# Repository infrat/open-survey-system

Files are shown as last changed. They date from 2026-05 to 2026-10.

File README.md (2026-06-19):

oss

# Open Survey System (OSS)

**Open, affordable GNSS RTK platform** that enables centimeter‑level positioning (~10 mm XY / ~50 mm Z) using commodity, readily available modules. OSS aims to democratize survey‑grade measurements by publishing open hardware, firmware, and reference configurations.

> **Status:** early draft - architecture overview only. Detailed BOMs, Gerbers, STLs, and configuration guides will be added later.

---

## 1) System Overview

OSS consists of two building blocks:

1. **RTK Rover** - a portable GNSS receiver that works with common mobile apps (e.g., SW Maps, Locus GIS, QField, SurPad, LandStar etc.). The rover receives RTK corrections via NTRIP over the Internet **or** from a local Wi‑Fi NTRIP caster.
2. **Extension Kit (LoRa)** - a radio bridge that carries RTK corrections over longer distances using LoRa (433 MHz), (eg. when local access to RTK corrections over LTE is not available):
   - **LTE/LoRa Gateway** - fetches RTK corrections from an online NTRIP service (e.g., a national CORS) or from a local RTK base, then transmits them via LoRa.
   - **LoRa/Wi‑Fi Gateway** - receives LoRa packets with RTCM and exposes a local NTRIP caster over a Wi‑Fi Access Point.
   - **Local RTK Base Station** _(optional)_ - provides local corrections based on its precisely known position (surveyed once or derived from long averaging).

---

## 2) High‑Level Architectures (Topologies)

### A) Internet‑only (no radio) - rover is used in an area with internet access to RTK corrections (eg. by LTE)

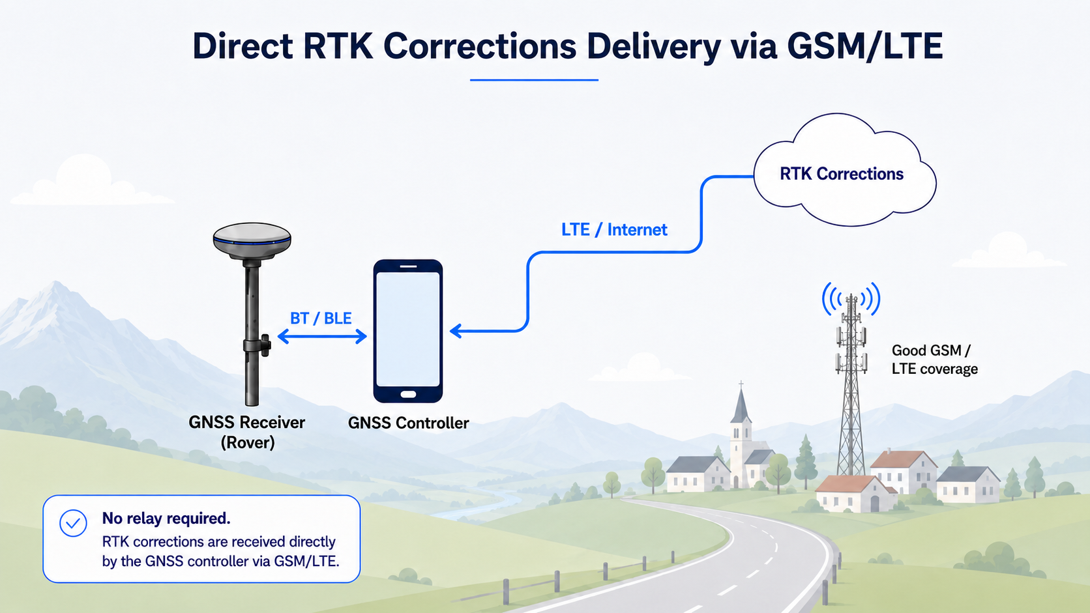
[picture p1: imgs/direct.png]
rover-only


### B) Radio‑relayed corrections (LoRa 433 MHz) - radio relay deployed in an area without internet access to RTK corrections network; corrections are calculated locally

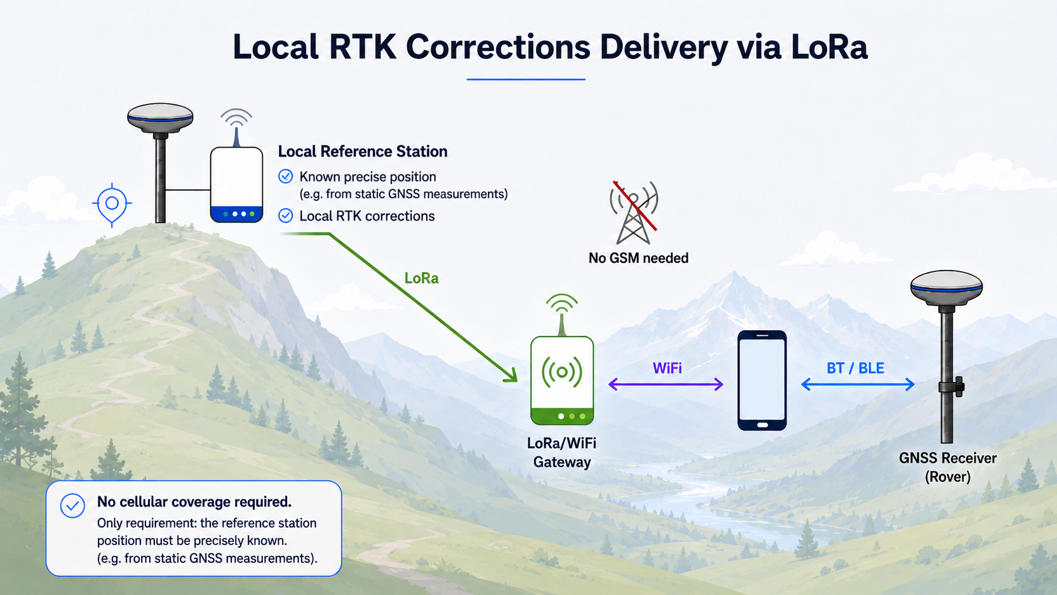
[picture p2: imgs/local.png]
rover-lora-base


### C) Hybrid (online source → local radio) - radio relay deployed in an area with internet access to RTK corrections network (over LTE/Starlink, etc.)

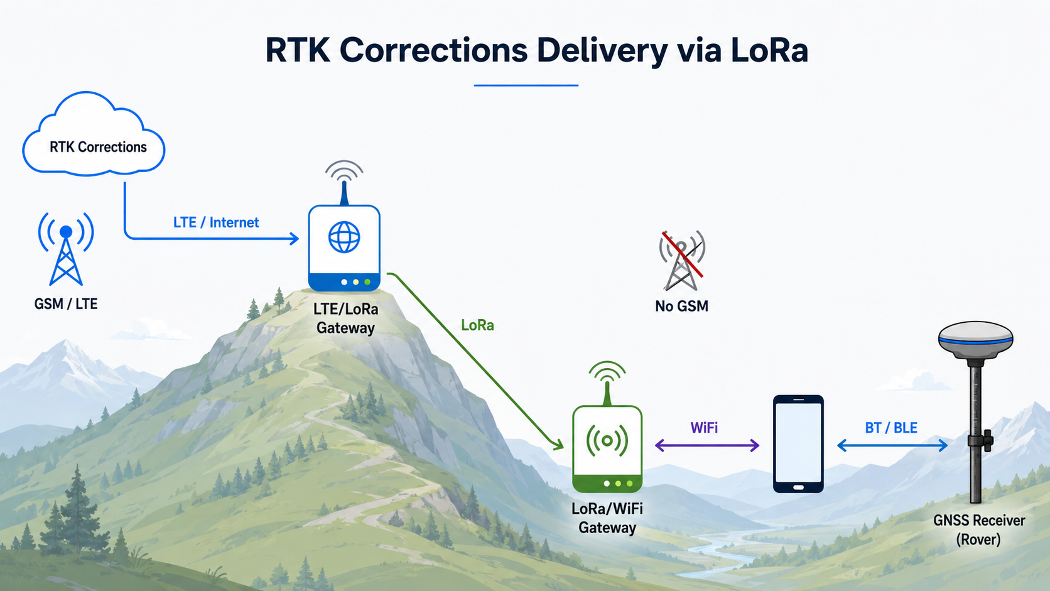
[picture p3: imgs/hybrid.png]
rover-lora


---

## 3) Component Roles

### RTK Rover

A compact, dual‑frequency GNSS RTK receiver that pairs with a mobile app. The app supplies RTK corrections (via Internet or a local NTRIP caster), while the rover provides position output to the app. Connectivity is kept simple (Bluetooth to the phone); no onboard Wi‑Fi or general‑purpose MCU is planned in the rover.

#### Enclosure

| | |
| --- | --- |
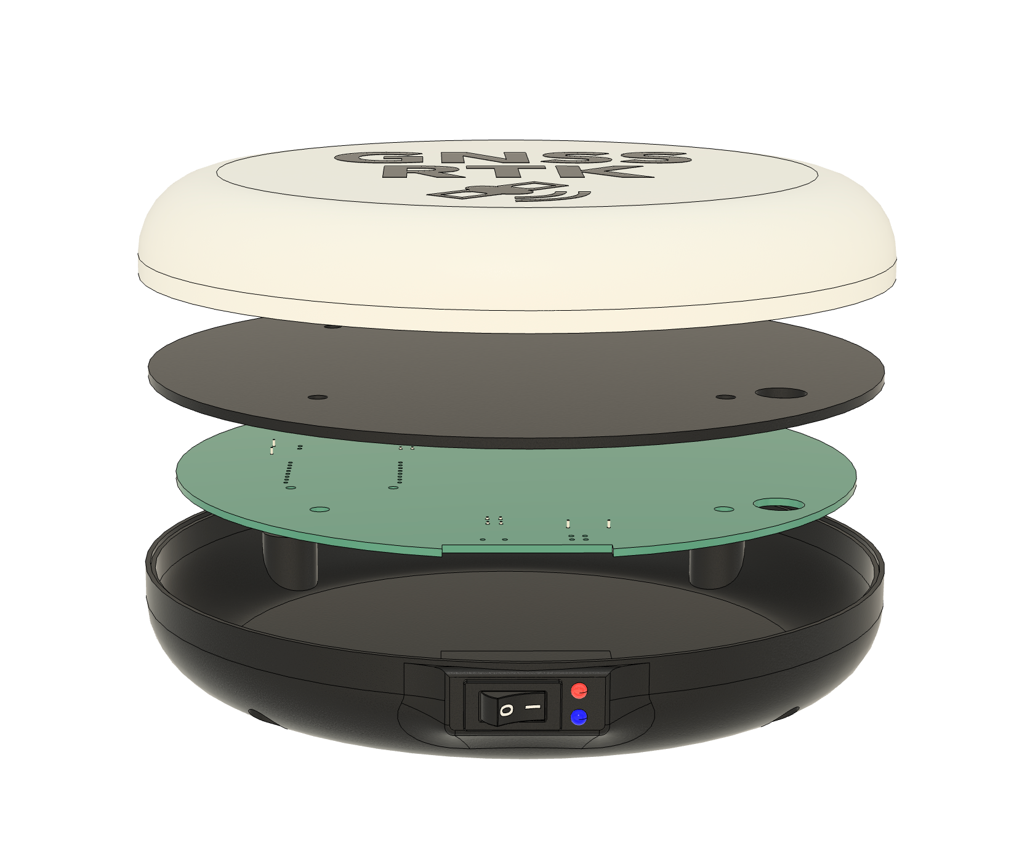
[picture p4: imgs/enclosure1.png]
enclosure1
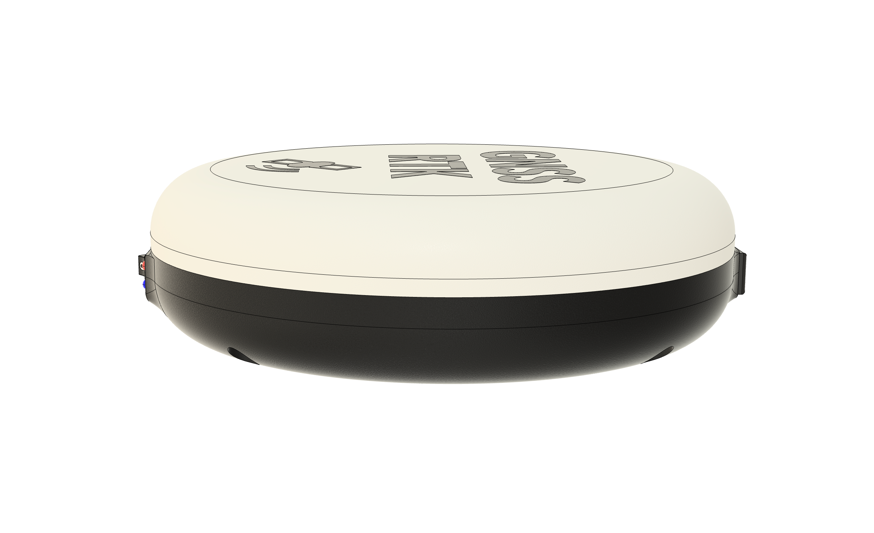
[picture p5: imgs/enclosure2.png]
enclosure2
|  |  |
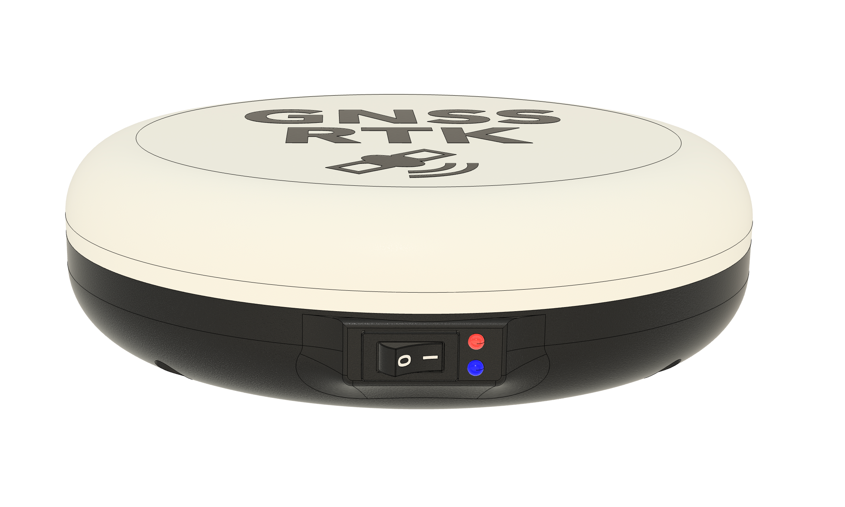
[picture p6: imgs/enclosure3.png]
enclosure3
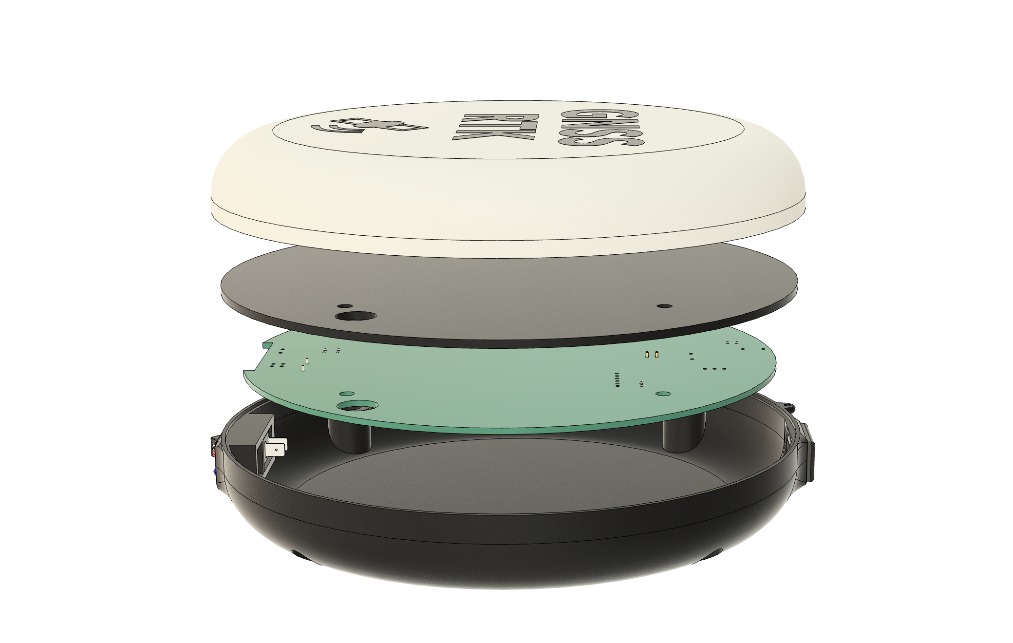
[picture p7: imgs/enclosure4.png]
enclosure4
|  |  |

#### Inside

| | |
| --- | --- |
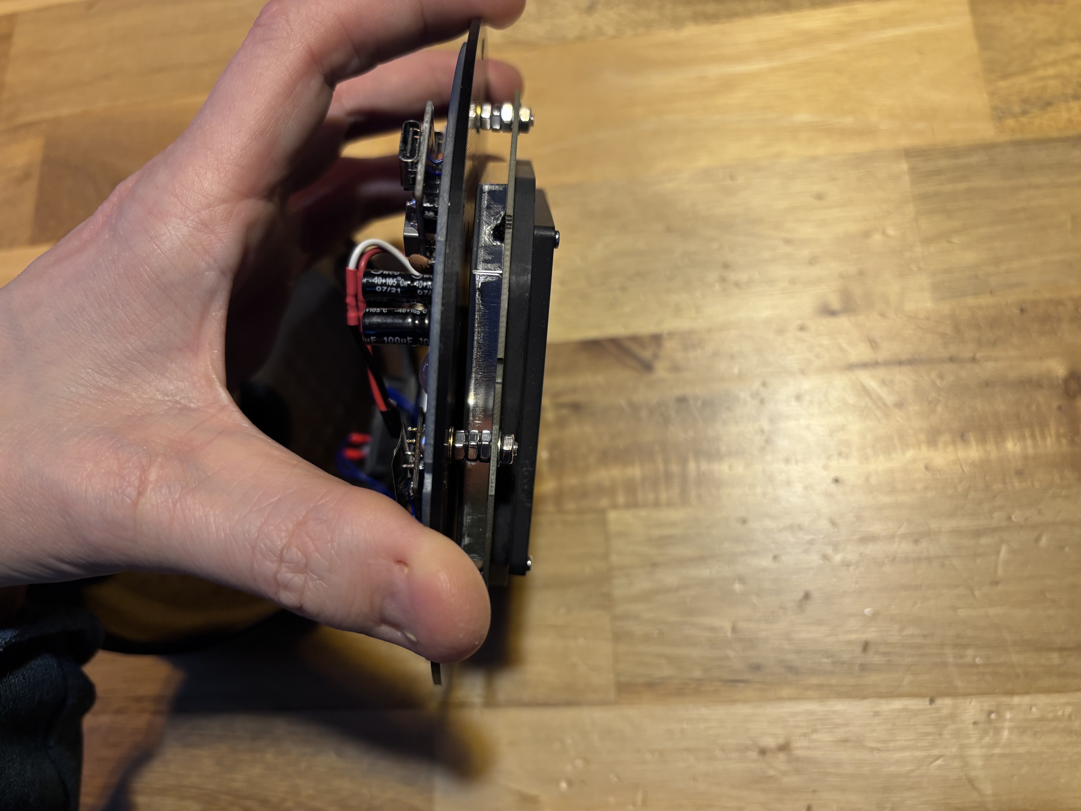
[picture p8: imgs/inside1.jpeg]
inside1
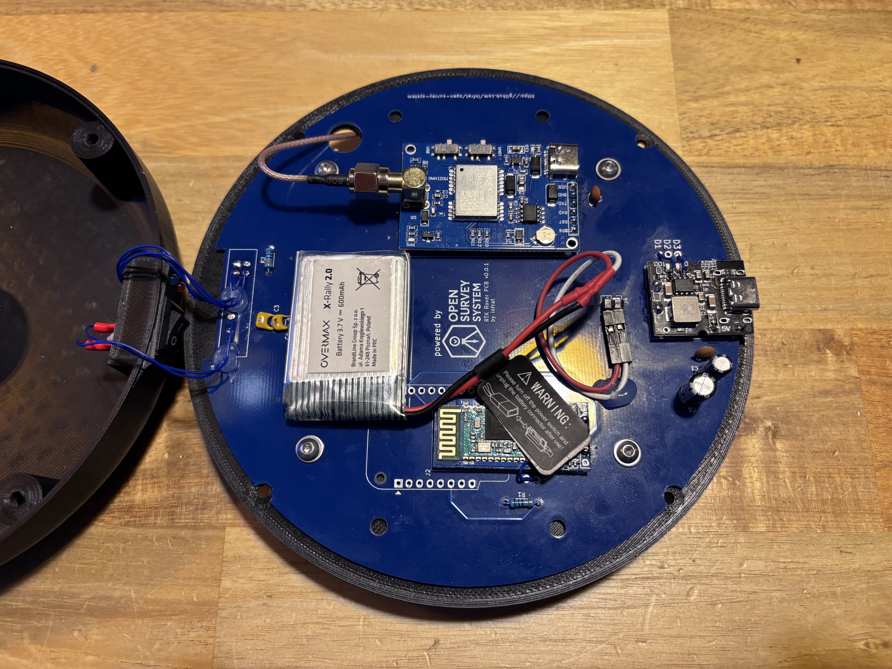
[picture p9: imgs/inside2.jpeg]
inside2
|  |  |

#### Outside

| | |
| --- | --- |
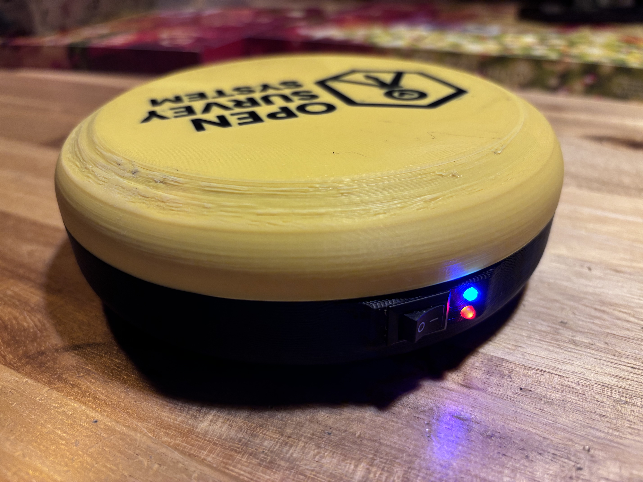
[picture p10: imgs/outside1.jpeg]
outside1
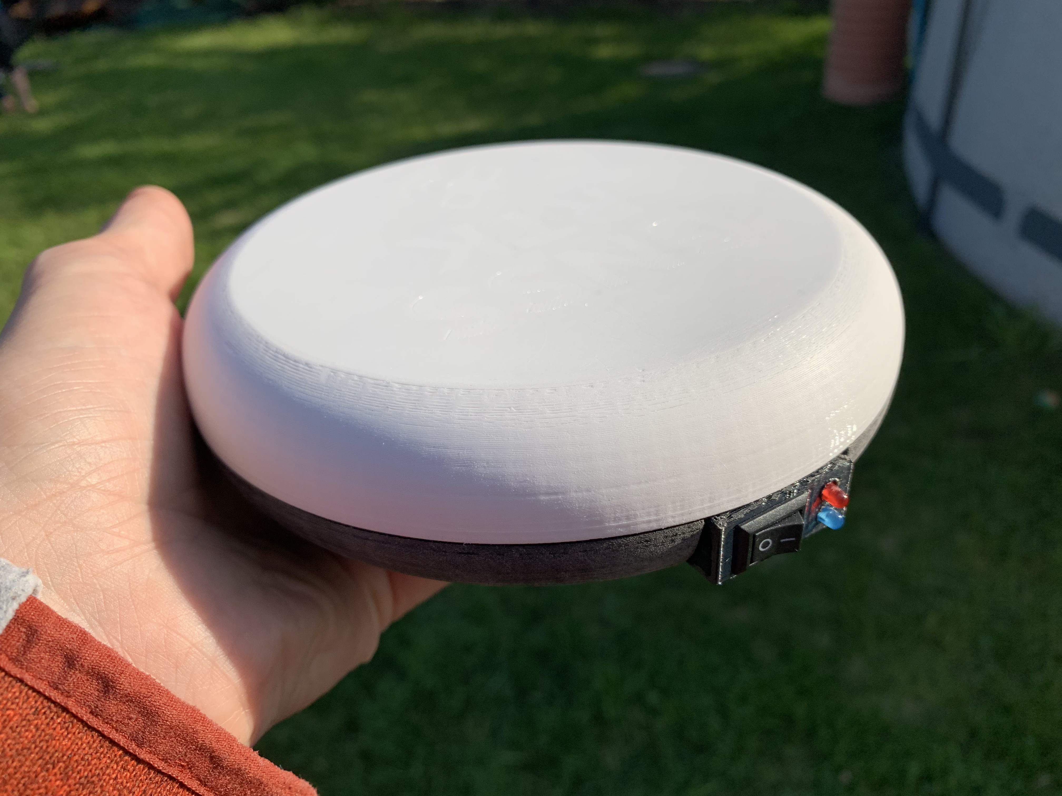
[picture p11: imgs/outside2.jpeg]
outside2
|  |  |

### LTE/LoRa Gateway (optional)

- Acts as an **NTRIP client** toward an online caster (e.g., CORS) **or** a local base station.
- **Encapsulates RTCM** and transmits over **LoRa 433 MHz (P2P)** to the LoRa/Wi‑Fi Gateway.

#### Photo

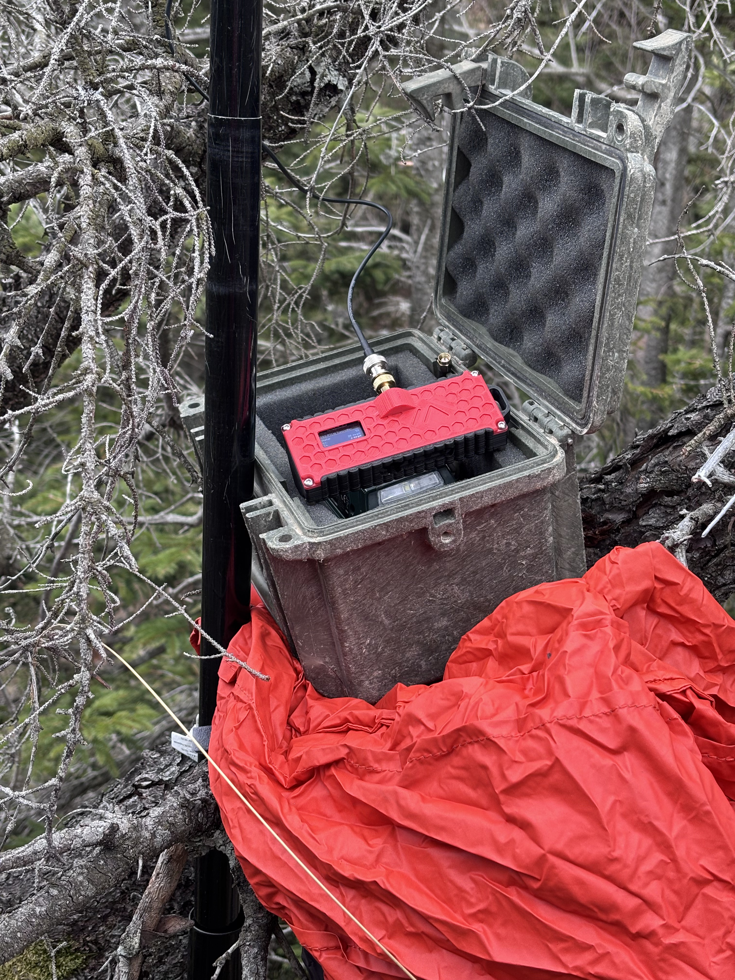
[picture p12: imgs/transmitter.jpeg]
transmitter


### LoRa/Wi‑Fi Gateway (optional)

- Receives **LoRa** packets and **reassembles RTCM** stream.
- Hosts a **local NTRIP caster** behind a Wi‑Fi **Access Point** for the rover/mobile app.

#### Photo

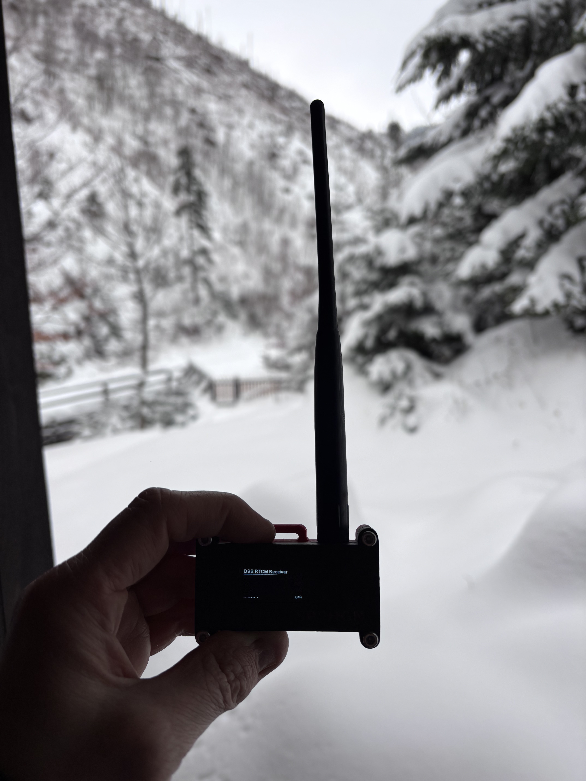
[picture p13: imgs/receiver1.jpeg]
receiver1


### Local RTK Base Station (optional)

- Provides **local RTCM** corrections from a fixed, accurately known position.
- Integrates with the LTE/LoRa Gateway to feed the radio uplink.

---

## 4) Data & Interfaces

- **Corrections:** RTCM 3.x over NTRIP (TCP/HTTP Basic).
- **Rover ↔ Phone link:** **Bluetooth SPP** (UART over BT using BT module, or BLE using ESP32).
- **Position output:** NMEA from rover to mobile apps.
- **Radio link:** LoRa 433 MHz, P2P mode (not LoRaWAN), optimized for low‑latency streaming.
- **Transport paths:**
  - Internet path: Mobile App (NTRIP client) → Online NTRIP Service → RTCM → **Bluetooth SPP** → Rover.
  - Radio path: Base or Online Service → LTE/LoRa Gateway → LoRa → LoRa/Wi‑Fi Gateway (NTRIP caster) → Mobile App → **Bluetooth SPP** → Rover.

---

## 5) Design Principles

- **Open & affordable:** publish hardware files (Gerbers), mechanical models (STL/STEP), firmware and configs.
- **Modular:** rover can operate standalone (Internet) or with the radio Extension Kit.
  > Extension Kit could be potentially used as a correction source to rovers from other manufacturers!
- **Interoperable:** works with mainstream mobile GIS apps.
- **Region‑aware:** radio operation must comply with local regulations (e.g., 433/869 MHz in EU).

---

## 6) Documentation

Component firmware and the shared, over-the-air specs are documented under `firmware/`:

### Shared specs (transmitter ↔ receiver)

The LoRa link is a contract between the two gateways, so its specs live in one canonical place — `firmware/shared/docs/` — and both firmwares must stay byte-compatible with them:

- [LoRa protocol](firmware/shared/docs/lora-protocol.md) - over-the-air packet format, fragmentation, radio parameters
- [Maintenance frame](firmware/shared/docs/maintenance-frame.md) - telemetry/maintenance and remote-command frames

### Transmitter (LTE/LoRa Gateway)

- [README](firmware/transmitter/README.md) - overview, hardware, quick start
- [Web UI config structure](firmware/transmitter/docs/config-structure.md) - configuration model and REST API
- [AGENTS.md](firmware/transmitter/AGENTS.md) - coding standards and workflow

### Receiver (LoRa/Wi‑Fi Gateway)

- [Architecture](firmware/receiver/docs/architecture.md) - task/core structure
- [Configuration](firmware/receiver/docs/configuration.md) - pins, timing, constants
- [NTRIP server](firmware/receiver/docs/ntrip-server.md) - local caster protocol flow
- [AGENTS.md](firmware/receiver/AGENTS.md) - coding standards and workflow

### Rover

- [README](firmware/rover/README.md) - overview and configuration

---

## 7) License

- Hardware: CERN OHL‑S v2 _(TBD)_
- Firmware/Software: Apache‑2.0 or MIT _(TBD)_
- Docs: CC‑BY‑4.0 _(TBD)_

---

### Notes

- Names and modules are placeholders for open, commonly available components.
- Rover = **GNSS RTK module + classic Bluetooth SPP module over UART**. Mobile app bridges NTRIP↔RTCM.
- This README intentionally omits implementation details; it is a high‑level map for the project structure and data flows.

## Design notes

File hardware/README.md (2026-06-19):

# OSS Hardware

Bill of Materials (BOM) and fabrication files for each building block of the
Open Survey System (OSS).

| Component | Role | BOM |
| --- | --- | --- |
| [Rover](rover/) | Portable GNSS RTK receiver (GNSS + BLE/SPP bridge) | [rover/BOM.md](rover/BOM.md) |
| [Transmitter](transmitter/) | LTE/LoRa Gateway — NTRIP client → LoRa 433 MHz uplink  | [transmitter/BOM.md](transmitter/BOM.md) |
| [Receiver](receiver/) | LoRa/Wi‑Fi Gateway — LoRa 433 MHz → local NTRIP caster | [receiver/BOM.md](receiver/BOM.md) |

## Notes on the BOMs

- **Rover** is a custom PCB. Its BOM is derived directly from the KiCad
  schematic in [`rover/kicad/rover.kicad_sch`](rover/kicad/rover.kicad_sch) and
  is the authoritative parts list. A machine-readable copy lives in
  [`rover/bom.csv`](rover/bom.csv).
- **Transmitter** and **Receiver** are built around commodity ESP32 + SX1276
  LoRa development boards (no custom PCB yet), so their BOMs list ready-made
  modules and the few external parts that complete the build.
- Prices are rough indications (USD) for low-volume hobby quantities and will
  vary by region and supplier. Treat them as planning estimates, not quotes.
- Region-aware radio note: 433 MHz operation must comply with local
  regulations (e.g. 433/869 MHz in the EU). Pick antennas/power accordingly.

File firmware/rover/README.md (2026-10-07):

# Open Survey System (OSS) - RTK Rover Firmware

**ESP32 Firmware for GNSS RTK Rover**

This is the main ESP32 firmware for the **Open Survey System (OSS)** - an open-source GNSS RTK rover designed for professional surveying and mapping applications. The firmware bridges the GNSS RTK receiver's UART to iOS/Android devices over **BLE** (Nordic UART Service, default), **Bluetooth Classic SPP** (Android only) or a raw **WiFi TCP** socket. The link and the WiFi settings are chosen in a built-in **web UI** - see [Setup and Web UI](#setup-and-web-ui).

## Project Overview

The **Open Survey System RTK Rover** consists of three main components:

1. **GNSS RTK Receiver**: Quectel LC29H DA (dual-antenna, multi-band RTK)
2. **ESP32 MCU**: Main controller running this firmware (Wemos D1 Mini32)
3. **Power Management Module**: Battery management and power distribution

This firmware handles:

- ✅ Real-time NMEA/RTCM data streaming via BLE Nordic UART Service (NUS), Bluetooth Classic SPP or WiFi TCP
- ✅ Bidirectional communication (corrections from mobile → GNSS)
- ✅ Web UI for choosing the link and configuring WiFi (AP / Station / AP + Station)
- ✅ Over-The-Air (OTA) updates of firmware and web UI via WiFi
- ✅ Status LED indication

## Setup and Web UI

### How the rover starts

WiFi and Bluetooth share a single radio and most of the ESP32's memory, so the rover never runs them together:

1. **Power-on → setup window.** Only WiFi is up, with the web UI, OTA and Telnet. The LED gives a short flash once per second.
2. **Nobody opens the web UI within the window (30 s by default)** → WiFi switches off and the Bluetooth link starts. No restart needed.
3. **Someone is using the web UI** → the rover stays in setup mode. Close the page or press **Start Bluetooth now** to finish.

Only real use keeps WiFi on: an open and recently used web UI page, an OTA transfer or a Telnet session. A phone that merely joins the rover's WiFi does not. To get WiFi back, restart the rover.

With the **WiFi (TCP)** link there is no Bluetooth: WiFi stays on and the data link is available right after boot.

### Reaching the web UI

- On your network: `http://ossrtk.local` (or the rover's IP address)
- On the rover's own access point `OSSRTK-XXXX`: `http://192.168.4.1`

The UI has three tabs:

| Tab | What it does |
| --- | --- |
| **Status** | Active link, client connection, WiFi addresses, time left in the setup window, firmware, heap |
| **Connection** | Choose Bluetooth LE, Bluetooth SPP or WiFi (TCP) and the TCP port |
| **WiFi** | Access point / Station / AP + Station, network scan, credentials, setup window length |

**Save & Restart** stores the settings in flash (NVS) and reboots the rover.

### Screenshots

The web UI is a single responsive page, designed for a phone screen.

**Status** - during the setup window (Bluetooth waits until the page is closed or **Start Bluetooth now** is pressed) and once a client has connected:

| | |
| --- | --- |
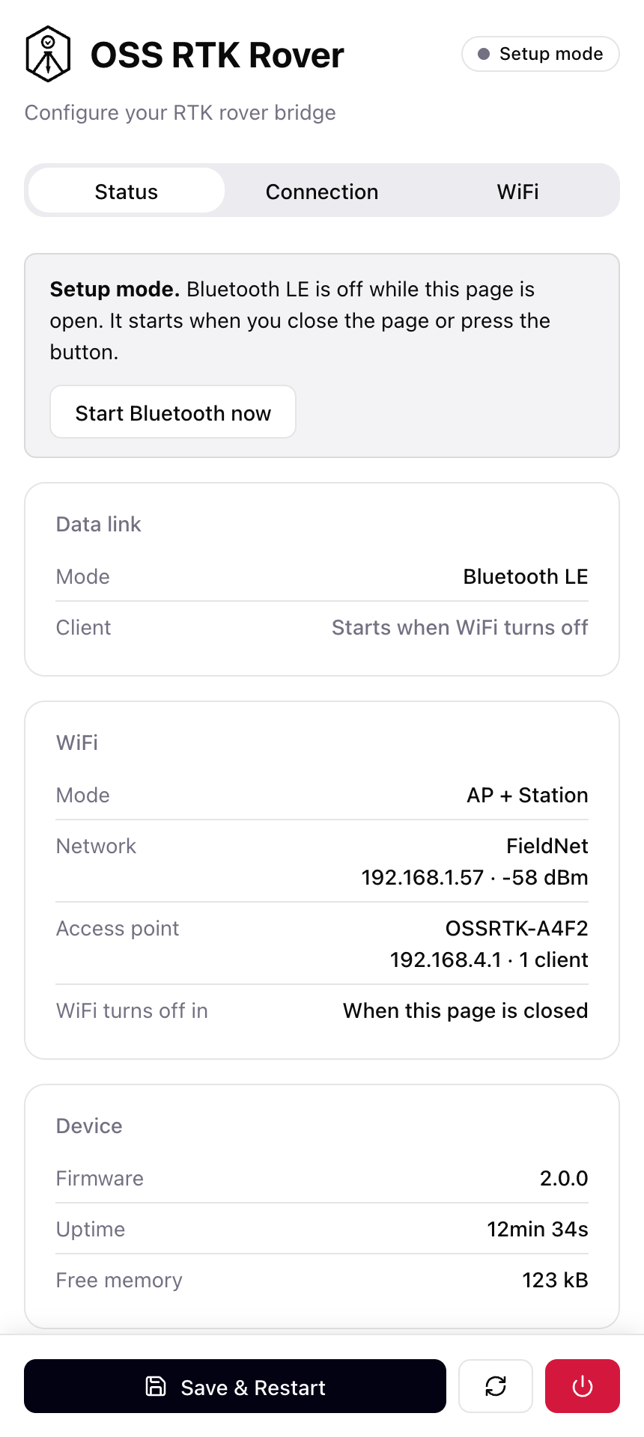
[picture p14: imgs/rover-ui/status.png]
Status - setup mode
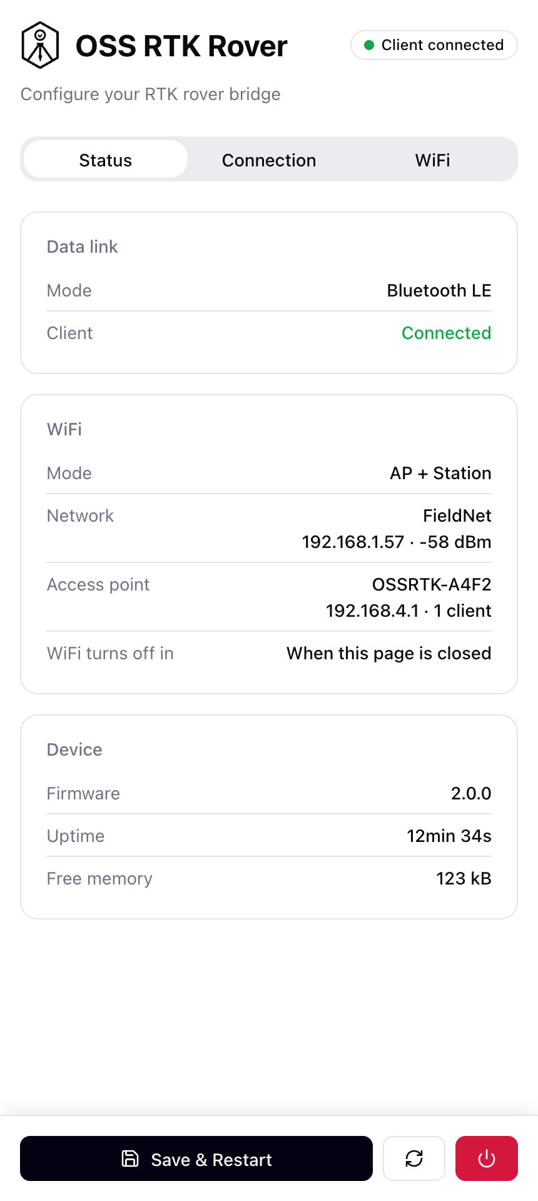
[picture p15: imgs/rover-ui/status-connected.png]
Status - client connected
|  |  |

**Connection** - choose the client link; the TCP port and the addresses to point your app at appear for the WiFi (TCP) link:

| | |
| --- | --- |
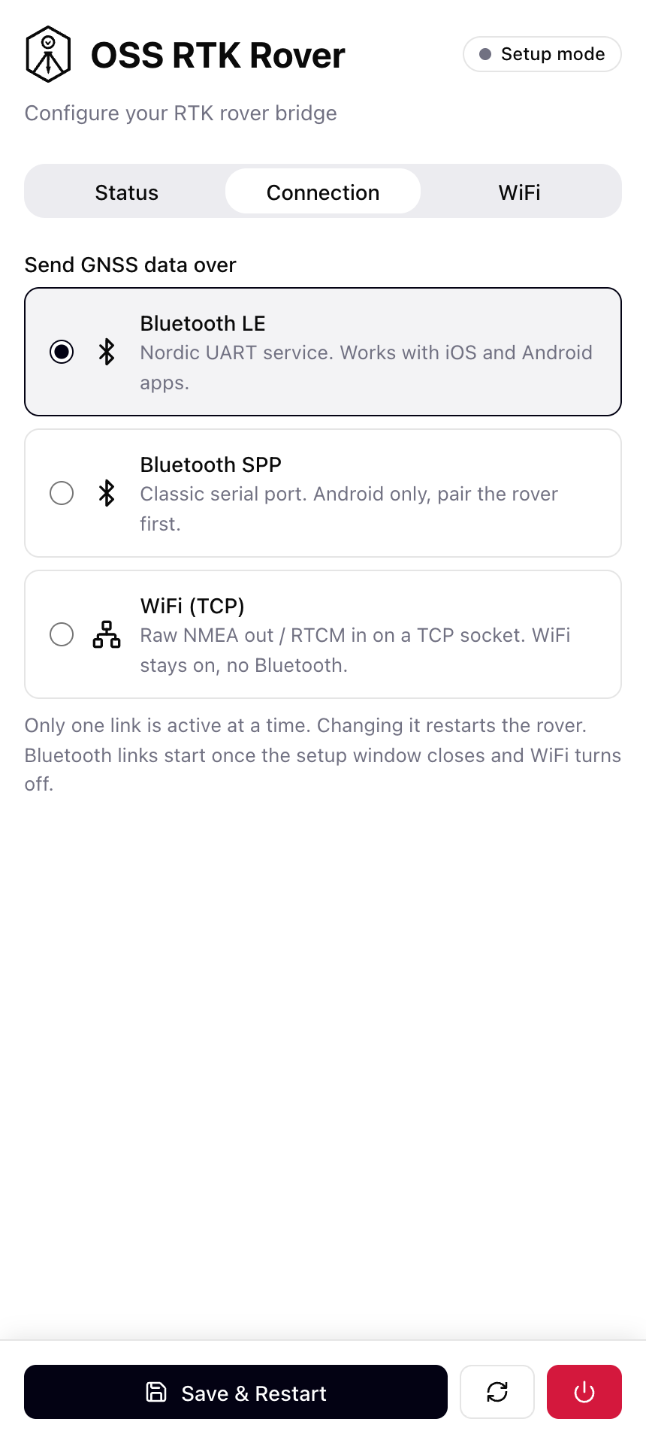
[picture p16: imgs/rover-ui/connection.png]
Connection - Bluetooth LE
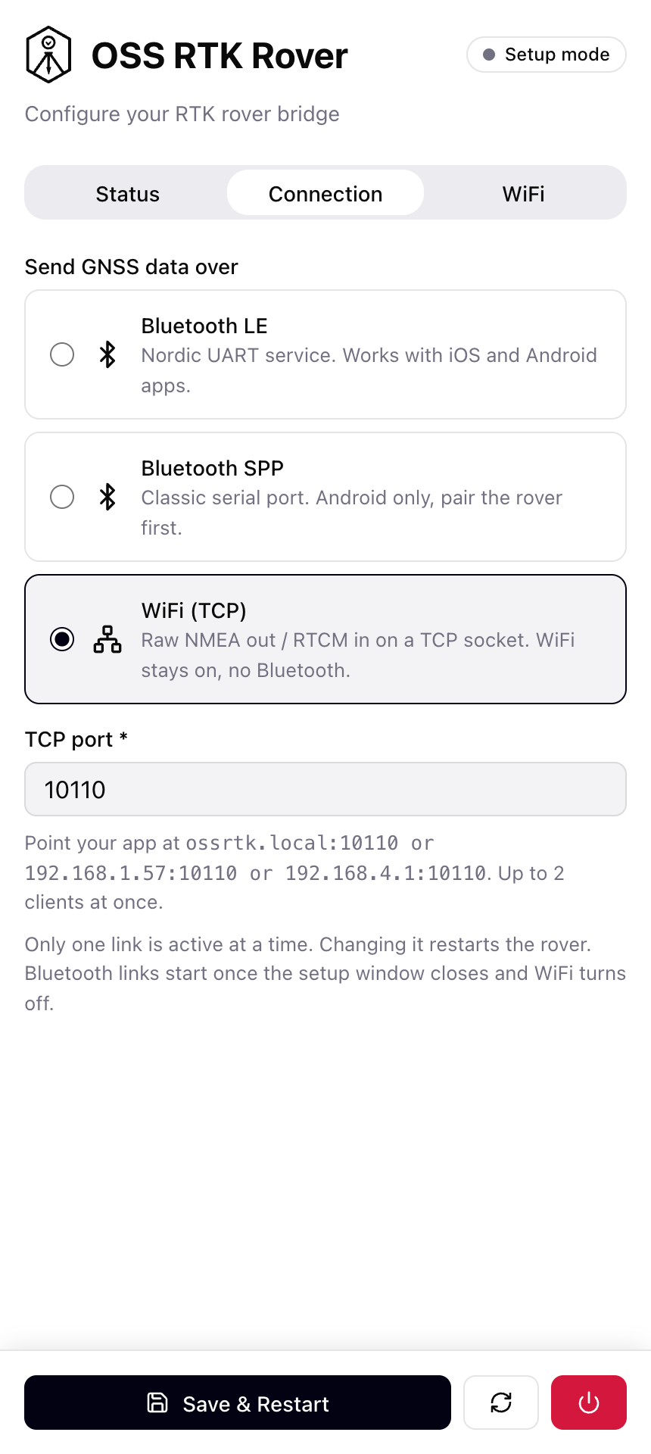
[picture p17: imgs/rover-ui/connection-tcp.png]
Connection - WiFi TCP
|  |  |

**WiFi** - mode, network credentials, the rover's own access point and the setup window length; the scan button lists nearby networks:

| | |
| --- | --- |
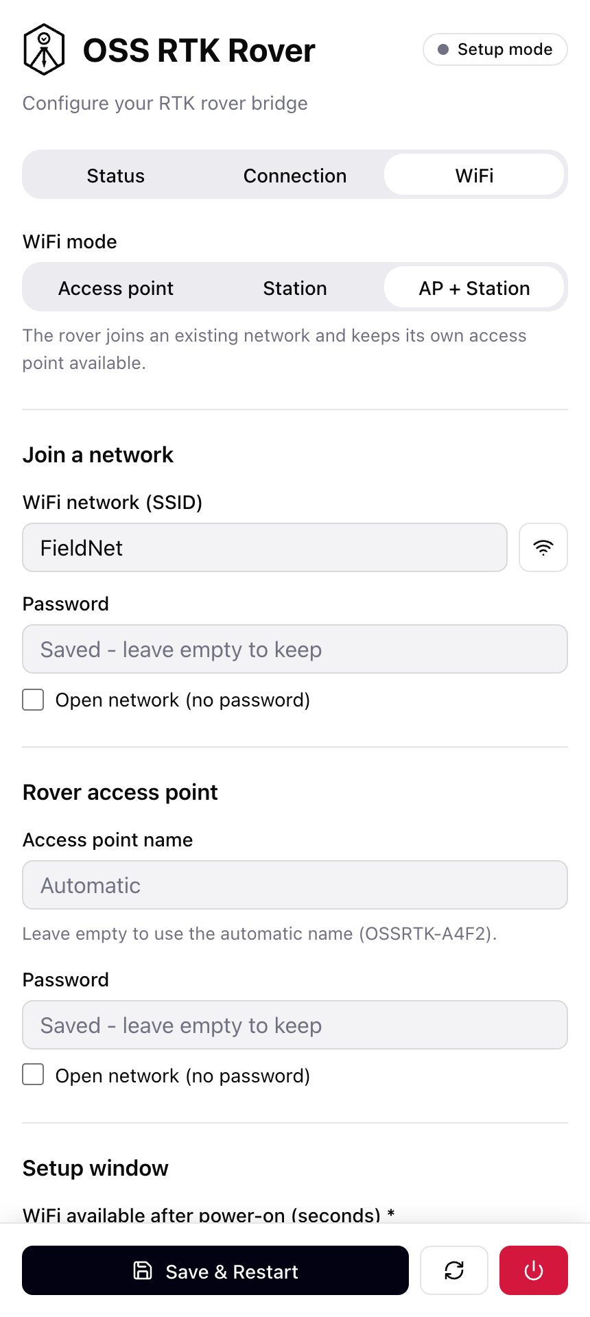
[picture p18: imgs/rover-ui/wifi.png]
WiFi settings
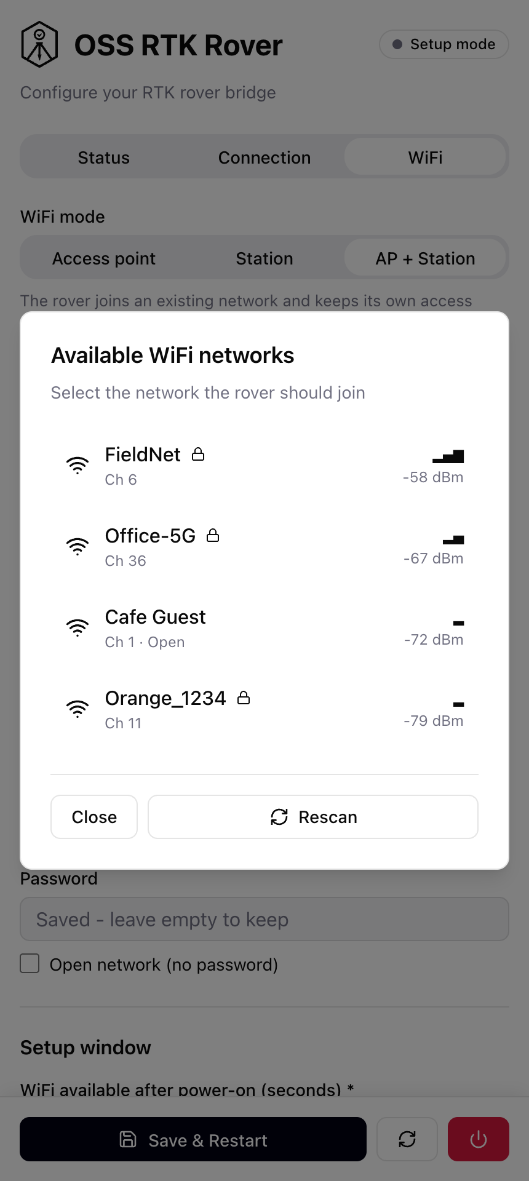
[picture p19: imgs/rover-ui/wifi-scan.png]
WiFi network scan
|  |  |

### Client links

| Link | iOS | Android | Notes |
| --- | --- | --- | --- |
| Bluetooth LE (default) | ✅  | ✅ | Nordic UART Service, 185B MTU |
| Bluetooth SPP | ❌  | ✅ | Plain serial stream, pair with `OSSRTK` first |
| WiFi (TCP) | ✅  | ✅ | `ossrtk.local:10110` by default, up to 2 clients, WiFi stays on |

**⚠️ iOS cannot use SPP.** Bluetooth Classic SPP is not available to third-party iOS apps without MFi certification.

### WiFi modes

| Mode | Behavior |
| --- | --- |
| Access point | The rover creates its own network `OSSRTK-XXXX` (open unless you set a password) |
| Station | The rover joins your network |
| AP + Station (default) | Both at once |

If the rover cannot join the configured network within 10 seconds, it falls back to its own access point so the web UI stays reachable.

**⚠️ The web UI has no login and the default access point is open.** Set an access point password before using the rover around other people.

Adding a new link means implementing `ITransport` (see `src/transport.h`) and adding a branch to `src/transport_factory.cpp`.

## Hardware Components

## UART Pinout (ESP32 ↔ LC29H DA)

```
LC29H DA (GNSS)     ESP32 (Wemos D1 Mini32)
---------------     -----------------------
VCC_IN (3.3-5V) --> 3.3V (via power module)
GND             --> GND
UART1_TX        --> GPIO25 (RX - GNSS data to ESP32)
UART1_RX        <-- GPIO27 (TX - corrections to GNSS)
```

**UART Configuration:**

- Baud Rate: 115200
- Data: 8N1 (8 bits, no parity, 1 stop bit)
- Flow Control: None

## Power Saving

### WiFi setup window

- WiFi is only on during the setup window after power-on (30 s by default, 15-600 s in the web UI), then it is switched off
- With the WiFi (TCP) link WiFi stays on permanently and the rover draws correspondingly more

### Bluetooth low power mode

- TX Power: **-9dBm** (`BLE_TX_POWER` / `SPP_TX_POWER`)
- Range: ~10-15m (sufficient for rover-to-mobile)
- Bluetooth Classic (SPP) draws noticeably more than BLE

Current draw has not been re-measured for this firmware revision.

## Mobile App Compatibility

### Recommended iOS Apps (Bluetooth LE or WiFi TCP link)

1. **Lefebure NTRIP Client** - Professional RTK/NTRIP app
2. **SW Maps** - Survey and mapping with NTRIP support
3. **nRF Toolbox** (Nordic) - Testing NUS connection

### Android Apps (any link)

1. **Lefebure NTRIP Client**
2. **Mobile Topographer**
3. **Serial Bluetooth Terminal** - works with the SPP link (pair first) and with the BLE link in BLE mode

## Building and Uploading

Run the commands from the repository root. `oss-rover-usb` flashes over serial, `oss-rover` over WiFi - both build the same image.

### First Upload (via USB)

```bash
# Firmware
pio run -e oss-rover-usb -t upload

# Web UI files (LittleFS)
pio run -e oss-rover-usb -t uploadfs

# Monitor serial output
pio device monitor
```

A USB flash is also needed when upgrading from a firmware older than 2.0.0, because the partition table changed.

### OTA Updates (via WiFi)

```bash
pio run -e oss-rover -t upload      # firmware -> ossrtk.local
pio run -e oss-rover -t uploadfs    # web UI
# OTA password: admin (configurable in config.h)
```

**Important**: OTA only works during the setup window after power-on.

1. Restart the rover
2. Open `http://ossrtk.local` - an open web UI page keeps WiFi on
3. Run the upload
4. Close the page or press **Start Bluetooth now** when done

## Configuration

Day-to-day settings (client link, TCP port, WiFi mode and credentials, setup window length) are changed in the **web UI** and stored in flash. `include/config.h` holds the compile-time parameters and the factory defaults:

### UART Settings (GNSS)

```cpp
#define GPS_RX_PIN 25           // GNSS TX → ESP32 RX
#define GPS_TX_PIN 27           // ESP32 TX → GNSS RX
#define GPS_BAUD_RATE 115200    // LC29H DA baud rate
#define UART_BUF_SIZE 1024      // UART buffer (1KB)
```

### WiFi/OTA Settings (factory defaults)

```cpp
#define DEFAULT_TRANSPORT_MODE 0       // 0 = BLE, 1 = Bluetooth SPP, 2 = WiFi TCP
#define DEFAULT_WIFI_MODE 2            // 0 = AP, 1 = STA, 2 = AP+STA
#define DEFAULT_SETUP_WINDOW_SEC 30    // WiFi-only setup window after boot
#define WIFI_SSID "YourNetwork"        // default network to join
#define WIFI_PASSWORD "YourPassword"
#define OTA_HOSTNAME "ossrtk"          // ossrtk.local
#define OTA_PASSWORD "admin"
#define TCP_PORT_DEFAULT 10110         // NMEA-0183 over TCP
```

### Power Saving

```cpp
#define BLE_TX_POWER ESP_PWR_LVL_N9    // -9dBm (low power, BLE)
#define SPP_TX_POWER ESP_PWR_LVL_N9    // -9dBm (low power, SPP)
```

### Bluetooth Settings

```cpp
#define BT_DEVICE_NAME "OSSRTK"        // BLE scanner name / BT pairing name

// BLE link only:
#define BLE_MTU_SIZE 185               // iOS max MTU
#define BLE_CHUNK_SIZE 180             // Chunk size for large packets
```

### Status LED

```cpp
#define LINK_STATUS_LED_PIN 23         // GPIO23 (active HIGH)
#define LINK_LED_BLINK_MS 250          // Blink period when disconnected
```

## Nordic UART Service (NUS) UUIDs

The firmware implements the standard Nordic UART Service for maximum compatibility:

```
Service UUID:  6E400001-B5A3-F393-E0A9-E50E24DCCA9E
RX Char UUID:  6E400002-B5A3-F393-E0A9-E50E24DCCA9E  (Mobile → ESP32 → GNSS)
TX Char UUID:  6E400003-B5A3-F393-E0A9-E50E24DCCA9E  (GNSS → ESP32 → Mobile)
```

## Debugging and Monitoring

### Serial Monitor (USB - 115200 baud)

```
========================================
OSS RTK Rover 2.0.0
GPS (NMEA) ↔ UART bridge
========================================

[Setup] Transport: BLE, WiFi mode: sta, setup window: 30 s
[WiFi] Connecting to "YourNetwork"...
[WiFi] Setup window: off after 30 s without web UI / OTA / Telnet use
[Web] UI on port 80
[UART] Initialized GPS UART
[UART] RX: GPIO25, TX: GPIO27, Baud: 115200
[Setup] Setup window open: WiFi only, BLE starts when it closes
[OTA] Ready for firmware updates
[Telnet] Server started on port 23
...
[WiFi] Setup window closed - switching WiFi off
[Setup] Initializing BLE...
[BLE] Nordic UART Service started
[BLE] Device name: OSSRTK
Waiting for GPS data and client connection...
```

The same log is available over Telnet (`telnet ossrtk.local`) during the setup window.

**Data Flow:**

- **TX (ESP32 → Mobile)**: NMEA sentences, RTCM corrections status
- **RX (Mobile → ESP32)**: RTCM corrections from NTRIP caster

### Status LED Patterns

| Pattern | Status |
| --- | --- |
| **Short flash every 1s**  | Setup window: WiFi only, link not started yet |
| **Blinking (250ms)** | Waiting for a mobile connection |
| **Solid ON** | Mobile device connected |
| **Fast blinking (100ms)** | Error - UART init failed |
| **Fast blinking (200ms)** | Error - transport (BLE/SPP) init failed |

## Troubleshooting

### No GNSS Data Received

**Check UART connection:**

```
LC29H DA TX (pin 5) → ESP32 GPIO25 (RX)
LC29H DA RX (pin 4) → ESP32 GPIO27 (TX)
```

**Verify in Serial Monitor:**

- Look for `[UART] Initialized GPS UART`
- Should see `[Bridge] UART → BLE: XX bytes` (or SPP/TCP) when GNSS is outputting data, once the link has started

**LC29H DA Configuration:**

- Default baud: 115200 (some modules ship at 9600 - check datasheet)
- Output rate: 1Hz or higher
- NMEA messages: GGA, RMC, GSA, GSV (minimum)

### Mobile App Can't Connect

**Wait for the setup window to end.** For the first 30 seconds after power-on (or as long as the web UI is open) only WiFi is running and the rover is not visible over Bluetooth. The LED switches from a short flash every second to an even blink when the link is up.

**Verify the link is running:**

- Bluetooth LE: serial log shows `[BLE] Nordic UART Service started`
- Bluetooth SPP: serial log shows `[SPP] Serial Port Profile server started`
- Device name: `OSSRTK`

**On mobile device (Bluetooth LE):**

1. Enable Bluetooth
2. Scan for `OSSRTK`
3. Connect (should see `[BLE] Device connected!` in logs)
4. LED should become solid ON

**On mobile device (Bluetooth SPP, Android):**

1. Pair with `OSSRTK` in the Android Bluetooth settings first
2. Open the serial port from the app (should see `[SPP] Client connected!` in logs)
3. LED should become solid ON

If an iPhone cannot see or connect to the rover, check which link is selected in the web UI - SPP is invisible to iOS apps.

**Use BLE Scanner app** to verify device is advertising with correct UUIDs

### No RTK Fix / Low Accuracy

**This is NOT a firmware issue** - check GNSS configuration:

- GNSS has clear sky view (no multipath/obstructions)
- RTCM corrections are being received (check mobile app)
- Corrections match GNSS constellation (GPS/GLO/GAL/BDS)
- Base station <40km away for RTK
- Wait 30-120s for RTK convergence

### Web UI Not Reachable

- WiFi is only on during the setup window. Restart the rover and open the page within 30 seconds.
- If the rover cannot join your network, it opens its own access point `OSSRTK-XXXX` after about 10 seconds; connect to it and open `http://192.168.4.1`.
- If the page shows "Web UI files not found", upload the filesystem: `pio run -e oss-rover-usb -t uploadfs`.

### OTA Update Failed

- Start the upload inside the setup window; the easiest way is to keep the web UI open while uploading.
- Check `ossrtk.local` is reachable: `ping ossrtk.local`
- Check the firewall isn't blocking mDNS/port 3232
- Use the IP address instead: `upload_port = 192.168.1.100`

## Example NMEA/RTCM Data

### NMEA Output (LC29H DA → Mobile)

```
$GNGGA,083559.00,5015.12345,N,01945.67890,E,4,24,0.6,123.4,M,45.2,M,1.2,0138*6F
$GNRMC,083559.00,A,5015.12345,N,01945.67890,E,0.012,,101224,,,D*7A
$GNGSA,A,3,01,03,06,09,14,17,19,22,,,,,1.2,0.6,1.0*3C
```

### RTCM Corrections (Mobile → LC29H DA)

```
Binary RTCM3 messages (e.g., 1005, 1077, 1087, 1097, 1127)
Sent from NTRIP caster via mobile app through BLE
```

## Project Structure

```
firmware/rover/
├── include/
│   └── config.h                 # Compile-time parameters and factory defaults
├── data/                        # Web UI (index.html, style.css, app.js) -> LittleFS
├── partitions.csv               # 2 x 1.81MB OTA slots + 256KB LittleFS
├── src/
│   ├── main.cpp                 # Setup + loop, setup window -> link hand-over
│   ├── settings.cpp/h           # Runtime settings, stored in NVS
│   ├── wifi_manager.cpp/h       # AP / STA / AP+STA, setup window
│   ├── web_server.cpp/h         # Web UI + REST API
│   ├── ota_service.cpp/h        # ArduinoOTA + mDNS
│   ├── telnet_service.cpp/h     # Remote log console
│   ├── logger.cpp/h             # Serial + Telnet logging
│   ├── system_control.cpp/h     # Deferred restart
│   ├── bridge.cpp/h             # GNSS UART <-> link, status LED
│   ├── uart_handler.cpp/h       # UART communication with LC29H DA
│   ├── transport.h              # ITransport interface
│   ├── transport_factory.cpp/h  # Creates the link selected in settings
│   ├── ble_uart_service.cpp/h   # BLE NUS (Bluedroid)
│   ├── spp_serial_service.cpp/h # Bluetooth Classic SPP (Bluedroid)
│   └── tcp_transport.cpp/h      # Raw TCP server
├── platformio.ini               # Standalone PlatformIO configuration
└── README.md                    # This file
```

## Dependencies

- **Platform**: Espressif32 (PlatformIO)
- **Framework**: Arduino
- **Libraries**:
  - `ESPAsyncWebServer` 3.7.10 + `AsyncTCP` 3.4.10 (ESP32Async) - web UI and REST API
  - `ArduinoJson` 6.21.6
  - Framework-bundled: BLE, BluetoothSerial (both Bluedroid), WiFi, LittleFS, Preferences, ESPmDNS, ArduinoOTA

## Technical Specifications

| Parameter | Value |
| --- | --- |
| **UART Speed** | 115200 baud |
| **Client link** | BLE NUS (default), BT Classic SPP or WiFi TCP |
| **BLE Range** | ~10-15m (-9dBm TX power) |
| **BLE MTU** | 185 bytes (iOS max) |
| **Data Chunk Size** | 180 bytes (BLE packet); SPP/TCP unchunked |
| **WiFi** | Setup window after boot (default 30 s) |
| **Flash Usage** | ~1.76MB of a 1.81MB app slot (4MB flash) |
| **Free heap** | ~125KB in the setup window |

## Contributing

This is part of the **Open Survey System** project. Contributions welcome!

- Report issues on GitHub
- Submit pull requests for improvements
- Share your rover builds and field tests

## License

MIT License - Free for personal and commercial use

## Acknowledgments

- **Nordic Semiconductor** - Nordic UART Service specification
- **Espressif Systems** - ESP32 platform
- **Quectel** - LC29H DA GNSS module documentation
- **Open Survey System Community** - Testing and feedback

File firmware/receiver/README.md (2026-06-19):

# OSS RTCM Receiver

ESP32 + SX1276 LoRa → NTRIP gateway that turns long-range RTCM corrections into a local caster for GNSS rovers.





OSS RTCM Receiver

## Overview

Open Source Surveying Receiver is an ESP32 firmware that acts as the field-side counterpart of the [OSS Transmitter](../transmitter/README.md). It receives RTCM3 corrections over a 433.7 MHz LoRa link, reassembles fragmented messages, validates them, and re-serves them to nearby GNSS rovers through a local NTRIP caster over its own WiFi access point — no internet connection required in the field.

### Key Features

- **LoRa Receiver** - 433.7 MHz reception with fragment reassembly
- **RTCM Parser** - RTCM3 frame parsing with CRC-24Q validation
- **NTRIP Caster** - Local TCP caster serving the `LORA` mount point
- **WiFi Access Point** - Self-hosted hotspot for rovers (no internet needed)
- **OLED Display** - Real-time RX statistics and client count
- **Buzzer Feedback** - Audible pulse on every valid RTCM frame
- **Dual-Core Design** - Time-critical radio isolated from network/UI work

## Use Cases

- **RTK Surveying** - Deliver base corrections to rovers where cellular/internet is unavailable
- **Precision Agriculture** - Local correction relay for autonomous machinery

## Hardware

### Required

- **TTGO LoRa32 V2.1** (ESP32 + SX1276 + SSD1306 OLED)
- **433/444 MHz LoRa Antenna** (recommended: dipole/yagi for range)
- **Power Supply** - USB-C or 18650 Li-Ion (3.7V)

### SX1276 Pinout (TTGO LoRa32 V2.1)

```
NSS   → GPIO 18
MOSI  → GPIO 27
MISO  → GPIO 19
SCK   → GPIO 5
RST   → GPIO 14
DIO0  → GPIO 26
```

### OLED Display

- **Type**: SSD1306 128x64
- **I2C**: GPIO 21 (SDA), GPIO 22 (SCL), GPIO 16 (RST)

### Buzzer

- **Pin**: GPIO 4 (non-blocking pulse on valid RTCM frame)

## Quick Start

### 1. Environment Setup

```bash
# Install PlatformIO
pip install platformio

# Clone repository
git clone <repo-url>
cd gnss-rtk-toolset/firmware/receiver
```

### 2. Basic Configuration

All compile-time settings live in [include/config.h](include/config.h). The defaults work out of the box for a paired transmitter:

```cpp
// WiFi Access Point
#define WIFI_SSID "OSS-LoRa-RX"
#define WIFI_PASSWORD "lora123456"   // change before any real deployment

// NTRIP Caster
#define NTRIP_PORT 2101
#define NTRIP_MOUNT_POINT "LORA"
#define NTRIP_MAX_CLIENTS 4

// LoRa Radio (must match the transmitter)
#define LORA_FREQUENCY 433700000
#define LORA_SPREADING_FACTOR 7
#define LORA_BANDWIDTH 500E3
#define LORA_TX_POWER 20
```

> ⚠️ The LoRa radio parameters must be identical to the transmitter or the link fails silently.

### 3. Build and Upload

```bash
# Build firmware
pio run -e ttgo-lora32-v21

# Upload to device
pio run -e ttgo-lora32-v21 -t upload

# Monitor serial output
pio device monitor --baud 115200
```

### 4. Connect a Rover

1. On the rover/phone, join the WiFi network `OSS-LoRa-RX` (password `lora123456`).
2. Point an NTRIP client at the caster:
   - **Host**: `192.168.4.1`
   - **Port**: `2101`
   - **Mount point**: `LORA`
   - **Auth**: none
3. The rover starts receiving RTCM and converges to an RTK fix.

## LoRa Protocol

The receiver stays byte-compatible with the transmitter's packet format.

### Packet Structure (Protocol v2)

```
┌────────────┬────────────┬───────────────┬──────────────┬─────────────┬──────────────────┐
│ Frame Type │ Message ID │ Total Packets │ Packet Index │ Data Length │      Data        │
│  (1 byte)  │  (1 byte)  │   (1 byte)    │   (1 byte)   │  (1 byte)   │  (0-245 bytes)   │
└────────────┴────────────┴───────────────┴──────────────┴─────────────┴──────────────────┘
```

| Frame Type | Value  | Direction | Purpose |
| --- | --- | --- | --- |
| `FRAME_RTCM` | `0x01` | TX → air | RTCM correction data |
| `FRAME_MAINTENANCE` | `0x02` | TX → air | Telemetry broadcast  |
| `FRAME_COMMAND` | `0x03` | RX → transmitter | Control command |
| `FRAME_ACK` | `0x04` | optional | Acknowledgement |

### Reception Parameters

- **Frequency**: 433.7 MHz (`433700000`)
- **Spreading Factor**: 7
- **Bandwidth**: 500 kHz
- **Coding Rate**: 4/5
- **Sync Word**: 0x12
- **Header size**: 5 bytes
- **Max data per packet**: 245 bytes
- **Reassembly buffer**: 16 KB

Incomplete multi-packet messages are dropped after `PACKET_TIMEOUT` (5 s). See [docs/lora-protocol.md](docs/lora-protocol.md) and the shared spec in [../shared/docs/lora-protocol.md](../shared/docs/lora-protocol.md) for the full specification.

## System Architecture

### Dual-Core Design

The firmware runs two FreeRTOS tasks pinned to separate cores so radio reception is never starved by network or UI work.

```
Core 1 (loraTask, prio 2)            Core 0 (networkTask, prio 1)
─────────────────────────            ────────────────────────────
checkForPackets()  (SPI)             xQueueReceive(rtcmQueue)
onReceive() → reassembly             broadcastRTCMData() → clients
processRTCMData()                    handleNTRIPClients()
parseNextRTCMMessage()               handleWiFiClients()
buzzerUpdate() (GPIO)                updateDisplay() (I2C/OLED)
          │                                     ▲
          └──────────► rtcmQueue ───────────────┘
                       (FreeRTOS Q)
```

- **Core 1 — LoRa Reception (priority 2)**: radio SPI I/O, packet reassembly, RTCM parsing/CRC, buzzer.
- **Core 0 — Network & UI (priority 1)**: NTRIP broadcast, client management, OLED refresh.

### Data Flow

```
LoRa Radio (SX1276) → checkForPackets() → onReceive()
  → packet reassembly (activeMessages map)
  → processRTCMData() → RTCM circular buffer
  → parseNextRTCMMessage() (preamble + CRC-24Q)
  → rtcmQueue  [INTER-CORE BOUNDARY]
  → broadcastRTCMData() → NTRIP clients (TCP) → GNSS rovers
```

### Inter-Core Synchronization

| Mechanism | Type | Purpose |
| --- | --- | --- |
| `rtcmQueue`  | FreeRTOS xQueue  | Passes complete RTCM frames from Core 1 → Core 0 |
| `statsMux` | portMUX spinlock | Protects LoRa statistics read by display on Core 0 |
| `debugMutex` | FreeRTOS mutex | Serializes Serial output from both cores |

### Main Components

| Module | File | Responsibility |
| --- | --- | --- |
| **Main** | [src/main.cpp](src/main.cpp) | FreeRTOS task creation, boot sequence |
| **LoRa Radio** | [src/lora_radio.cpp](src/lora_radio.cpp) | SPI radio, packet reassembly, parsing pipeline |
| **RTCM Parser**  | [src/rtcm_parser.cpp](src/rtcm_parser.cpp) | Circular buffer, RTCM3 parsing, CRC-24Q |
| **NTRIP Server** | [src/ntrip_server.cpp](src/ntrip_server.cpp) | TCP caster, client management, broadcast |
| **WiFi Manager** | [src/wifi_manager.cpp](src/wifi_manager.cpp) | Access Point setup, client tracking |
| **Display** | [src/display.cpp](src/display.cpp) | SSD1306 OLED driver, statistics rendering |
| **Buzzer** | [src/buzzer.cpp](src/buzzer.cpp) | Non-blocking GPIO pulse on valid RTCM frame |
| **Debug** | [src/debug.cpp](src/debug.cpp) | Thread-safe Serial logging macros |
| **Config** | [include/config.h](include/config.h) | All compile-time constants |

### Timing

- **Display Update**: 500 ms
- **Packet Timeout**: 5000 ms (drop incomplete multi-packet messages)

## NTRIP Server

- Caster listens on TCP port `2101`, mount point `LORA`, max 4 clients.
- `GET / HTTP/1.1` → source table, then close.
- `GET /LORA HTTP/1.1` → `ICY 200 OK` + binary RTCM stream (connection stays open).
- No free client slot → `503 Service Unavailable` → close.

See [docs/ntrip-server.md](docs/ntrip-server.md) for the full protocol flow and rover configuration.

## Debugging

### Serial Output

Serial baud is `115200`. Both cores log through thread-safe macros that take `debugMutex`:

```cpp
DEBUG_PRINTLN(F(">>> LoRa init..."));      // status
DEBUG_PRINTLN(F("[NTRIP] client added"));  // module-tagged event
DEBUG_PRINTLN(F("[ERROR] CRC failed"));    // error
```

Set `ENABLE_UART_LOGGING false` in [include/config.h](include/config.h) to silence all output.

### Common Issues

| Problem | Solution |
| --- | --- |
| **No LoRa frames received** | Check antenna and verify radio params match the transmitter exactly  |
| **Frames received, CRC fails** | Spreading factor / bandwidth / sync word mismatch with transmitter |
| **Rover can't connect WiFi** | Confirm SSID `OSS-LoRa-RX` and password in `config.h` |
| **NTRIP client gets 503** | All 4 client slots in use — disconnect an idle client |
| **No RTK fix on rover** | Out of base range, obstructed sky view, or wait 30-120 s to converge |
| **Watchdog resets** | A task blocked too long — keep the LoRa core lean, yield in loops |

## Contributing

Open source project - contributions welcome!

1. Fork the repository
2. Create a branch (`git checkout -b feature/amazing-feature`)
3. Commit changes (`git commit -m 'Add amazing feature'`)
4. Push to branch (`git push origin feature/amazing-feature`)
5. Open a Pull Request

**Important**: Read [AGENTS.md](AGENTS.md) before starting work - it contains coding standards and the dual-core workflow for this project.

## Technical Documentation

### Shared specs (transmitter ↔ receiver)

These live in `firmware/shared/docs/` because both firmwares must stay byte-compatible with them:

- [lora-protocol.md](../shared/docs/lora-protocol.md) - LoRa over-the-air packet protocol
- [maintenance-frame.md](../shared/docs/maintenance-frame.md) - Maintenance/telemetry and command frame protocol

### Receiver-specific

- [docs/architecture.md](docs/architecture.md) - Dual-core task/core structure
- [docs/configuration.md](docs/configuration.md) - Pins, timing, and tunable constants
- [docs/lora-protocol.md](docs/lora-protocol.md) - Receiver view of the radio link
- [docs/ntrip-server.md](docs/ntrip-server.md) - NTRIP caster behavior and rover setup
- [AGENTS.md](AGENTS.md) - Project standards and workflow for AI agents

## License

MIT License - free to use in private and commercial projects.

## Acknowledgments

- **ThingPulse** - ESP8266/ESP32 OLED driver
- **Sandeep Mistry** - Arduino LoRa library

## Contact

Bug reports: [GitHub Issues](https://github.com/yourusername/gnss-rtk-toolset/issues)

---

**Project Status**: Active Development

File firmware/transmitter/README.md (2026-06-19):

# OSS RTCM Transmitter

ESP32 + SX1276 RTK gateway connecting NTRIP clients to LoRa transmitters for RTCM corrections.





OSS RTCM Transmitter

## Overview

Open Source Surveying Transmitter is an ESP32 firmware that transforms the device into a professional RTK gateway. The system receives GNSS corrections from NTRIP servers over WiFi and retransmits them over long distances via LoRa, enabling precise RTK positioning for rovers without internet access.

### Key Features

- **NTRIP Client** - Fetches RTCM3 corrections from NTRIP casters
- **LoRa Transmitter** - 433 MHz transmission with fragmentation protocol
- **RTCM Parser** - CRC validation and message type filtering
- **Web Interface** - Browser-based configuration (AP mode)
- **OLED Display** - Real-time status and statistics
- **ConfigManager** - Persistent configuration in LittleFS
- **Range Optimization** - Frame skipping for bandwidth savings
- **State Machine** - Synchronized TX/SILENCE cycles

## Use Cases

- **RTK Surveying** - Base station for multi-point surveys when internet is unavailable in the field
- **Precision Agriculture** - RTK guidance for autonomous machinery

## Hardware

### Required

- **TTGO T-Beam V1.1 or LoRa32 or similar** (ESP32 + SX1276 + OLED)
- **433 MHz LoRa Antenna** (recommended: dipole/yagi for range)
- **Power Supply** - USB-C or 18650 Li-Ion (3.7V)

### SX1276 Pinout (T-Beam predefined)

```
NSS   → GPIO 18
MOSI  → GPIO 27
MISO  → GPIO 19
SCK   → GPIO 5
RST   → GPIO 23
DIO0  → GPIO 26
```

### OLED Display

- **Type**: SSD1306 128x64
- **I2C**: GPIO 21 (SDA), GPIO 22 (SCL)

## Quick Start

### 1. Environment Setup

```bash
# Install PlatformIO
pip install platformio

# Clone repository
git clone <repo-url>
cd oss-transmitter
```

### 2. Basic Configuration

All configuration is now managed via the web interface or by editing the configuration file stored in LittleFS.

On first boot, the device creates a WiFi access point:

- SSID: `OSS-LoRa-TX-XXXXXX` (where XXXXXX is chip ID)
- Password: (no password)

Connect to this AP and configure:

- WiFi credentials
- NTRIP server settings
- LoRa parameters
- GGA position (for VRS)

Alternatively, edit [include/config.h](include/config.h) for default values:

```cpp
// NTRIP Caster
#define NTRIP_HOST "91.198.76.2"
#define NTRIP_PORT 2101
#define NTRIP_MOUNTPOINT "RTN4G_VRS_RTCM32"

// GGA Position (for VRS)
#define GGA_LATITUDE 50.2346     // Your latitude
#define GGA_LONGITUDE 19.2084    // Your longitude
#define GGA_ALTITUDE 266.0       // Altitude MSL

// LoRa Radio
#define LORA_FREQUENCY 433E6
#define LORA_SPREADING_FACTOR 7
#define LORA_TX_POWER 20
```

### 3. Build and Upload

```bash
# Build firmware
platformio run --environment ttgo-t-beam

# Upload to device
platformio run --target upload --environment ttgo-t-beam

# Monitor serial output
platformio device monitor --baud 115200
```

## LoRa Protocol

### Packet Structure

```
┌────────────┬───────────────┬──────────────┬─────────────┬──────────────────┐
│ Message ID │ Total Packets │ Packet Index │ Data Length │      Data        │
│  (1 byte)  │   (1 byte)    │   (1 byte)   │  (1 byte)   │  (0-246 bytes)   │
└────────────┴───────────────┴──────────────┴─────────────┴──────────────────┘
```

### Transmission Parameters

- **Frequency**: 433 MHz (configurable)
- **Spreading Factor**: 7 (speed/range compromise)
- **Bandwidth**: 125 kHz
- **Coding Rate**: 4/5
- **TX Power**: 20 dBm (max for SX1276)
- **Sync Word**: 0x12
- **CRC**: Hardware CRC enabled

### Fragmentation

Large RTCM messages are automatically fragmented:

- Max packet size: **250 bytes**
- Header size: **4 bytes**
- Max data per packet: **246 bytes**
- Max message size: **~62.7 KB** (255 × 246)

**Example**: RTCM message 1077 (500 bytes) → 3 LoRa packets

See [lora-protocol.md](../shared/docs/lora-protocol.md) for the complete (shared) specification.

## System Architecture

### State Machine

```
[INIT] → [WAITING_FOR_FIRST_RTCM] → [TRANSMISSION] ⇄ [GATHERING]
                                              ↓
                                         [ERROR]
```

1. **STATE_INIT** - Initialize WiFi, NTRIP, LoRa
2. **STATE_WAITING_FOR_FIRST_RTCM** - Wait for first data
3. **STATE_TRANSMISSION** (3.5s) - Transmit all buffered RTCM
4. **STATE_GATHERING** (0.25s) - Radio silence, buffer new RTCM
5. **STATE_ERROR** - Handle connection errors

### Main Components

| Module | File | Responsibility |
| --- | --- | --- |
| **ConfigManager** | [config_manager.cpp](src/config_manager.cpp) | LittleFS storage, web API |
| **WiFiManager** | [wifi_manager.cpp](src/wifi_manager.cpp) | WiFi client + AP mode |
| **NTRIPClient** | [ntrip_client.cpp](src/ntrip_client.cpp) | TCP client, GGA transmission |
| **RTCMParser** | [rtcm_parser.cpp](src/rtcm_parser.cpp) | RTCM3 parsing, CRC validation |
| **RTCMBuffer** | [rtcm_buffer.h](include/rtcm_buffer.h) | Type-based buffering and grouping |
| **LoRaTransmitter** | [lora_transmitter.cpp](src/lora_transmitter.cpp) | Fragmentation and transmission |
| **DisplayManager**  | [display_manager.cpp](src/display_manager.cpp) | OLED status screen |
| **WebInterface** | [web_interface_manager.cpp](src/web_interface_manager.cpp) | AsyncWebServer + REST API |

### Timing

- **TX Burst**: 3500 ms (transmit all collected RTCM)
- **Silence Period**: 250 ms (buffer only, no TX)
- **GGA Interval**: 2000 ms (VRS position update)
- **Display Update**: 500 ms
- **Serial Stats**: 5000 ms

## RTCM Message Types

### Default Transmitted Types

```cpp
// GPS RTK Observables
1001, 1002, 1003, 1004

// GPS/GLONASS Ephemeris
1019, 1020

// GPS SSR Corrections
1057, 1058, 1059, 1060, 1061, 1062

// GLONASS RTK
1009, 1010, 1011, 1012

// MSM (Multiple Signal Messages)
1074, 1075, 1076, 1077  // GPS L1/L2
1084, 1085, 1086, 1087  // GLONASS
1094, 1095, 1096, 1097  // Galileo

// Reference Station Info
1005, 1006, 1007, 1008, 1033
```

### Why Filtering?

Due to the limited bandwidth of the LoRa radio link, RTCM messages coming from the NTRIP server must be filtered. The current configuration supports the minimum set of messages necessary to achieve a stable RTK fix, balancing data completeness with transmission constraints.

Filtering is configurable via **Web Interface** → **RTCM Filtering**.

## Debugging

### Enable DEBUG Mode

In [include/config.h](include/config.h):

```cpp
#define DEBUG                    // General debug output
#define DEBUG_LORA_PACKETS true  // Detailed packet logs
#define DEBUG_LORA_VERBOSE true  // Ultra-verbose logging
```

### Common Issues

| Problem | Solution |
| --- | --- |
| **WiFi won't connect** | Check credentials in web interface, increase timeout to 60s  |
| **NTRIP error 401** | Wrong credentials, verify username/password in web interface |
| **No RTCM data** | Wrong GGA position (out of VRS range) or mountpoint |
| **LoRa not transmitting** | Check antenna, SWR, power settings |
| **Restart every minute**  | Watchdog - possible deadlock in NTRIP client |

## Contributing

Open source project - contributions welcome!

1. Fork the repository
2. Create a branch (`git checkout -b feature/amazing-feature`)
3. Commit changes (`git commit -m 'Add amazing feature'`)
4. Push to branch (`git push origin feature/amazing-feature`)
5. Open a Pull Request

**Important**: Read [AGENTS.md](AGENTS.md) before starting work - it contains coding standards and workflow for this project.

## Technical Documentation

### Shared specs (transmitter ↔ receiver)

These live in `firmware/shared/docs/` because both firmwares must stay byte-compatible with them:

- [lora-protocol.md](../shared/docs/lora-protocol.md) - LoRa over-the-air packet protocol
- [maintenance-frame.md](../shared/docs/maintenance-frame.md) - Maintenance/telemetry and command frame protocol

### Transmitter-specific

- [docs/config-structure.md](docs/config-structure.md) - Web UI configuration structure and REST API contract
- [AGENTS.md](AGENTS.md) - Project standards and workflow for AI agents

## License

MIT License - free to use in private and commercial projects.

## Acknowledgments

- **ThingPulse** - ESP8266/ESP32 OLED driver
- **Sandeep Mistry** - Arduino LoRa library
- **me-no-dev** - ESPAsyncWebServer
- **bblanchon** - ArduinoJson

## Contact

Bug reports: [GitHub Issues](https://github.com/yourusername/oss-transmitter/issues)

---

**Project Status**: Active Development

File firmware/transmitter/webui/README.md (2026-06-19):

# OSS RTCM Transmitter - Configuration UI

Mobile-first Progressive Web App for configuring Open Survey System RTCM LoRa GNSS transmitters.

OSS RTCM Transmitter

## Features

- 📱 **Mobile-optimized** - Designed for phones and tablets
- 🔌 **Offline-ready** - Works without internet connectivity
- 📡 **WiFi Scanner** - Scan and select available networks
- 🗺️ **NTRIP Integration** - Fetch mountpoints from caster
- 📍 **GPS Location** - Auto-fill coordinates using device GPS
- ⚙️ **LoRa Configuration** - Full SX1276 parameter control
- 🎯 **RTCM Filtering** - Advanced message type picker with descriptions
- ❓ **Built-in Help** - Context-sensitive help for each configuration section
- 🎨 **PWA Support** - Install as app on home screen

## Quick Start

### Development

```bash
# Install dependencies
pnpm install

# Start dev server (PWA features won't work in dev mode)
pnpm dev
```

### Build for ESP32

```bash
# Build optimized bundle for ESP32
pnpm run build:esp32

# Output: dist-esp32/
# Upload entire directory to ESP32 SPIFFS/LittleFS
```

### Regenerate PWA Icons

```bash
# After updating public/oss-logo.svg
pnpm run generate:icons
```

## Configuration Sections

1. **WiFi** - Network credentials, connection timeout, network scanner
2. **NTRIP** - Caster connection, mountpoint selection
3. **GGA Position** - Base station coordinates with GPS auto-fill
4. **LoRa Radio** - Frequency, spreading factor, bandwidth, coding rate, TX power
5. **RTCM Filtering** - Message type selection with priorities

## Tech Stack

- React 18 + TypeScript
- Tailwind CSS v4 (mobile-first)
- Radix UI / shadcn/ui components
- Vite 6 build tool
- vite-plugin-pwa for Progressive Web App support

## Project Structure

```
src/
├── app/
│   ├── App.tsx              # Main app with tabs
│   ├── components/
│   │   ├── config/          # Config forms for each tab
│   │   ├── modals/          # WiFi scan, mountpoints, help
│   │   └── ui/              # Reusable UI components
│   ├── hooks/
│   │   └── useConfig.ts     # API communication
│   ├── types/
│   │   └── config.ts        # TypeScript interfaces
│   └── data/
│       ├── rtcm-messages.ts # RTCM message definitions
│       └── help-content.ts  # Help text content
public/
├── oss-logo.svg             # OSS logo (vector)
├── icon-192.png             # PWA icon 192x192
├── icon-512.png             # PWA icon 512x512
└── manifest.json            # PWA manifest
```

## API Endpoints

The UI expects these endpoints on the ESP32:

- `GET /api/config` - Get current configuration
- `POST /api/config` - Save configuration (triggers restart)
- `POST /api/restart` - Restart device
- `POST /api/wifi/scan` - Scan WiFi networks
- `POST /api/ntrip/mountpoints` - Fetch NTRIP mountpoints

See `src/imports/config-structure.md` for full API specification.

## Development

For detailed development guide, see:

- **[docs/development.md](docs/development.md)** - Architecture, patterns, how to add features
- **[contributing.md](contributing.md)** - Contributing guidelines, PR process
- **[.github/copilot-instructions.md](.github/copilot-instructions.md)** - GitHub Copilot context

## Building & Deploying

### Production Build

```bash
pnpm run build:esp32
```

This creates a `dist-esp32/` directory with:

- `index.html` - Main HTML file
- `assets/` - Bundled JS/CSS (no external dependencies)
- PWA manifest and service worker
- Icon files

### ESP32 Deployment

1. Build the project
2. Upload contents of `dist-esp32/` to ESP32 filesystem (SPIFFS/LittleFS)
3. Serve `index.html` from root path `/`
4. Ensure API endpoints available at `/api/*`

### Local Testing

```bash
# Build
pnpm run build:esp32

# Serve locally
cd dist-esp32
python3 -m http.server 8080

# Open http://localhost:8080 in browser
# PWA features will work on localhost
```

## PWA Installation

### On Mobile (iOS/Android)

1. Open the config UI in Safari (iOS) or Chrome (Android)
2. Tap Share → "Add to Home Screen"
3. Icon with OSS logo will appear on home screen
4. Opens in standalone mode (no browser UI)

**Note**: PWA features (service worker, geolocation) work best when installed as home screen app.

### Geolocation

The app can auto-fill GGA coordinates using device GPS:

- Works in installed PWA mode
- Requires location permission
- Gracefully degrades to manual input if unavailable
- GPS works offline (no internet needed for satellites)

## Browser Support

- Chrome/Edge 90+ (recommended)
- Safari 15+ (iOS)
- Firefox 88+

PWA features require HTTPS or localhost (ESP32 AP is HTTP-only, but works when installed).

## License

Open source - see LICENSE file for details.

## Related Projects

- ESP32 Firmware: [Link to firmware repo]
- Hardware Design: [Link to hardware repo]
- Documentation: [Link to docs]

## Contributing

See [contributing.md](contributing.md) for development setup and guidelines.

## Support

For issues, questions, or feature requests:

- GitHub Issues: [Link to issues]
- Documentation: See `docs/development.md` and `src/imports/config-structure.md`

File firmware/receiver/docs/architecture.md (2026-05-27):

# System Architecture

## Overview

OSS Receiver is an ESP32-based LoRa-to-NTRIP gateway. It receives RTCM correction data via LoRa radio, reassembles fragmented messages, and serves them to GNSS receivers via a local NTRIP caster over WiFi.

**Hardware**: TTGO LoRa32 V2.1 (ESP32 + SX1276 + SSD1306 OLED)

## Dual-Core Architecture

The firmware runs two FreeRTOS tasks pinned to separate ESP32 cores:

```
┌─────────────────────────────────────────────────────────────────────┐
│                         ESP32 Dual-Core                             │
│                                                                     │
│  Core 1 (loraTask, prio 2)          Core 0 (networkTask, prio 1)   │
│  ─────────────────────────          ────────────────────────────    │
│  LoRa SPI (checkForPackets)         xQueueReceive(rtcmQueue)       │
│  onReceive() → reassembly           broadcastRTCMData() → clients  │
│  processRTCMData()                  handleNTRIPClients()            │
│  parseNextRTCMMessage()             handleWiFiClients()             │
│  buzzerUpdate() (GPIO)              updateDisplay() (I2C/OLED)     │
│  checkMessageTimeout()              removeDisconnectedClients()     │
│           │                                    ▲                    │
│           │        ┌──────────────┐            │                    │
│           └───────►│  rtcmQueue   │────────────┘                    │
│                    │ (FreeRTOS Q) │                                  │
│                    └──────────────┘                                  │
└─────────────────────────────────────────────────────────────────────┘
```

### Core 1 — LoRa Reception (Time-Critical)

Higher priority (2). Handles all radio I/O via SPI:

1. Polls LoRa radio for incoming packets
2. Reassembles multi-packet messages (matching by Message ID)
3. Feeds reassembled data into the RTCM circular buffer
4. Parses complete RTCM frames (preamble, length, CRC validation)
5. Enqueues valid RTCM frames into `rtcmQueue`
6. Drives the buzzer GPIO on each valid frame

### Core 0 — Network & UI

Lower priority (1). Shares core with ESP32 WiFi stack (which also runs on Core 0):

1. Dequeues RTCM frames from `rtcmQueue`
2. Broadcasts them to all authenticated NTRIP clients
3. Accepts new NTRIP client connections
4. Handles NTRIP protocol (GET requests, source table, mount points)
5. Updates OLED display with statistics every 500ms

## Inter-Core Synchronization

| Mechanism | Type | Purpose |
| --- | --- | --- |
| `rtcmQueue`  | FreeRTOS xQueue  | Passes complete RTCM frames from Core 1 → Core 0 |
| `statsMux` | portMUX spinlock | Protects LoRa statistics read by display on Core 0 |
| `debugMutex` | FreeRTOS mutex | Serializes Serial output from both cores |

## Data Flow

```
LoRa Radio (SX1276)
    │ SPI
    ▼
checkForPackets() ──► onReceive()
                         │
                         ▼
                  Packet Reassembly
                  (activeMessages map)
                         │
                         ▼
                  processRTCMData()
                         │
                         ▼
                  RTCM Circular Buffer
                  (addToRTCMBuffer)
                         │
                         ▼
                  parseNextRTCMMessage()
                  (preamble + CRC check)
                         │
                         ▼
                  ┌──────────────┐
                  │  rtcmQueue   │  ◄── Inter-core boundary
                  └──────┬───────┘
                         │
                         ▼
                  broadcastRTCMData()
                         │
                         ▼
                  NTRIP Clients (TCP)
                         │
                         ▼
                  GNSS Rover Receivers
```

## Module Overview

| Module | File(s) | Responsibility |
| --- | --- | --- |
| Main | `main.cpp` | FreeRTOS task creation, setup sequence |
| LoRa Radio | `lora_radio.cpp/h` | SPI radio, packet reassembly, RTCM parsing pipeline |
| RTCM Parser  | `rtcm_parser.cpp/h`  | Circular buffer, RTCM3 frame parsing, CRC-24Q validation |
| NTRIP Server | `ntrip_server.cpp/h` | TCP server, NTRIP protocol, client management, data broadcast |
| WiFi Manager | `wifi_manager.cpp/h` | Access Point setup, client tracking |
| Display | `display.cpp/h` | SSD1306 OLED driver, statistics rendering |
| Buzzer | `buzzer.cpp/h` | Non-blocking GPIO pulse on valid RTCM frame |
| Debug | `debug.cpp/h` | Thread-safe Serial logging macros |
| Config | `config.h` | All compile-time constants (pins, radio, network, timing) |

## Boot Sequence

```
setup()
  ├── initDebug()           — Serial + debug mutex
  ├── setupOLED()           — I2C display init
  ├── showSplashScreen()    — 3s splash
  ├── setupWiFiHotspot()    — AP mode
  ├── setupNTRIPServer()    — TCP listener on port 2101
  ├── initRTCMBuffer()      — Circular buffer reset
  ├── setupBuzzer()         — GPIO init
  ├── setupLoRa()           — SPI + radio config
  ├── xQueueCreate()        — Inter-core queue
  ├── xTaskCreatePinnedToCore(loraTask, Core 1)
  └── xTaskCreatePinnedToCore(networkTask, Core 0)

loop() → vTaskDelete(NULL)  — Arduino loop unused
```

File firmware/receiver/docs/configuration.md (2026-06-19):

# Configuration Reference

All compile-time configuration is defined in `include/config.h`.

## Hardware Pins (TTGO LoRa32 V2.1)

### LoRa SPI (SX1276)

| Define | GPIO | Function |
| --- | ---- | --- |
| `LORA_SCK` | 5 | SPI Clock |
| `LORA_MISO`  | 19 | SPI MISO |
| `LORA_MOSI`  | 27 | SPI MOSI |
| `LORA_SS` | 18 | SPI Chip Select  |
| `LORA_RESET` | 14 | Radio Reset |
| `LORA_DIO0`  | 26 | Radio IRQ (DIO0) |

### OLED Display (SSD1306, I2C)

| Define | GPIO | Function |
| --- | ---- | --- |
| `OLED_SDA` | 21 | I2C Data |
| `OLED_SCL` | 22 | I2C Clock |
| `OLED_RST` | 16 | Display Reset |

### Other

| Define | GPIO | Function |
| --- | ---- | --- |
| `BUZZER_PIN` | 4 | Buzzer output (active high) |

## LoRa Radio Parameters

| Define | Value | Description |
| --- | --- | --- |
| `LORA_FREQUENCY` | 433700000 (433.7 MHz) | Carrier frequency |
| `LORA_SPREADING_FACTOR` | 7 | SF7 — fastest data rate |
| `LORA_BANDWIDTH` | 500E3 (500 kHz) | Signal bandwidth |
| `LORA_CODING_RATE` | 5 | 4/5 coding rate |
| `LORA_TX_POWER` | 20 | Transmit power in dBm |
| `LORA_SYNC_WORD` | 0x12 | Network sync word |

Preamble length is set to 12 symbols. Hardware CRC is enabled.

## Protocol Constants

| Define | Value | Description |
| --- | ----- | --- |
| `MAX_PACKET_SIZE` | 512 | Maximum raw packet buffer |
| `HEADER_SIZE` | 4 | LoRa packet header size (bytes) |
| `MAX_DATA_SIZE` | 508 | Max payload per packet |
| `MAX_MESSAGE_BUFFER` | 16384 | 16 KB reassembly buffer |

## Timing

| Define | Value | Description |
| --- | --- | --- |
| `DISPLAY_UPDATE_INTERVAL` | 500 ms  | OLED refresh rate |
| `PACKET_TIMEOUT` | 5000 ms | Timeout for incomplete multi-packet messages |
| `BUZZER_PULSE_US` | 1000 µs | Buzzer pulse duration per beep |

## WiFi Access Point

| Define | Value | Description |
| --- | --- | --- |
| `WIFI_SSID` | `OSS-LoRa-RX` | AP network name |
| `WIFI_PASSWORD` | `lora123456`  | AP password (WPA2) |
| `WIFI_CHANNEL` | 1 | WiFi channel |
| `WIFI_MAX_CONNECTIONS` | 4 | Max simultaneous WiFi clients |

## NTRIP Server

| Define | Value  | Description |
| --- | --- | --- |
| `NTRIP_PORT` | 2101 | TCP listen port |
| `NTRIP_MOUNT_POINT` | `LORA` | NTRIP mount point name |
| `NTRIP_MAX_CLIENTS` | 4 | Max concurrent NTRIP streams |
| `RTCM_BUFFER_SIZE`  | 8192 | Circular buffer for RTCM parsing (bytes) |

## Dual-Core (FreeRTOS)

| Define | Value | Description |
| --- | ----- | --- |
| `LORA_CORE` | 1 | CPU core for LoRa reception |
| `NETWORK_CORE` | 0 | CPU core for WiFi/NTRIP/display |
| `LORA_TASK_STACK` | 8192  | Stack size for LoRa task (bytes) |
| `NETWORK_TASK_STACK` | 8192  | Stack size for network task (bytes) |
| `LORA_TASK_PRIORITY` | 2 | FreeRTOS priority (higher = more urgent) |
| `NETWORK_TASK_PRIORITY` | 1 | FreeRTOS priority |
| `RTCM_QUEUE_SIZE` | 16 | Max RTCM messages queued between cores |

## Debug

| Define | Value | Description |
| --- | ----- | --- |
| `ENABLE_UART_LOGGING` | true  | Set to `false` to disable all Serial output |

Serial baud rate: 115200 (configured in `debug.cpp`).

## PlatformIO Build

Target environment: `ttgo-lora32-v21`

Dependencies (from `platformio.ini`):

- `thingpulse/ESP8266 and ESP32 OLED driver for SSD1306 displays@^4.4.0`
- `sandeepmistry/LoRa@^0.8.0`

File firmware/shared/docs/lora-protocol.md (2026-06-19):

# LoRa RTCM Transmission Protocol (Protocol v2)

> **Canonical, shared specification.** This document is the single source of truth for the
> LoRa link between the **OSS Transmitter** and the **OSS Receiver**. Both firmwares must
> stay byte-compatible with it. Device-specific files
> (`transmitter/lora-protocol.md`, `receiver/docs/lora-protocol.md`) redirect here.

## Overview

RTCM3 correction data is transmitted over LoRa using a simple fragmentation protocol. Large
RTCM messages are split into multiple LoRa packets and reassembled at the receiver.

## Protocol Version

This document describes **Protocol v2**. The header was extended by one byte (`frameType`)
compared to the original 4-byte v1 header.

| `frameType` | Symbol | Description |
| --- | --- | --- |
| `0x01` | `FRAME_RTCM` | RTCM correction data |
| `0x02` | `FRAME_MAINTENANCE` | Telemetry broadcast (TX → air) |
| `0x03` | `FRAME_COMMAND` | Control command (RX → transmitter) |
| `0x04` | `FRAME_ACK` | Optional acknowledgement |

## Packet Structure

```
+────────────+──────────────+─────────────────+────────────────+─────────────+──────────────────+
│ Frame Type │  Message ID  │  Total Packets  │  Packet Number │ Data Length │       Data       │
│  (1 byte)  │   (1 byte)   │    (1 byte)     │    (1 byte)    │  (1 byte)   │  (0-245 bytes)   │
+────────────+──────────────+─────────────────+────────────────+─────────────+──────────────────+
```

### Header Fields (5 bytes)

| Field | Size | Range | Description |
| --- | --- | --- | --- |
| Frame Type | 1 byte | 0x01–0x04 | Type of frame (see table above) |
| Message ID | 1 byte | 0–255 | Unique ID per message, wraps around |
| Total Packets | 1 byte | 1–255 | How many packets comprise this message |
| Packet Number | 1 byte | 0 to Total-1 | Sequential index of this packet |
| Data Length | 1 byte | 0–245 | Payload bytes in this packet |

### Payload

Up to 245 bytes of raw RTCM data per packet (250 byte max LoRa frame − 5 byte header).

## Radio Parameters

> **⚠️ TX and RX `config.h` must use identical radio parameters or the link silently fails.**
> The values below are the canonical v2 set. See "Implementation status" at the end of this
> document for the current per-device config and any outstanding mismatch.

| Parameter | Value |
| --- | --- |
| Frequency | 433.7 MHz |
| Spreading Factor | SF7 |
| Bandwidth | 500 kHz |
| Coding Rate | 4/5 |
| TX Power | 20 dBm |
| Sync Word | 0x12 |
| Preamble | 12 symbols |
| CRC | Enabled (hardware) |

## Fragmentation Example

A 500-byte RTCM message with Message ID 42:

```
Packet 0: [0x01] [42] [03] [00] [245] [245 bytes of RTCM data]
Packet 1: [0x01] [42] [03] [01] [245] [245 bytes of RTCM data]
Packet 2: [0x01] [42] [03] [02] [010] [ 10 bytes of RTCM data]
```

Maximum theoretical message size: 255 × 245 = 62,475 bytes.

## Frame Skipping (Radio Link Budget Optimization)

To reduce LoRa airtime, the **transmitter** can drop a configurable fraction of RTCM frames
before transmission:

- **Configuration**: `loraTransmissionRatio` (managed via `ConfigManager` / web interface)
- **Default**: `1` (transmit all frames)
- **Options**:
  - `1` = transmit all RTCM frames (100%)
  - `2` = transmit every 2nd frame (50% reduction)
  - `3` = transmit every 3rd frame (66% reduction)
  - `N` = transmit every Nth frame

### Benefits

- Reduces LoRa airtime usage
- Extends battery life
- Allows more devices to share the same frequency
- Maintains acceptable correction accuracy for most applications

### Statistics

The transmitter tracks: total RTCM frames received from NTRIP, total frames transmitted via
LoRa, the current transmission ratio, and total bytes transmitted.

## Reassembly at Receiver

```
Incoming LoRa Packet
        │
        ▼
  Parse header (frameType, msgId, total, pktNum, len)
        │
        ▼
  frameType == FRAME_RTCM? If not, drain and discard
        │
        ▼
  Validate: pktNum < total, total > 0, len ≤ 245
        │
        ▼
  Lookup/create MessageReassembly[msgId]
        │
        ▼
  Store packet data at pktNum slot
        │
        ▼
  receivedPackets == totalPackets?
       ╱              ╲
    Yes                No
     │                  │
     ▼                  ▼
  Reassemble in       Wait for more
  packet order        (timeout: 5s)
     │
     ▼
  Feed to RTCM parser
```

### Timeout Handling

- Incomplete messages are cleaned up after `PACKET_TIMEOUT` (5 seconds)
- Timeout counter is incremented for statistics
- Duplicate packets are silently discarded

### Validation

The receiver checks:

1. Packet size ≥ 5 bytes (header) and ≤ 250 bytes
2. `frameType == FRAME_RTCM` (`0x01`) — other types are drained and discarded
3. `packetNumber < totalPackets`
4. `totalPackets > 0`
5. `dataLength ≤ 245`
6. Consistent `totalPackets` across all packets of the same message

## RTCM3 Frame Parsing

After reassembly, the raw byte stream is fed into a circular buffer and parsed for RTCM3 frames:

```
┌──────────┬───────────────┬─────────────────┬───────────┐
│ Preamble │ Reserved + Len│    Payload      │  CRC-24Q  │
│  0xD3    │   2 bytes     │  0-1023 bytes   │  3 bytes  │
│ (1 byte) │ (10+10 bits)  │                 │           │
└──────────┴───────────────┴─────────────────┴───────────┘
```

- **Preamble**: Always `0xD3`
- **Length**: 10-bit value in bits 14–23 of the header (max 1023)
- **Message Type**: First 12 bits of payload
- **Station ID**: Next 12 bits of payload
- **CRC-24Q**: Qualcomm CRC over header + payload

### Supported RTCM Message Types

| Type | Description |
| --- | --- |
| 1001–1004 | GPS L1/L2 observations |
| 1005–1006 | Station coordinates |
| 1007–1008 | Antenna description |
| 1009–1012 | GLONASS L1/L2 observations |
| 1019 | GPS ephemeris |
| 1020 | GLONASS ephemeris |
| 1033 | Receiver information |
| 1074–1077 | GPS MSM4/5/7 |
| 1084–1087 | GLONASS MSM4/5/7 |
| 1094–1097 | Galileo MSM4/5/7 |
| 1124–1127 | BeiDou MSM4/5/7 |
| 1230 | GLONASS code-phase bias |

## Error Statistics

The receiver tracks:

| Counter | Description |
| --- | --- |
| `completeMessagesReceived` | Successfully reassembled messages |
| `timeoutMessages` | Messages that timed out (missing packets) |
| `crcErrorMessages` | RTCM frames with invalid CRC-24Q |
| `lastRssi` | RSSI of last received LoRa packet (dBm) |
| Message rate | Complete messages per second (10s window) |

## Design Decisions

- **Fire-and-forget**: No ACK/retransmission — LoRa link budget and hardware CRC provide
  sufficient reliability
- **Compact header**: 5-byte overhead (v2) enables near-maximum payload per packet while
  carrying a frame type for telemetry/command multiplexing
- **Wrapping Message ID**: 8-bit ID limits to 256 concurrent in-flight messages (sufficient
  for RTCM rates)

## Implementation Status

Both firmwares implement the v2 5-byte header (`frameType` + `messageId` + `totalPackets` +
`packetNumber` + `dataLength`).

> **Known mismatch (action needed):** the radio parameters in `config.h` currently differ
> between the two devices and must be reconciled to interoperate:
>
> | Define           | Transmitter (`config.h`) | Receiver (`config.h`) |
> | ---------------- | ------------------------ | --------------------- |
> | `LORA_FREQUENCY` | `433E6`                  | `433700000`           |
> | `LORA_BANDWIDTH` | `125E3`                  | `500E3`               |
>
> Pick one canonical set (this doc assumes 433.7 MHz / 500 kHz) and update both `config.h`
> files to match.

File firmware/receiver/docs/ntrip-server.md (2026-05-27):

# NTRIP Server

## Overview

The device runs a lightweight NTRIP caster accessible over the WiFi Access Point. GNSS rover receivers connect to it to receive real-time RTCM corrections relayed from the LoRa link.

## Network Setup

```
LoRa Transmitter                  OSS Receiver (this device)              GNSS Rover
    ╶╶╶╶╶╶╶╶╶╶╶╶╶╶╶╶╶╶╶╶╶╶╶╶╶╶╶╶╶╶╶╶╶╶╶╶╶╶╶╶╶╶╶╶╶╶╶╶╶╶╶╶╶╶╶╶╶╶╶╶╶╶╶╶╶╶╶╶╶╶╶╶╶╶╶╶
                                  ┌──────────────────┐
    RTCM via LoRa ──────────────► │  WiFi AP         │ ◄─── Rover connects
                                  │  192.168.4.1     │      to WiFi
                                  │                  │
                                  │  NTRIP Caster    │
                                  │  Port 2101       │ ◄─── GET /LORA HTTP/1.1
                                  │  Mount: /LORA    │ ───► ICY 200 OK
                                  │                  │ ───► RTCM binary stream
                                  └──────────────────┘
```

## Connection Details

| Parameter | Value |
| --- | --- |
| WiFi SSID | `OSS-LoRa-RX`  |
| WiFi Password | `lora123456` |
| Server IP | `192.168.4.1`  |
| NTRIP Port | `2101` |
| Mount Point | `LORA` |
| Max Clients | 4 simultaneous |

## NTRIP Protocol Flow

### 1. Source Table Request

Client sends:

```
GET / HTTP/1.1
```

Server responds:

```
SOURCETABLE 200 OK
Content-Type: gnss/sourcetable

STR;LORA;LORA;RTCM 3.x;1005,1077,1087,1097,1127,1230;2;GPS+GLO+GAL+BDS;SNIP;ESP32;N;N;560;none
ENDSOURCETABLE
```

Connection is closed after sending the source table.

### 2. Mount Point Stream Request

Client sends:

```
GET /LORA HTTP/1.1
```

Server responds:

```
ICY 200 OK
Content-Type: gnss/data

<binary RTCM data stream>
```

The connection stays open. Complete RTCM frames are pushed to the client as they arrive from the LoRa link.

## Client Lifecycle

```
New TCP connection on port 2101
        │
        ▼
  Assign to free client slot (max 4)
        │
  No free slot? → 503 Service Unavailable → close
        │
        ▼
  Wait for GET request
        │
        ├── GET /LORA → ICY 200 OK → authenticated = true → stream RTCM
        │
        └── GET / HTTP → send source table → close
        │
        ▼
  Stream active (broadcastRTCMData pushes frames)
        │
        ▼
  Client disconnects → slot freed
```

## Rover Configuration

Configure your GNSS rover's NTRIP client with:

| Setting | Value |
| --- | --- |
| Host / IP | `192.168.4.1` |
| Port | `2101` |
| Mount Point | `LORA` |
| User / Password | _(not required)_ |

### Example: u-blox u-center

1. Connect rover to `OSS-LoRa-RX` WiFi
2. Receiver → NTRIP Client
3. Address: `192.168.4.1:2101`
4. Mount point: `LORA`

### Example: SW Maps (Android)

1. Connect phone to `OSS-LoRa-RX` WiFi
2. NTRIP Connection → Add
3. Host: `192.168.4.1`, Port: `2101`, Mount: `LORA`

## OLED Display

The display shows live statistics updated every 500ms:

```
┌────────────────────────────┐
│ OSS RTCM Receiver          │
│────────────────────────────│
│ RX:          2.3/s (1s)    │
│ Err:              0.5%     │
│ WiFi:             1/4      │
│ NTRIP:            1/4      │
└────────────────────────────┘
```

| Line  | Meaning |
| ----- | --- |
| RX | RTCM message rate (msg/s) and seconds since last message |
| Err | Error rate (timeouts + CRC failures as % of total) |
| WiFi  | Connected WiFi stations / max |
| NTRIP | Authenticated NTRIP clients / max |

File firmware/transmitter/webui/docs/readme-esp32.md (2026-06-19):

# OSS RTCM Transmitter - Web Configuration UI

Mobile-first Progressive Web App for configuring Open Survey System RTCM LoRa transmitters.

## Features

- 📱 **Mobile-optimized** - Designed for phones/tablets
- 🔌 **Offline-ready** - PWA with service worker caching
- 📡 **WiFi Scanner** - Scan and select available networks
- 🗺️ **NTRIP Integration** - Fetch mountpoints from caster
- ⚙️ **LoRa Configuration** - Full SX1276 parameter control
- 🎯 **RTCM Filtering** - Configure message types and priorities

## Build for ESP32

To build the static HTML/JS/CSS bundle for ESP32 filesystem:

```bash
pnpm install
pnpm run build:esp32
```

This creates a `dist-esp32/` directory with all static files ready to upload to ESP32.

### Build Output

The build produces:

- `index.html` - Main HTML file
- `assets/` - JS/CSS bundles (all dependencies inlined, no CDN)
- PWA manifest and service worker
- Icon files

### Uploading to ESP32

1. Build the project with `pnpm run build:esp32`
2. Upload all files from `dist-esp32/` to ESP32's SPIFFS/LittleFS
3. Serve `index.html` from ESP32 web server at `/`
4. Ensure API endpoints are available at `/api/*`

## PWA Icons

The project includes auto-generated icons with the OSS logo in `public/`:

- `icon-192.png` (192x192px)
- `icon-512.png` (512x512px)

These are generated from `scripts/generate-icons-sharp.mjs` using the OSS logo (`public/oss-logo.png`). To regenerate:

```bash
pnpm run generate:icons
```

To customize:

1. Replace `public/oss-logo.png` with your own logo
2. Run `pnpm run generate:icons`
3. Rebuild with `pnpm run build:esp32`

## API Endpoints

The UI expects these endpoints on the ESP32:

- `GET /api/config` - Get current configuration
- `POST /api/config` - Save configuration (triggers restart)
- `POST /api/restart` - Restart device
- `POST /api/wifi/scan` - Scan WiFi networks
- `POST /api/ntrip/mountpoints` - Fetch NTRIP mountpoints

See `src/imports/config-structure.md` for full API specification.

## Development

For local development (not for ESP32):

```bash
pnpm install
pnpm run dev
```

Note: You'll need to mock the API endpoints or proxy to a real device.

## Configuration Sections

1. **WiFi** - Network credentials and connection timeout
2. **NTRIP** - Caster host, port, mountpoint, authentication
3. **GGA Position** - Base station coordinates and send interval
4. **LoRa Radio** - Frequency, spreading factor, bandwidth, coding rate, TX power, sync word
5. **RTCM Filtering** - Allowed message types and priority types

## Technology Stack

- React 18
- TypeScript
- Tailwind CSS v4
- Radix UI (shadcn/ui components)
- Vite 6 (build tool)
- vite-plugin-pwa (PWA support)

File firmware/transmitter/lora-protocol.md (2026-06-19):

# LoRa RTCM Transmission Protocol

> 📦 **Moved.** The LoRa protocol is shared by the transmitter and the receiver, so the
> specification now lives in one canonical place:
>
> **→ [`../shared/docs/lora-protocol.md`](../shared/docs/lora-protocol.md)**
>
> Please update that file when changing the over-the-air format, and keep both firmwares
> byte-compatible with it.

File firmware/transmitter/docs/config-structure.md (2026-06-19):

# Configuration Structure — Web UI

This document describes the configuration structure of the RTCM LoRa Transmitter device as exposed through the Web UI.
It serves as input for the work on redesigning the interface in Figma.

---

## UI Navigation

The interface is divided into **5 tabs**:

| # | Tab ID  | Label | Description |
| --- | --- | --- | --- |
| 1 | `wifi`  | WiFi | WiFi connection configuration  |
| 2 | `ntrip` | NTRIP | NTRIP caster configuration |
| 3 | `gga` | GGA Position | Base station position (GGA) |
| 4 | `lora`  | LoRa Radio | LoRa radio parameters (SX1276) |
| 5 | `rtcm`  | RTCM Filtering | RTCM message type filtering |

### Global actions (outside the tabs)

| Action | Type | Behavior |
| --- | --- | --- |
| Save & Restart | Submit (primary) | Validation → confirm dialog → POST config → device restart |
| Reload Config  | Button (secondary) | Fetches the current configuration from the device |
| Restart Device | Button (danger) | Confirm dialog → device restart |

---

## Configuration sections — field details

### 1. WiFi

| Field | JSON Key | Type | Required | Validation | Default value | Notes |
| --- | --- | --- | --- | --- | --- | --- |
| WiFi Network (SSID) | `wifi.ssid` | `string` | ✅ | Non-empty | `""` | Has a "Scan" action — opens a modal with a list of available networks |
| Password | `wifi.password` | `string` (password) | ❌ | — | `""` | Empty = open network |
| Connection Timeout  | `wifi.timeout`  | `integer` (ms) | ✅ | min: 5000, max: 60000, step: 1000 | `30000` | |

**Additional functionality**: WiFi scan modal

- Displays a list of networks sorted by RSSI (signal strength)
- Each network shows: SSID, BSSID, channel, RSSI (dBm), encryption type (open/secured), signal strength icon
- Clicking a network inserts the SSID into the form field
- The Rescan button allows re-running the scan

### 2. NTRIP

| Field | JSON Key | Type | Required | Validation | Default value | Notes |
| --- | --- | --- | --- | --- | --- | --- |
| Host | `ntrip.host` | `string` | ✅ | Non-empty | `"91.198.76.2"` | |
| Port | `ntrip.port` | `integer` | ✅ | min: 1, max: 65535 | `2101` | |
| Username | `ntrip.user` | `string` | ❌ | — | `""` | |
| Password | `ntrip.password` | `string` (password) | ❌ | — | `""` | |
| Mountpoint | `ntrip.mountpoint` | `string` | ✅ | Non-empty | `"RTN4G_VRS_RTCM32"` | Has a "Fetch" action — opens a modal with a list of mountpoints |
| Connection Timeout | `ntrip.timeout` | `integer` (ms) | ✅ | min: 5000, max: 60000, step: 1000 | `10000` | |

**Additional functionality**: NTRIP mountpoint fetch modal

- Requires the Host and Port fields to be filled in first (validation before opening)
- Sends a request to the NTRIP caster with the provided credentials
- Displays a list of mountpoint names
- Clicking a mountpoint inserts its name into the form field
- The Refresh button allows re-running the fetch

### 3. GGA Position

| Field | JSON Key | Type | Required | Validation | Default value | Notes |
| --- | --- | --- | --- | --- | --- | --- |
| Latitude (°) | `gga.latitude` | `float` | ✅ | min: -90, max: 90, step: 0.0001 | `50.2346` | Decimal degrees, positive = North |
| Longitude (°) | `gga.longitude` | `float` | ✅ | min: -180, max: 180, step: 0.0001 | `19.2084` | Decimal degrees |
| Altitude (m) | `gga.altitude` | `float` | ✅ | step: 0.1 | `266.0` | Meters above sea level |
| Send Interval (ms) | `gga.sendInterval` | `integer` (ms) | ✅ | min: 1000, max: 60000, step: 1000 | `2000` | Interval for sending GGA to the NTRIP caster |

### 4. LoRa Radio

| Field | JSON Key | Type | Required | Validation | Default value | Notes |
| --- | --- | --- | --- | --- | --- | --- |
| Frequency (MHz)  | `lora.frequency` | `integer` (Hz in API) | ✅ | min: 137 MHz, max: 1020 MHz | `433000000` (433 MHz) | UI displays MHz, API stores Hz |
| Spreading Factor | `lora.spreadingFactor` | `integer` (enum) | ✅ | 6–12 | `7` | Select: SF6, SF7, SF8, SF9, SF10, SF11, SF12 |
| Bandwidth (Hz) | `lora.bandwidth` | `integer` (enum) | ✅ | Values from the list | `125000` | Select — see table below |
| Coding Rate | `lora.codingRate` | `integer` (enum) | ✅ | 5–8 | `5` | Select: 4/5, 4/6, 4/7, 4/8 |
| TX Power (dBm) | `lora.txPower` | `integer` | ✅ | min: 2, max: 20 | `20` | |
| Sync Word (hex)  | `lora.syncWord` | `integer` (hex) | ✅ | Format: `0x[0-9A-Fa-f]{2}`  | `0x12` | UI displays hex (e.g. `0x12`), API stores an integer |

**Allowed Bandwidth values**:

| Value (Hz) | UI Label  |
| --- | --- |
| 7800 | 7.8 kHz |
| 10400 | 10.4 kHz  |
| 15600 | 15.6 kHz  |
| 20800 | 20.8 kHz  |
| 31250 | 31.25 kHz |
| 41700 | 41.7 kHz  |
| 62500 | 62.5 kHz  |
| 125000 | 125 kHz |
| 250000 | 250 kHz |
| 500000 | 500 kHz |

### 5. RTCM Filtering

| Field | JSON Key | Type | Required | Validation | Default value | Notes |
| --- | --- | --- | --- | --- | --- | --- |
| Allowed Message Types | `rtcm.messageTypes` | `array<integer>` | ✅ | Min 1 element | `[1005, 1007, 1019, 1020, 1033, 1075, 1085, 1095, 1125, 1230]` | UI: textarea, comma-separated |
| High Priority Types | `rtcm.priorityMessageTypes` | `array<integer>` | ❌ | — | `[1005, 1075, 1085, 1095, 1125, 1230]` | UI: textarea, comma-separated; Types transmitted with higher priority |

---

## API Contract

All endpoints are available over HTTP on port 80 (Access Point).

### `GET /api/config` — Fetch configuration

**Response** `200 OK` — `application/json`

```json
{
  "wifi": {
    "ssid": "string",
    "password": "string",
    "timeout": 30000
  },
  "ntrip": {
    "host": "string",
    "port": 2101,
    "mountpoint": "string",
    "user": "string",
    "password": "string",
    "timeout": 10000
  },
  "gga": {
    "latitude": 50.2346,
    "longitude": 19.2084,
    "altitude": 266.0,
    "sendInterval": 2000
  },
  "lora": {
    "frequency": 433000000,
    "spreadingFactor": 7,
    "bandwidth": 125000,
    "codingRate": 5,
    "txPower": 20,
    "syncWord": 18
  },
  "rtcm": {
    "messageTypes": [
      1005, 1007, 1019, 1020, 1033, 1075, 1085, 1095, 1125, 1230
    ],
    "priorityMessageTypes": [1005, 1075, 1085, 1095, 1125, 1230]
  },
  "display": {
    "updateInterval": 500
  }
}
```

> **Note**: The `display` section is present in the API but is not exposed in the current UI.

### `POST /api/config` — Save configuration

**Request** — `Content-Type: application/json`

Body: the same structure as the response from `GET /api/config`. All sections are optional — the sections sent overwrite the existing configuration, while omitted sections remain unchanged.

**Response** `200 OK`:

```json
{ "success": true, "message": "Configuration saved. Device will restart." }
```

**Response** `400 Bad Request`:

```json
{ "success": false, "message": "Invalid JSON" }
```

```json
{ "success": false, "message": "No data received" }
```

**Response** `500 Internal Server Error`:

```json
{ "success": false, "message": "Failed to save configuration" }
```

> **Behavior**: After a successful save, the device automatically restarts after ~1s.

### `POST /api/restart` — Restart the device

**Request**: Empty body.

**Response** `200 OK`:

```json
{ "success": true, "message": "Device restarting..." }
```

### `POST /api/wifi/scan` — Scan WiFi networks

**Request**: Empty body.

**Response** `200 OK`:

```json
{
  "success": true,
  "networks": [
    {
      "ssid": "MyNetwork",
      "bssid": "AA:BB:CC:DD:EE:FF",
      "rssi": -45,
      "encryption": "secured",
      "channel": 6
    }
  ]
}
```

| Field | Type | Description |
| --- | --- | --- |
| `ssid` | `string`  | Network name |
| `bssid` | `string`  | Access point MAC address (format: `XX:XX:XX:XX:XX:XX`) |
| `rssi` | `integer` | Signal strength in dBm (higher = better) |
| `encryption` | `string`  | `"open"` or `"secured"` |
| `channel` | `integer` | WiFi channel |

**Response** `500`:

```json
{ "success": false, "message": "Scan failed" }
```

### `POST /api/ntrip/mountpoints` — Fetch NTRIP mountpoints

**Request** — `Content-Type: application/x-www-form-urlencoded`

| Parameter  | Required | Description |
| --- | --- | --- |
| `host` | ✅ | NTRIP caster host address |
| `port` | ✅ | Caster port |
| `user` | ❌ | Login (if required) |
| `password` | ❌ | Password (if required) |

**Response** `200 OK`:

```json
{
  "mountpoints": ["RTN4G_VRS_RTCM32", "NEAREST_RTN", "VRS_3_2"]
}
```

**Response** `200 OK` (error):

```json
{ "error": "Connection failed" }
```

**Response** `400 Bad Request`:

```json
{ "error": "Missing host or port parameter" }
```

---

## Validation (UI-side)

Validation happens before the form is submitted. List of rules:

| Rule | Error message |
| --- | --- |
| `wifi.ssid` is empty | "WiFi SSID is required" |
| `ntrip.host` is empty | "NTRIP host is required" |
| `ntrip.port` < 1 or > 65535 | "NTRIP port must be between 1 and 65535" |
| `gga.latitude` < -90 or > 90 | "Latitude must be between -90 and 90" |
| `gga.longitude` < -180 or > 180 | "Longitude must be between -180 and 180" |
| `lora.frequency` < 137 MHz or > 1020 MHz | "LoRa frequency out of valid range (137–1020 MHz)"  |
| `lora.spreadingFactor` < 6 or > 12 | "Spreading factor must be between 6 and 12" |
| `lora.txPower` < 2 or > 20 | "TX power must be between 2 and 20 dBm" |
| `rtcm.messageTypes` is empty | "At least one RTCM message type must be configured" |

> **Note**: Validation exists only on the UI side. The backend does not validate values — it accepts whatever it receives in valid JSON.

---

## Data conversions (UI ↔ API)

| Field | UI format | API format | Conversion |
| --- | --- | --- | --- |
| `lora.frequency` | MHz (e.g. `433.085`) | Hz (e.g. `433085000`) | UI→API: `× 1e6`, API→UI: `÷ 1e6` |
| `lora.syncWord` | Hex string (e.g. `0x12`) | Integer (e.g. `18`) | UI→API: `parseInt(val, 16)`, API→UI: `"0x" + val.toString(16)` |
| `rtcm.messageTypes` | Comma-separated string (e.g. `"1005, 1075"`) | Array of integers (e.g. `[1005, 1075]`) | UI→API: split + parseInt, API→UI: join |
| `rtcm.priorityMessageTypes` | Comma-separated string | Array of integers | same as above |

---

## Network and Access Point

- The device starts an Access Point named `OSS-LoRa-TX-XXXX` (where XXXX = the last 4 characters of the MAC)
- The AP has no password (open network)
- AP timeout: 3 minutes without a client → the AP shuts down
- After a client connects and then disconnects: 3 minutes → the AP shuts down
- The Web UI is available at `http://192.168.4.1/`

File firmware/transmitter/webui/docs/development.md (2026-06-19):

# OSS RTCM Transmitter - Development Guide

## Project Overview

Mobile-first Progressive Web App for configuring Open Survey System RTCM LoRa GNSS transmitters. Runs offline on ESP32 without internet connectivity.

## Tech Stack

- **React 18** - UI framework
- **TypeScript** - Type safety
- **Tailwind CSS v4** - Styling (mobile-first)
- **Radix UI** - Accessible component primitives (via shadcn/ui)
- **Vite 6** - Build tool
- **vite-plugin-pwa** - PWA support with service worker

## Project Structure

```
src/
├── app/
│   ├── App.tsx                 # Main application component with tabs
│   ├── components/
│   │   ├── config/             # Configuration form components (one per tab)
│   │   │   ├── WiFiConfig.tsx
│   │   │   ├── NTRIPConfig.tsx
│   │   │   ├── GGAConfig.tsx
│   │   │   ├── LoRaConfig.tsx
│   │   │   ├── RTCMConfig.tsx
│   │   │   └── RTCMMessagePicker.tsx  # Advanced RTCM message selector
│   │   ├── modals/             # Dialog/modal components
│   │   │   ├── WiFiScanModal.tsx
│   │   │   ├── MountpointsModal.tsx
│   │   │   └── HelpModal.tsx
│   │   ├── ui/                 # Reusable UI primitives (shadcn/ui)
│   │   │   ├── button.tsx
│   │   │   ├── input.tsx
│   │   │   ├── tabs.tsx
│   │   │   └── ...
│   │   └── OSSLogo.tsx         # Inline SVG logo component
│   ├── hooks/
│   │   └── useConfig.ts        # Main hook for API communication
│   ├── types/
│   │   └── config.ts           # TypeScript interfaces for config
│   └── data/
│       ├── rtcm-messages.ts    # RTCM message type definitions
│       └── help-content.ts     # Help text for each tab
├── assets/                     # Static assets imported by components
│   └── oss-logo.svg
└── styles/
    ├── theme.css               # Tailwind v4 theme tokens
    └── fonts.css               # Font imports
```

## Key Architectural Decisions

### 1. State Management

- **Single source of truth**: `useConfig` hook manages all configuration state
- **Local state only**: No global state management (Redux/Zustand) - not needed for this app
- **Optimistic updates**: UI updates immediately, API calls in background

### 2. API Communication

All API calls go through `src/app/hooks/useConfig.ts`:

- `GET /api/config` - Load configuration on mount
- `POST /api/config` - Save configuration (triggers device restart)
- `POST /api/restart` - Restart device without saving
- `POST /api/wifi/scan` - Scan WiFi networks
- `POST /api/ntrip/mountpoints` - Fetch NTRIP mountpoints

**Important**: ESP32 backend does NOT validate input - validation is UI-only.

### 3. Mobile-First Design

- All components use responsive breakpoints: `sm:`, `md:`, etc.
- Touch targets minimum 44px for buttons/checkboxes
- Compact spacing on mobile, more generous on desktop
- Fixed bottom bar for primary actions (Save, Reload, Help, Restart)

### 4. PWA Considerations

- **Offline-first**: All dependencies bundled, no CDN
- **Service worker**: Auto-generated by vite-plugin-pwa
- **Geolocation**: Works in PWA installed mode, gracefully degrades in browser
- **Manifest**: Configured in `vite.config.ts`

## Coding Conventions

### TypeScript

- All new files must be `.tsx` (React) or `.ts` (utilities)
- Use `interface` for public APIs, `type` for unions/intersections
- Prefer explicit return types for exported functions
- Use `Config['section']` for partial config types

### React Components

- Functional components only (no class components)
- Props interfaces named `ComponentNameProps`
- Export component as named export (not default) for consistency
- Use controlled components for all form inputs

### Styling

- **Tailwind only** - no inline styles, no CSS modules
- Use `cn()` utility from `src/app/components/ui/utils.ts` for conditional classes
- Prefer Tailwind utility classes over custom CSS
- Font sizes/weights come from `theme.css` - don't override with Tailwind classes

### Form Handling

- Controlled inputs with `value` and `onChange`
- Validation happens on submit (in `handleSave` in `App.tsx`)
- Show validation errors via `toast.error()` from `sonner`
- No form libraries (react-hook-form installed but not used currently)

### Data Transformations

Some fields require conversion between UI and API format:

- **LoRa Frequency**: UI in MHz, API in Hz (multiply by 1e6)
- **LoRa Sync Word**: UI as hex string `0x12`, API as integer `18`
- **RTCM Message Types**: UI as comma-separated, API as array of integers

See examples in `LoRaConfig.tsx` and `RTCMConfig.tsx`.

## Adding New Features

### Adding a New Configuration Tab

1. **Update TypeScript types** in `src/app/types/config.ts`:

```typescript
export interface Config {
  // ... existing fields
  newSection: {
    field1: string;
    field2: number;
  };
}
```

2. **Create form component** in `src/app/components/config/`:

```typescript
// NewSectionConfig.tsx
import { Input } from '../ui/input';
import { Label } from '../ui/label';
import type { Config } from '../../types/config';

interface NewSectionConfigProps {
  config: Config['newSection'];
  onChange: (newSection: Config['newSection']) => void;
}

export function NewSectionConfig({ config, onChange }: NewSectionConfigProps) {
  return (
    <div className="space-y-4">
      <div className="space-y-2">
        <Label htmlFor="field1">Field 1 *</Label>
        <Input
          id="field1"
          value={config.field1}
          onChange={(e) => onChange({ ...config, field1: e.target.value })}
          required
        />
      </div>
    </div>
  );
}
```

3. **Add tab to App.tsx**:

```typescript
// Add to TabsList
<TabsTrigger value="newsection">New Section</TabsTrigger>

// Add TabsContent
<TabsContent value="newsection">
  <NewSectionConfig
    config={config.newSection}
    onChange={(newSection) => setConfig({ ...config, newSection })}
  />
</TabsContent>
```

4. **Add help content** in `src/app/data/help-content.ts`:

```typescript
export const HELP_CONTENT: Record<string, HelpContent> = {
  // ... existing content
  newsection: {
    title: "New Section Configuration",
    content: `Help text here...`,
  },
};
```

5. **Update validation** in `handleSave()` in `App.tsx` if needed.

### Adding a New UI Component

Use shadcn/ui CLI or copy from existing components:

```bash
# If component exists in shadcn/ui registry
npx shadcn@latest add <component-name>

# Otherwise, create manually in src/app/components/ui/
```

### Adding API Integration

Add new methods to `useConfig` hook:

```typescript
export function useConfig() {
  // ... existing state

  const newApiCall = async (params: string): Promise<SomeType> => {
    setLoading(true);
    setError(null);
    try {
      const response = await fetch(`${API_BASE}/new-endpoint`, {
        method: "POST",
        headers: { "Content-Type": "application/json" },
        body: JSON.stringify({ params }),
      });
      const data = await response.json();
      if (!response.ok) throw new Error(data.message);
      return data.result;
    } catch (err) {
      setError(err instanceof Error ? err.message : "Unknown error");
      return defaultValue;
    } finally {
      setLoading(false);
    }
  };

  return {
    // ... existing exports
    newApiCall,
  };
}
```

## Build & Deployment

### Development

```bash
# Dev server (Figma Make or localhost)
vite dev
```

### Production Build for ESP32

```bash
# Build with relative paths for ESP32
pnpm run build:esp32

# Output: dist-esp32/
# Upload entire directory to ESP32 SPIFFS/LittleFS
```

### Regenerate PWA Icons

```bash
# After updating public/oss-logo.svg
pnpm run generate:icons
```

## Testing Notes

- **Geolocation**: Only works in HTTPS or localhost context
- **PWA**: Only works in production build, not dev server
- **API mocking**: No mock server - test against real ESP32 or stub responses in `useConfig.ts`
- **Responsiveness**: Test on iPhone SE (375px) and iPad (768px) viewports

## Common Issues

### Images/SVG not loading

- Use imports: `import logo from '../assets/logo.svg'`
- Or inline SVG components (like `OSSLogo.tsx`)
- Avoid direct `/public` paths - they don't work in build

### Tailwind classes not applying

- Check `theme.css` for token overrides
- Avoid text-_ and font-_ classes (defined in theme)
- Use `cn()` for conditional classes

### Form not submitting

- Check validation in `handleSave()`
- Ensure all required fields have values
- Check browser console for API errors

### PWA not installing

- Build with `pnpm run build:esp32`
- Serve over HTTPS or localhost
- Check manifest.json is accessible

## Dependencies Notes

- **Radix UI**: Don't upgrade without testing - breaking changes common
- **Tailwind v4**: Uses different syntax than v3 (CSS-first, not config file)
- **Vite PWA**: Check plugin docs before modifying workbox config
- **Sharp**: Used only for icon generation, not runtime dependency

## Resources

- ESP32 API docs: See `src/imports/config-structure.md`
- RTCM message types: https://www.use-snip.com/kb/knowledge-base/rtcm-3-message-list/
- Tailwind v4 docs: https://tailwindcss.com/docs
- Radix UI: https://www.radix-ui.com/primitives

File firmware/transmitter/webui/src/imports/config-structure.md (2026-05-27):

# Struktura konfiguracji — Web UI

Dokument opisuje strukturę konfiguracji urządzenia RTCM LoRa Transmitter eksponowaną przez Web UI.
Służy jako input do pracy nad redesignem interfejsu w Figmie.

---

## Nawigacja UI

Interfejs podzielony jest na **5 zakładek (tabów)**:

| # | Tab ID  | Etykieta | Opis |
| --- | --- | --- | --- |
| 1 | `wifi`  | WiFi | Konfiguracja połączenia WiFi |
| 2 | `ntrip` | NTRIP | Konfiguracja castera NTRIP |
| 3 | `gga` | GGA Position | Pozycja stacji bazowej (GGA) |
| 4 | `lora`  | LoRa Radio | Parametry radia LoRa (SX1276) |
| 5 | `rtcm`  | RTCM Filtering | Filtrowanie typów wiadomości RTCM |

### Globalne akcje (poza tabami)

| Akcja | Typ | Zachowanie |
| --- | --- | --- |
| Save & Restart | Submit (primary) | Walidacja → confirm dialog → POST config → restart urządzenia |
| Reload Config  | Button (secondary) | Pobiera aktualną konfigurację z urządzenia |
| Restart Device | Button (danger) | Confirm dialog → restart urządzenia |

---

## Sekcje konfiguracji — szczegóły pól

### 1. WiFi

| Pole | Klucz JSON | Typ | Wymagane | Walidacja | Wartość domyślna | Uwagi |
| --- | --- | --- | --- | --- | --- | --- |
| WiFi Network (SSID) | `wifi.ssid` | `string` | ✅ | Niepuste | `""` | Posiada akcję "Scan" — otwiera modal z listą dostępnych sieci |
| Password | `wifi.password` | `string` (password) | ❌ | — | `""` | Puste = sieć otwarta |
| Connection Timeout  | `wifi.timeout`  | `integer` (ms) | ✅ | min: 5000, max: 60000, step: 1000 | `30000` | |

**Dodatkowa funkcjonalność**: Modal skanowania WiFi

- Wyświetla listę sieci posortowaną po RSSI (siła sygnału)
- Każda sieć pokazuje: SSID, BSSID, kanał, RSSI (dBm), typ szyfrowania (open/secured), ikonę siły sygnału
- Kliknięcie na sieć wstawia SSID do pola formularza
- Przycisk Rescan pozwala ponowić skanowanie

### 2. NTRIP

| Pole | Klucz JSON | Typ | Wymagane | Walidacja | Wartość domyślna | Uwagi |
| --- | --- | --- | --- | --- | --- | --- |
| Host | `ntrip.host` | `string` | ✅ | Niepuste | `"91.198.76.2"` | |
| Port | `ntrip.port` | `integer` | ✅ | min: 1, max: 65535 | `2101` | |
| Username | `ntrip.user` | `string` | ❌ | — | `""` | |
| Password | `ntrip.password` | `string` (password) | ❌ | — | `""` | |
| Mountpoint | `ntrip.mountpoint` | `string` | ✅ | Niepuste | `"RTN4G_VRS_RTCM32"` | Posiada akcję "Fetch" — otwiera modal z listą mountpointów |
| Connection Timeout | `ntrip.timeout` | `integer` (ms) | ✅ | min: 5000, max: 60000, step: 1000 | `10000` | |

**Dodatkowa funkcjonalność**: Modal pobierania mountpointów

- Wymaga wcześniejszego wypełnienia pól Host i Port (walidacja przed otwarciem)
- Wysyła zapytanie do castera NTRIP z podanymi danymi uwierzytelniającymi
- Wyświetla listę nazw mountpointów
- Kliknięcie na mountpoint wstawia jego nazwę do pola formularza
- Przycisk Refresh pozwala ponowić pobieranie

### 3. GGA Position

| Pole | Klucz JSON | Typ | Wymagane | Walidacja | Wartość domyślna | Uwagi |
| --- | --- | --- | --- | --- | --- | --- |
| Latitude (°) | `gga.latitude` | `float` | ✅ | min: -90, max: 90, step: 0.0001 | `50.2346` | Stopnie dziesiętne, dodatnie = North |
| Longitude (°) | `gga.longitude` | `float` | ✅ | min: -180, max: 180, step: 0.0001 | `19.2084` | Stopnie dziesiętne |
| Altitude (m) | `gga.altitude` | `float` | ✅ | step: 0.1 | `266.0` | Metry n.p.m. |
| Send Interval (ms) | `gga.sendInterval` | `integer` (ms) | ✅ | min: 1000, max: 60000, step: 1000 | `2000` | Interwał wysyłania GGA do castera NTRIP |

### 4. LoRa Radio

| Pole | Klucz JSON | Typ | Wymagane | Walidacja | Wartość domyślna | Uwagi |
| --- | --- | --- | --- | --- | --- | --- |
| Frequency (MHz)  | `lora.frequency` | `integer` (Hz w API) | ✅ | min: 137 MHz, max: 1020 MHz | `433000000` (433 MHz) | UI wyświetla MHz, API przechowuje Hz |
| Spreading Factor | `lora.spreadingFactor` | `integer` (enum) | ✅ | 6–12 | `7` | Select: SF6, SF7, SF8, SF9, SF10, SF11, SF12 |
| Bandwidth (Hz) | `lora.bandwidth` | `integer` (enum) | ✅ | Wartości z listy | `125000` | Select — patrz tabela niżej |
| Coding Rate | `lora.codingRate` | `integer` (enum) | ✅ | 5–8 | `5` | Select: 4/5, 4/6, 4/7, 4/8 |
| TX Power (dBm) | `lora.txPower` | `integer` | ✅ | min: 2, max: 20 | `20` | |
| Sync Word (hex)  | `lora.syncWord` | `integer` (hex) | ✅ | Format: `0x[0-9A-Fa-f]{2}`  | `0x12` | UI wyświetla hex (np. `0x12`), API przechowuje integer |

**Dozwolone wartości Bandwidth**:

| Wartość (Hz) | Etykieta UI |
| --- | --- |
| 7800 | 7.8 kHz |
| 10400 | 10.4 kHz |
| 15600 | 15.6 kHz |
| 20800 | 20.8 kHz |
| 31250 | 31.25 kHz |
| 41700 | 41.7 kHz |
| 62500 | 62.5 kHz |
| 125000 | 125 kHz |
| 250000 | 250 kHz |
| 500000 | 500 kHz |

### 5. RTCM Filtering

| Pole | Klucz JSON | Typ | Wymagane | Walidacja | Wartość domyślna | Uwagi |
| --- | --- | --- | --- | --- | --- | --- |
| Allowed Message Types | `rtcm.messageTypes` | `array<integer>` | ✅ | Min 1 element | `[1005, 1007, 1019, 1020, 1033, 1075, 1085, 1095, 1125, 1230]` | UI: textarea, comma-separated |
| High Priority Types | `rtcm.priorityMessageTypes` | `array<integer>` | ❌ | — | `[1005, 1075, 1085, 1095, 1125, 1230]` | UI: textarea, comma-separated; Typy transmitowane z wyższym priorytetem |

---

## Kontrakt API

Wszystkie endpointy dostępne po HTTP na porcie 80 (Access Point).

### `GET /api/config` — Pobranie konfiguracji

**Response** `200 OK` — `application/json`

```json
{
  "wifi": {
    "ssid": "string",
    "password": "string",
    "timeout": 30000
  },
  "ntrip": {
    "host": "string",
    "port": 2101,
    "mountpoint": "string",
    "user": "string",
    "password": "string",
    "timeout": 10000
  },
  "gga": {
    "latitude": 50.2346,
    "longitude": 19.2084,
    "altitude": 266.0,
    "sendInterval": 2000
  },
  "lora": {
    "frequency": 433000000,
    "spreadingFactor": 7,
    "bandwidth": 125000,
    "codingRate": 5,
    "txPower": 20,
    "syncWord": 18
  },
  "rtcm": {
    "messageTypes": [
      1005, 1007, 1019, 1020, 1033, 1075, 1085, 1095, 1125, 1230
    ],
    "priorityMessageTypes": [1005, 1075, 1085, 1095, 1125, 1230]
  },
  "display": {
    "updateInterval": 500
  }
}
```

> **Uwaga**: Sekcja `display` jest obecna w API, ale nie jest eksponowana w obecnym UI.

### `POST /api/config` — Zapis konfiguracji

**Request** — `Content-Type: application/json`

Body: taka sama struktura jak response z `GET /api/config`. Wszystkie sekcje są opcjonalne — wysłane sekcje nadpisują istniejącą konfigurację, pominięte pozostają bez zmian.

**Response** `200 OK`:

```json
{ "success": true, "message": "Configuration saved. Device will restart." }
```

**Response** `400 Bad Request`:

```json
{ "success": false, "message": "Invalid JSON" }
```

```json
{ "success": false, "message": "No data received" }
```

**Response** `500 Internal Server Error`:

```json
{ "success": false, "message": "Failed to save configuration" }
```

> **Zachowanie**: Po udanym zapisie urządzenie automatycznie restartuje się po ~1s.

### `POST /api/restart` — Restart urządzenia

**Request**: Pusty body.

**Response** `200 OK`:

```json
{ "success": true, "message": "Device restarting..." }
```

### `POST /api/wifi/scan` — Skanowanie sieci WiFi

**Request**: Pusty body.

**Response** `200 OK`:

```json
{
  "success": true,
  "networks": [
    {
      "ssid": "MyNetwork",
      "bssid": "AA:BB:CC:DD:EE:FF",
      "rssi": -45,
      "encryption": "secured",
      "channel": 6
    }
  ]
}
```

| Pole | Typ | Opis |
| --- | --- | --- |
| `ssid` | `string`  | Nazwa sieci |
| `bssid` | `string`  | Adres MAC access pointa (format: `XX:XX:XX:XX:XX:XX`) |
| `rssi` | `integer` | Siła sygnału w dBm (wyższa = lepsza) |
| `encryption` | `string`  | `"open"` lub `"secured"` |
| `channel` | `integer` | Kanał WiFi |

**Response** `500`:

```json
{ "success": false, "message": "Scan failed" }
```

### `POST /api/ntrip/mountpoints` — Pobranie mountpointów NTRIP

**Request** — `Content-Type: application/x-www-form-urlencoded`

| Parametr | Wymagany | Opis |
| --- | --- | --- |
| `host` | ✅ | Adres hosta castera NTRIP |
| `port` | ✅ | Port castera |
| `user` | ❌ | Login (jeśli wymagany) |
| `password` | ❌ | Hasło (jeśli wymagane) |

**Response** `200 OK`:

```json
{
  "mountpoints": ["RTN4G_VRS_RTCM32", "NEAREST_RTN", "VRS_3_2"]
}
```

**Response** `200 OK` (błąd):

```json
{ "error": "Connection failed" }
```

**Response** `400 Bad Request`:

```json
{ "error": "Missing host or port parameter" }
```

---

## Walidacja (po stronie UI)

Walidacja odbywa się przed wysłaniem formularza. Lista reguł:

| Reguła | Komunikat błędu |
| --- | --- |
| `wifi.ssid` jest puste | "WiFi SSID is required" |
| `ntrip.host` jest puste | "NTRIP host is required" |
| `ntrip.port` < 1 lub > 65535 | "NTRIP port must be between 1 and 65535" |
| `gga.latitude` < -90 lub > 90 | "Latitude must be between -90 and 90" |
| `gga.longitude` < -180 lub > 180 | "Longitude must be between -180 and 180" |
| `lora.frequency` < 137 MHz lub > 1020 MHz | "LoRa frequency out of valid range (137–1020 MHz)"  |
| `lora.spreadingFactor` < 6 lub > 12 | "Spreading factor must be between 6 and 12" |
| `lora.txPower` < 2 lub > 20 | "TX power must be between 2 and 20 dBm" |
| `rtcm.messageTypes` jest puste | "At least one RTCM message type must be configured" |

> **Uwaga**: Walidacja istnieje tylko po stronie UI. Backend nie wykonuje walidacji wartości — przyjmuje to, co dostanie w poprawnym JSON-ie.

---

## Konwersje danych (UI ↔ API)

| Pole | Format UI | Format API | Konwersja |
| --- | --- | --- | --- |
| `lora.frequency` | MHz (np. `433.085`) | Hz (np. `433085000`) | UI→API: `× 1e6`, API→UI: `÷ 1e6` |
| `lora.syncWord` | Hex string (np. `0x12`) | Integer (np. `18`) | UI→API: `parseInt(val, 16)`, API→UI: `"0x" + val.toString(16)` |
| `rtcm.messageTypes` | Comma-separated string (np. `"1005, 1075"`) | Array of integers (np. `[1005, 1075]`) | UI→API: split + parseInt, API→UI: join |
| `rtcm.priorityMessageTypes` | Comma-separated string | Array of integers | j.w. |

---

## Sieć i Access Point

- Urządzenie startuje Access Point o nazwie `OSS-LoRa-TX-XXXX` (gdzie XXXX = ostatnie 4 znaki MAC)
- AP nie ma hasła (sieć otwarta)
- AP timeout: 3 minuty bez klienta → AP się wyłącza
- Po podłączeniu klienta i jego rozłączeniu: 3 minuty → AP się wyłącza
- Web UI dostępne pod `http://192.168.4.1/`

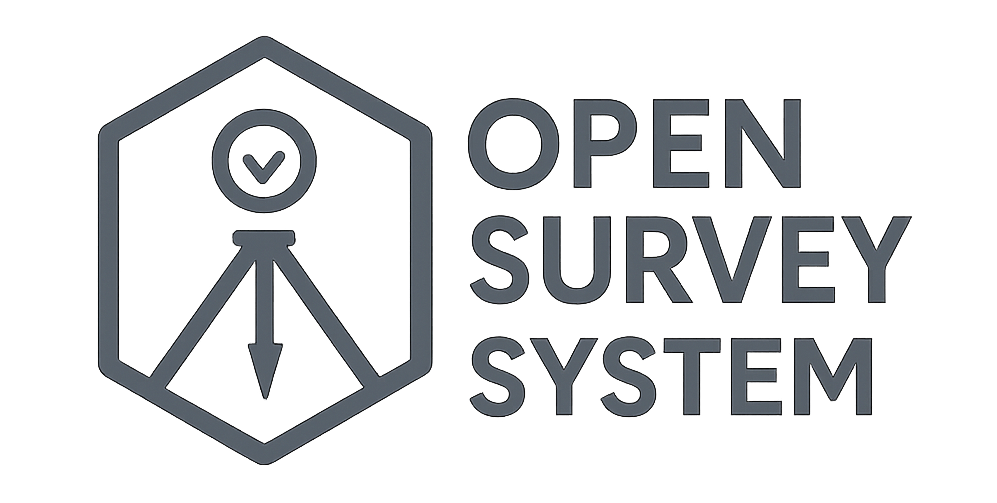
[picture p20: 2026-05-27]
hardware/rover/docs/oss.png

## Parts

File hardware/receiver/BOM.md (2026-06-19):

# Receiver (LoRa/Wi‑Fi Gateway) — Bill of Materials

ESP32 + SX1276 gateway that receives RTCM3 corrections over a **433 MHz LoRa**
link, reassembles them, and re-serves them to nearby GNSS rovers through a local
NTRIP caster on its own WiFi access point. Built around a commodity LoRa
development board (no custom PCB), so this BOM lists ready-made modules and the
few external parts that complete the build.

## Core

| Qty | Part | Description | Notes | Est. USD |
| --- | --- | --- | --- | --- |
| 1 | LoRa dev board: **TTGO LoRa32 V2.1** | ESP32 + SX1276 (433 MHz) + SSD1306 OLED | Firmware env `ttgo-lora32-v21`  | 18–28 |
| 1 | 433 MHz LoRa antenna | SMA dipole; yagi/directional for range  | Must be 433 MHz, not 868/915 | 3–10 |
| 1 | Passive buzzer | Audible pulse on every valid RTCM frame | Driven from **GPIO4** | <1 |
| 1 | 18650 Li-ion cell (3.7 V) or USB-C supply | Field power | LoRa32 V2.1 has an 18650 holder | 5–9 |
| 1 | USB-C cable | Programming / power | — | 2–4 |

## Optional / mechanical

| Qty | Part | Description | Est. USD |
| --- | --- | --- | --- |
| 1 | SSD1306 128x64 OLED | Only if board variant lacks the onboard display | 3–5 |
| 1 | Enclosure (weatherproof if outdoor) | Field deployment | 5–20 |
| 1 | SMA pigtail / extension | Mount antenna externally | 2–5 |

**Indicative total:** ~$30–50 (LoRa32 V2.1 + 433 MHz antenna + buzzer + battery).

## SX1276 pinout (TTGO LoRa32 V2.1)

```
NSS  → GPIO18    MOSI → GPIO27    MISO → GPIO19
SCK  → GPIO5     RST  → GPIO14    DIO0 → GPIO26
```

## OLED (SSD1306 128x64)

```
I2C: SDA → GPIO21, SCL → GPIO22, RST → GPIO16
```

## Buzzer

```
Signal → GPIO4 (non-blocking pulse on valid RTCM frame)
```

## LoRa radio parameters (must match transmitter)

| Parameter | Value |
| --- | --- |
| Frequency | 433.7 MHz (`433700000`) |
| Spreading factor | 7 |
| Bandwidth | 500 kHz |
| Coding rate | 4/5 |
| TX power | 20 dBm |
| Sync word | 0x12 |

> ⚠️ These radio parameters must be identical to the transmitter or the link
> fails silently.

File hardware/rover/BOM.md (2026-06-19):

# Rover — Bill of Materials

Portable dual-frequency GNSS RTK receiver with a Bluetooth link to a mobile
app. This BOM is derived from the KiCad schematic
([`kicad/rover.kicad_sch`](kicad/rover.kicad_sch)) and is the authoritative
parts list for the custom rover PCB. A machine-readable copy is in
[`bom.csv`](bom.csv).

> The schematic uses an **ESP32-C3 (Wemos C3 mini)** MCU plus an **HC-05**
> classic Bluetooth SPP module over UART. (The rover firmware README also
> documents a BLE-only variant on a Wemos D1 Mini32; the schematic below is the
> built reference design.)

## Modules / sockets

| Ref | Qty | Part | Description | Notes | Est. USD |
| --- | --- | --- | --- | --- | --- |
| U2  | 1 | Wemos C3 mini (ESP32-C3) | Main MCU — UART↔BLE/SPP bridge, OTA | `RF_Module:WEMOS_C3_mini` footprint | 4–6 |
| J1  | 1 | Quectel LC29H (DA) socket | Dual-band, dual-antenna RTK GNSS module  | Mounted on `LC29H` socket | 35–55 |
| J2  | 1 | HC-05 socket | Classic Bluetooth SPP module (UART) | `HC05` socket | 4–7 |
| J3  | 1 | BMS FM5324 socket | Li-ion battery management / power module | `BMS_FM5324` socket | 3–6 |
| J4  | 1 | Battery connector (1x02, 2.54 mm) | Li-ion cell input | PinHeader 1x02 horizontal | <1 |
| J5  | 1 | Control-panel socket | Buttons / status LED breakout | `RTK_ControlPanel` socket | 1–2 |

## Passives

| Ref | Qty | Value  | Package | Notes |
| --- | --- | --- | --- | --- |
| C1, C2, C5 | 3 | 100 nF | Disc THT (D3.0 mm, P2.5 mm) | MCU/module decoupling |
| C7 | 1 | 10 µF  | Radial electrolytic (D4.0 mm, P2.0 mm) | Bulk decoupling |
| C6 | 1 | 100 µF | Radial electrolytic (D5.0 mm, P2.5 mm) | Bulk / power rail |
| R1, R2 | 2 | 300 Ω  | Axial THT (DIN0204) | LED / current-limit |

## Off-board / mechanical (not on schematic)

| Qty | Part | Description | Est. USD |
| --- | --- | --- | --- |
| 1 | Li-ion battery (e.g. 18650, ~3000 mAh, 3.7 V) | ~20–30 h runtime per firmware estimate | 5–9 |
| 1 | GNSS antenna (L1/L2/L5 multi-band, e.g. helical/patch) | Required for LC29H DA RTK | 20–40 |
| 1 | Antenna cable / SMA pigtail | Match module connector (U.FL→SMA) | 2–4 |
| 1 | Enclosure | See `imgs/enclosure*.png` in repo root | 5–15 |
| 1 | USB-C cable | Programming / charging | 2–4 |
| — | PCB fabrication | See [`gerber/`](gerber/) | 2–10 |

**Indicative total (excl. enclosure/antenna):** ~$60–100 depending on the GNSS
module and supplier.

## Pinout reference (ESP32 ↔ LC29H DA)

```
LC29H DA UART1_TX → ESP32 GPIO25 (RX)
LC29H DA UART1_RX ← ESP32 GPIO27 (TX)
VCC 3.3–5V (via power module), common GND
Baud 115200, 8N1, no flow control
```

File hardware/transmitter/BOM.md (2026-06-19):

# Transmitter (LTE/LoRa Gateway) — Bill of Materials

ESP32 + SX1276 gateway that fetches RTCM3 corrections from an NTRIP caster over
WiFi and retransmits them via **LoRa 433 MHz** to the receiver. Built around a
commodity LoRa development board (no custom PCB), so this BOM lists ready-made
modules and the few external parts that complete the build.

## Core

| Qty | Part | Description | Notes | Est. USD |
| --- | --- | --- | --- | --- |
| 1 | LoRa dev board: **TTGO T-Beam V1.1** (recommended) or LoRa32 | ESP32 + SX1276 (433 MHz) + SSD1306 OLED | T-Beam adds GPS + 18650 holder + PMU; firmware env `ttgo-t-beam` | 22–35 |
| 1 | 433 MHz LoRa antenna | SMA dipole; yagi/directional for range  | Must be 433 MHz, not 868/915 | 3–10 |
| 1 | 18650 Li-ion cell (3.7 V) | Field power; holder is on the T-Beam | Or power via USB-C | 5–9 |
| 1 | USB-C cable | Programming / power | — | 2–4 |

## Optional / mechanical

| Qty | Part | Description | Est. USD |
| --- | --- | --- | --- |
| 1 | SSD1306 128x64 OLED | Only if the board lacks one (LoRa32 variants) | 3–5 |
| 1 | WiFi/LTE uplink | Onboard ESP32 WiFi, or external LTE router/hotspot for internet path | varies |
| 1 | Enclosure (weatherproof if outdoor) | Field deployment | 5–20 |
| 1 | SMA pigtail / extension | Mount antenna externally | 2–5 |

**Indicative total:** ~$35–60 (T-Beam + 433 MHz antenna + battery).

## SX1276 pinout (T-Beam predefined)

```
NSS  → GPIO18    MOSI → GPIO27    MISO → GPIO19
SCK  → GPIO5     RST  → GPIO23    DIO0 → GPIO26
```

## OLED (SSD1306 128x64)

```
I2C: SDA → GPIO21, SCL → GPIO22
```

## LoRa radio parameters (must match receiver)

| Parameter | Value |
| --- | --- |
| Frequency | 433 MHz (433.7 MHz to match receiver default) |
| Spreading factor | 7 |
| Bandwidth | 125 kHz (receiver default is 500 kHz — keep both identical) |
| Coding rate | 4/5 |
| TX power | 20 dBm (SX1276 max) |
| Sync word | 0x12 |

> ⚠️ The LoRa radio parameters (frequency, SF, bandwidth, sync word) must be
> identical on transmitter and receiver or the link fails silently.

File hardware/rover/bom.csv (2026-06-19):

Reference | Qty | Value | Footprint | Description
U2 | 1 | WEMOS_C3_mini | RF_Module:WEMOS_C3_mini | ESP32-C3 MCU module (UART/BLE/SPP bridge)
J1 | 1 | LC29HDA_Socket | OpenRTK:LC29H | Quectel LC29H DA dual-band RTK GNSS module socket
J2 | 1 | HC05_Socket | OpenRTK:HC05 | HC-05 classic Bluetooth SPP module socket
J3 | 1 | BMS_Socket | OpenRTK:BMS_FM5324 | FM5324 Li-ion battery management module socket
J4 | 1 | BATT_Socket | Connector_PinHeader_2.54mm:PinHeader_1x02_P2.54mm_Horizontal | Battery connector 1x02 2.54mm
J5 | 1 | CP_Socket | OpenRTK:RTK_ControlPanel | Control panel (buttons/LED) socket
C1 | 1 | 100n | Capacitor_THT:C_Disc_D3.0mm_W1.6mm_P2.50mm | Decoupling capacitor
C2 | 1 | 100n | Capacitor_THT:C_Disc_D3.0mm_W1.6mm_P2.50mm | Decoupling capacitor
C5 | 1 | 100n | Capacitor_THT:C_Disc_D3.0mm_W1.6mm_P2.50mm | Decoupling capacitor
C6 | 1 | 100uF | Capacitor_THT:CP_Radial_D5.0mm_P2.50mm | Bulk electrolytic capacitor
C7 | 1 | 10uF | Capacitor_THT:CP_Radial_D4.0mm_P2.00mm | Bulk electrolytic capacitor
R1 | 1 | 300R | Resistor_THT:R_Axial_DIN0204_L3.6mm_D1.6mm_P7.62mm_Horizontal | Current-limit/LED resistor
R2 | 1 | 300R | Resistor_THT:R_Axial_DIN0204_L3.6mm_D1.6mm_P7.62mm_Horizontal | Current-limit/LED resistor

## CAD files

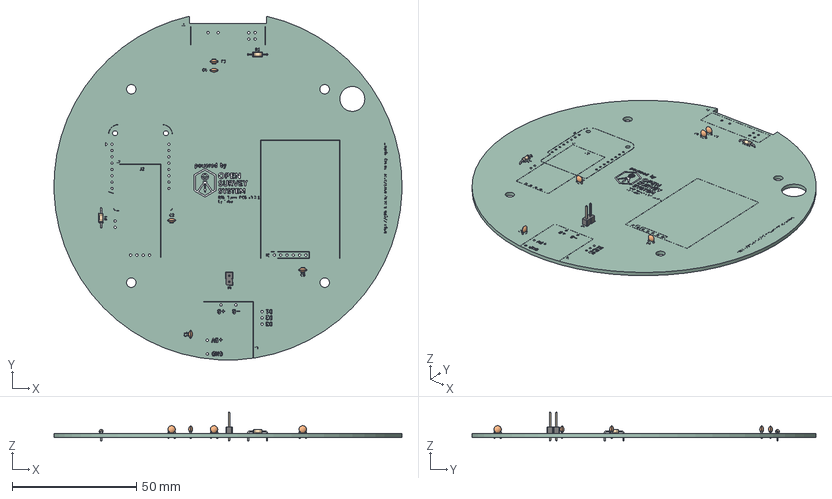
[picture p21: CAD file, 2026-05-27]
hardware/rover/rover.step
139.9 x 138.2 x 11.5 mm
C_Disc_D3.0mm_W1.6mm_P2.50mm x 5
R_Axial_DIN0204_L3.6mm_D1.6mm_P7.62mm_Horizontal x 2
PinHeader_1x02_P2.54mm_Vertical
rover_silkscreen
rover_PCB

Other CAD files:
hardware/rover/rover.stl

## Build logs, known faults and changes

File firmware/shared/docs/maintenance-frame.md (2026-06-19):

# Maintenance Frame — Implementation

> **Canonical, shared specification.** This document is the single source of truth for the
> LoRa **maintenance/command channel** (`FRAME_MAINTENANCE` / `FRAME_COMMAND`) between the
> **OSS Transmitter** and the **OSS Receiver**. Both firmwares must stay byte-compatible
> with it. The device-specific file (`transmitter/docs/maintenance-frame.md`) redirects here.
> See also the base packet format in [`lora-protocol.md`](lora-protocol.md).

## Overview

The Maintenance Frame feature extends the OSS RTK Transmitter with a bidirectional telemetry and remote-control channel over the existing LoRa link.

**How it works:**

1. Every N minutes (configurable), the transmitter broadcasts a **maintenance frame** containing basic telemetry.
2. Immediately after, it enters **listen mode** for M seconds (configurable).
3. During the listen window, a receiver on the other side may send a **command frame** back.
4. The transmitter parses the command and dispatches it to a registered handler.

**Deferred stop mode** (optional): after a configurable active TX window (default 5 min) **measured from power-on**, the transmitter halts RTCM transmission and enters `STATE_STANDBY`. In standby the radio stays in continuous RX and periodic maintenance frames are still sent. Transmission resumes on receipt of `CMD_START`.

> **Important:** `CMD_START` permanently cancels the deferred-stop timer for the current session (`deferredStopCancelled = true`). After a manual start the device transmits indefinitely — the active TX window no longer applies until the next power cycle. Only `CMD_STOP` or a power cycle can return the device to standby.

---

## 1. Protocol Changes

### Previous packet header (4 bytes):

```
[msgID 1B][totalPkts 1B][pktNum 1B][dataLen 1B][data 0–246B]
```

### New packet header (5 bytes — Protocol v2):

```
[frameType 1B][msgID 1B][totalPkts 1B][pktNum 1B][dataLen 1B][data 0–245B]
```

| `frameType` | Symbol | Description |
| --- | --- | --- |
| `0x01` | `FRAME_RTCM` | RTCM correction data (existing traffic) |
| `0x02` | `FRAME_MAINTENANCE` | Telemetry broadcast (TX → air) |
| `0x03` | `FRAME_COMMAND` | Control command (RX → transmitter) |
| `0x04` | `FRAME_ACK` | Optional acknowledgement |

`HEADER_SIZE` changed from 4 → 5; `MAX_DATA_PER_PACKET` from 246 → 245.

---

## 2. Payload Formats

### 2a. Maintenance Frame Payload (18 bytes fixed + TLV extension)

```
+----------+----------+-------+------+----------+----------+-------+-----------+
| uptime   | batt_mv  | rssi  | snr  | rtcm_rx  | rtcm_tx  | flags | reserved  |
| uint32   | uint16   | int8  | int8 | uint32   | uint32   | uint8 | uint8[1]  |
+----------+----------+-------+------+----------+----------+-------+-----------+
  4B         2B         1B      1B     4B          4B         1B      1B   = 18B
```

**`flags` bitmask:**

- bit 0 — `ntrip_connected`
- bit 1 — `wifi_connected`
- bit 2 — `battery_valid`
- bits 3–7 — reserved

**TLV extension block** (variable length, follows fixed part):

```
[tag 1B][len 1B][value lenB] ...
```

| Tag | Content | Built-in |
| --- | --- | --- |
| `0x01` | Custom label string (max 32 chars) | no |
| `0x02` | Free heap (uint32 LE) | **yes**  |
| `0x03` | Chip temperature (int8, °C) | no |
| `0x04` | RTCM frames overwritten count (uint32 LE) | no |

Custom TLV providers can be added at runtime via `registerTLVField()`.

### 2b. Command Frame Payload

```
[frameType=0x03 1B][msgId 1B][totalPkts 1B][pktNum 1B][dataLen 1B][commandId 1B][payloadLen 1B][payload 0–243B]
```

| ID | Symbol | Payload | Default enabled |
| --- | --- | --- | --- |
| `0x01` | `CMD_RESET` | none | ✓ |
| `0x02` | `CMD_SLEEP` | `uint32` LE seconds | ✗ |
| `0x03` | `CMD_HTTP_GET`  | null-terminated URL | ✗ |
| `0x04` | `CMD_SET_PARAM` | `key\0value\0` | ✗ |
| `0x05` | `CMD_PING` | none | ✓ |
| `0x06` | `CMD_LOGLEVEL`  | `uint8` level | ✗ |
| `0x07` | `CMD_START` | none | ✗ |
| `0x08` | `CMD_STOP` | none | ✗ |

Commands not on the `enabledCommands` whitelist are silently ignored.

---

## 3. System States

```cpp
enum SystemState {
    STATE_INIT,
    STATE_RUNNING,          // Normal RTCM TX operation
    STATE_MAINTENANCE_TX,   // Transmitting maintenance frame (Core 0)
    STATE_MAINTENANCE_RX,   // Listening for command in RX mode (Core 0)
    STATE_STANDBY,          // RTCM TX halted, LoRa in continuous RX
    STATE_ERROR
};
```

OLED display strings: `RUNNING` / `MAINT TX` / `MAINT RX` / `STANDBY` / `ERROR`.

---

## 4. Component: `MaintenanceManager`

### Files

- `include/maintenance_manager.h`
- `src/maintenance_manager.cpp`

### Public API

```cpp
class MaintenanceManager {
public:
    MaintenanceManager(ConfigManager& configMgr, volatile SystemState* statePtr);

    // Called from loraTask (Core 0) every iteration when NOT in standby
    void tick();

    // Called from loraTask (Core 0) every iteration when in STATE_STANDBY
    void tickStandby();

    // Register a handler for a command ID (call from setup() before task start)
    void registerCommand(MaintenanceCommand cmd, CommandHandler handler);

    // Push telemetry snapshot from loop() / Core 1 (thread-safe via mutex)
    void updateTelemetry(const MaintenanceTelemetry& telemetry);

    // Register a custom TLV field provider (call from setup())
    void registerTLVField(uint8_t tag, std::function<void(std::vector<uint8_t>&)> provider);

    bool isEnabled() const;
};
```

### `tick()` flow (Core 0, STATE_RUNNING)

```
tick()
  ├── [STATE_STANDBY] → return immediately (tickStandby() owns that state)
  ├── [deferredStop enabled && active window expired]
  │       → currentState = STATE_STANDBY, return
  ├── [maintenance.enabled == false] → return
  ├── [interval not elapsed] → return
  └── [interval elapsed]
        ├─1► currentState = STATE_MAINTENANCE_TX
        │     sendMaintenanceFrame()
        ├─2► currentState = STATE_MAINTENANCE_RX
        │     LoRa.receive()
        │     loop listenDurationMs: parsePacket() → dispatchCommand()
        │     LoRa.idle()
        └─3► currentState = STATE_RUNNING
```

### `tickStandby()` flow (Core 0, STATE_STANDBY)

```
tickStandby()
  ├── [first call after entering standby]
  │       LoRa.receive()  ← enable continuous RX
  ├── [maintenance.enabled && interval elapsed]
  │       LoRa.idle()
  │       currentState = STATE_MAINTENANCE_TX
  │       sendMaintenanceFrame()
  │       currentState = STATE_STANDBY  ← back to standby, RX re-enabled next call
  └── parsePacket() (non-blocking)
        └── if FRAME_COMMAND → dispatchCommand()
              └── CMD_START handler sets currentState = STATE_RUNNING
                    → tickStandby() cleans up RX mode
```

---

## 5. Configuration Structure

```cpp
struct MaintenanceConfig {
    bool     enabled            = false;
    uint32_t intervalMs         = 120000;    // 2 min between maintenance frames
    uint32_t listenDurationMs   = 2000;      // 2 s RX window after each frame
    bool     batteryEnabled     = false;     // ADC battery voltage reading
    uint8_t  batteryPin         = 35;        // ADC1_CH7 on T-Beam v1.1
    float    batteryScaleFactor = 2.0f;      // Voltage divider ratio
    std::vector<uint8_t> enabledCommands;    // Whitelisted CMD_* IDs
    bool     deferredStopEnabled = false;    // Enter standby after active window
    uint32_t activeWindowMs      = 300000;   // Active TX window (default 5 min)
};
```

Serialized under the `maintenance` key in `config.json` (LittleFS).

> **Note:** All JSON documents in `config_manager.cpp` and `web_interface_manager.cpp` use `DynamicJsonDocument(3072)` (heap allocation) to avoid stack overflow on ESP32.

---

## 6. `main.cpp` Integration

### Registered command handlers (setup)

| Command | Action |
| --- | --- |
| `CMD_RESET` | `ESP.restart()` after 500 ms |
| `CMD_PING` | Serial log only |
| `CMD_SLEEP` | `esp_deep_sleep_start()` for N seconds |
| `CMD_LOGLEVEL` | Serial log only (extend as needed) |
| `CMD_START` | `currentState = STATE_RUNNING`; **permanently cancels** deferred-stop timer (`cancelDeferredStop()`) — active window disabled for session |
| `CMD_STOP` | `currentState = STATE_STANDBY` |

### `loraTask` (Core 0)

```cpp
while (true) {
    maintenanceManager->tick();        // handles deferred stop + periodic frame

    if (currentState == STATE_STANDBY) {
        maintenanceManager->tickStandby(); // continuous RX + command dispatch
        vTaskDelay(pdMS_TO_TICKS(1));
        continue;                          // skip RTCM buffer processing
    }
    // ... normal RTCM TX ...
}
```

### `loop()` (Core 1)

- When `STATE_STANDBY`: updates OLED only, `delay(100)`, early return — no WiFi/NTRIP check, no `keepAlive()`.
- `keepAlive()` (GGA to NTRIP) is guarded: only runs when `currentState == STATE_RUNNING`.
- Telemetry pushed to `MaintenanceManager` every `DISPLAY_UPDATE_INTERVAL` ms.

---

## 7. WebUI Changes

### New component: `webui/src/app/components/config/MaintenanceConfig.tsx`

```
Maintenance Frame
├── [toggle]   Enable maintenance frames
├── [select]   Interval:        1 / 2 / 3 / 5 / 10 min
├── [select]   Listen duration: 1 / 2 / 3 / 5 / 10 s
├── [toggle]   Deferred stop
│   └── [select]   Active TX window: 1 / 2 / 5 / 10 / 15 / 30 min
├── [toggle]   Battery monitoring
│   ├── [input]    ADC Pin
│   └── [input]    Scale factor
└── [checkboxes] Allowed commands:
    ☑ RESET    ☑ PING
    ☐ SLEEP    ☐ HTTP GET    ☐ SET PARAM    ☐ LOG LEVEL
    ☐ START    ☐ STOP
```

Tab is accessible via the wrench icon (🔧) in the tab bar (6th column).

---

## 8. Files Changed

| File | Change |
| --- | --- |
| `include/maintenance_manager.h` | **NEW** |
| `src/maintenance_manager.cpp` | **NEW** |
| `include/system_state.h` | Added `STATE_MAINTENANCE_TX`, `STATE_MAINTENANCE_RX`, `STATE_STANDBY` |
| `include/config_manager.h` | Added `MaintenanceConfig` struct + field in `SystemConfig` |
| `src/config_manager.cpp` | Defaults/load/save for maintenance config; `DynamicJsonDocument(3072)` |
| `include/lora_transmitter.h` | `LoRaFrameType` enum; `frameType` in `PacketHeader`; `HEADER_SIZE` 4→5 |
| `src/lora_transmitter.cpp` | Updated packet byte layout |
| `src/display_manager.cpp` | `MAINT TX` / `MAINT RX` / `STANDBY` state strings |
| `src/main.cpp` | `MaintenanceManager` instance; handler registration; `tick()`/`tickStandby()` in `loraTask`; telemetry push; standby guard in `loop()`; GGA guard |
| `src/web_interface_manager.cpp` | Maintenance block in GET/POST config; `DynamicJsonDocument(3072)` |
| `webui/src/app/types/config.ts` | `maintenance` field in `Config` interface |
| `webui/src/app/hooks/useConfig.ts` | Default values for maintenance config |
| `webui/src/app/components/config/MaintenanceConfig.tsx` | **NEW** |
| `webui/src/app/App.tsx` | Maintenance tab (6-column grid, wrench icon) |
| `webui/src/app/data/help-content.ts` | Help text for maintenance tab |

---

## 9. Risks and Mitigations

| Risk | Mitigation |
| --- | --- |
| **Breaking protocol change** | `frameType` byte added; receivers not updated will reject packets (fire-and-forget, no ACK) |
| **RX window pauses RTCM for 2 s**  | Acceptable — rover buffers corrections; 2 s gap does not break RTK fix |
| **Thread safety on telemetry** | `SemaphoreHandle_t` in `MaintenanceManager` guards Core 1 write vs Core 0 read |
| **Unauthenticated commands** | `enabledCommands` whitelist; security-sensitive commands (SLEEP, HTTP GET) off by default |
| **Stack overflow from large JSON** | All JSON docs use `DynamicJsonDocument` (heap); `StaticJsonDocument<4096>` removed |
| **GGA sent during standby** | `keepAlive()` guarded by `currentState == STATE_RUNNING` |

---

## 1. Protocol Changes

### Current packet header (4 bytes):

```
[msgID 1B][totalPkts 1B][pktNum 1B][dataLen 1B][data 0–246B]
```

### New packet header (5 bytes — Protocol v2):

```
[frameType 1B][msgID 1B][totalPkts 1B][pktNum 1B][dataLen 1B][data 0–245B]
```

| `frameType` | Symbol | Description |
| --- | --- | --- |
| `0x01` | `FRAME_RTCM` | RTCM correction data (existing traffic) |
| `0x02` | `FRAME_MAINTENANCE` | Telemetry broadcast (TX → air) |
| `0x03` | `FRAME_COMMAND` | Control command (RX → transmitter) |
| `0x04` | `FRAME_ACK` | Optional acknowledgement |

> **Backward compatibility:** Use the `PROTOCOL_V2` build flag in `platformio.ini` to enable the new header. Old receivers can be updated independently.

---

## 2. Payload Formats

### 2a. Maintenance Frame Payload (18 bytes fixed + TLV extension)

```
+----------+----------+-------+------+----------+----------+-------+-----------+
| uptime   | batt_mv  | rssi  | snr  | rtcm_rx  | rtcm_tx  | flags | reserved  |
| uint32   | uint16   | int8  | int8 | uint32   | uint32   | uint8 | uint8[1]  |
+----------+----------+-------+------+----------+----------+-------+-----------+
  4B         2B         1B      1B     4B          4B         1B      1B   = 18B
```

**`flags` bitmask:**

- bit 0 — `ntrip_connected`
- bit 1 — `wifi_connected`
- bit 2 — `battery_valid`
- bits 3–7 — reserved

**TLV extension block** (variable length, follows fixed part):

```
[tag 1B][len 1B][value lenB] ...
```

| Tag | Content |
| --- | --- |
| `0x01` | Custom label string (max 32 chars) |
| `0x02` | Free heap (uint32) |
| `0x03` | Chip temperature (int8, °C) |
| `0x04` | RTCM frames overwritten count (uint32) |

### 2b. Command Frame Payload

```
[commandId 1B][payloadLen 1B][payload 0–243B]
```

| ID | Symbol | Payload |
| --- | --- | --- |
| `0x01` | `CMD_RESET` | none |
| `0x02` | `CMD_SLEEP` | `uint32` duration in seconds |
| `0x03` | `CMD_HTTP_GET`  | null-terminated URL string |
| `0x04` | `CMD_SET_PARAM` | `key\0value\0` |
| `0x05` | `CMD_PING` | none (response: ACK frame) |
| `0x06` | `CMD_LOGLEVEL`  | `uint8` level (0=off, 1=error, 2=debug) |

---

## 3. New Component: `MaintenanceManager`

### Files to create:

- `include/maintenance_manager.h`
- `src/maintenance_manager.cpp`

### Key responsibilities:

- Track elapsed time and trigger the maintenance cycle when due.
- Build and transmit the maintenance frame payload via `LoRaTransmitter`.
- Switch LoRa module to RX mode for the listen window.
- Parse incoming command frames and dispatch to registered handlers.
- Thread-safe telemetry update (Core 1 writes, Core 0 reads via mutex).

### Public API:

```cpp
class MaintenanceManager {
public:
    explicit MaintenanceManager(ConfigManager& configMgr);

    // Called from loraTask (Core 0) — checks timing and executes if due
    void tick();

    // Register a handler for a specific command ID — extensible pattern
    void registerCommand(MaintenanceCommand cmd, CommandHandler handler);

    // Called by main.cpp (Core 1) to push fresh telemetry (thread-safe)
    void updateTelemetry(const MaintenanceTelemetry& telemetry);

    // Register a custom TLV field provider — extensible pattern
    void registerTLVField(uint8_t tag, std::function<void(std::vector<uint8_t>&)> provider);

    bool isEnabled() const;
};
```

### Types:

```cpp
enum class MaintenanceCommand : uint8_t {
    CMD_RESET     = 0x01,
    CMD_SLEEP     = 0x02,
    CMD_HTTP_GET  = 0x03,
    CMD_SET_PARAM = 0x04,
    CMD_PING      = 0x05,
    CMD_LOGLEVEL  = 0x06,
};

struct MaintenanceTelemetry {
    uint32_t uptime_s;
    uint16_t battery_mv;
    uint32_t rtcm_rx_total;
    uint32_t rtcm_tx_total;
    bool     ntrip_connected;
    bool     wifi_connected;
    int8_t   last_rssi;
    int8_t   last_snr;
    uint32_t free_heap;
};

using CommandHandler = std::function<void(const uint8_t* payload, uint8_t len)>;
```

### Internal flow of `tick()`:

```
tick() called from loraTask (Core 0)
  │
  ├── [interval not elapsed] → return immediately
  │
  └── [interval elapsed]
        ├─1─► currentState = STATE_MAINTENANCE_TX
        │     build payload (fixed header + TLV providers)
        │     transmit FRAME_MAINTENANCE via LoRa
        │
        ├─2─► currentState = STATE_MAINTENANCE_RX
        │     LoRa.receive()
        │     loop for listenDurationMs:
        │       parsePacket()
        │       if frameType == FRAME_COMMAND → dispatchCommand()
        │     LoRa.idle()
        │
        └─3─► currentState = STATE_RUNNING
```

---

## 4. Configuration Structure Extension

Add to `config_manager.h` inside `SystemConfig`:

```cpp
struct MaintenanceConfig {
    bool     enabled            = false;
    uint32_t intervalMs         = 120000;   // 2 minutes
    uint32_t listenDurationMs   = 2000;     // 2 seconds
    bool     batteryEnabled     = false;
    uint8_t  batteryPin         = 35;       // ADC1_CH7 on T-Beam v1.1
    float    batteryScaleFactor = 2.0f;     // voltage divider ratio
    std::vector<uint8_t> enabledCommands;   // whitelisted CMD_* IDs
};

// Add to SystemConfig:
MaintenanceConfig maintenance;
```

Update `config_manager.cpp` to serialize/deserialize this block under the `maintenance` JSON key.

---

## 5. Changes to `lora_transmitter.h` / `.cpp`

1. **Add `frameType` field to `PacketHeader`:**

```cpp
struct PacketHeader {
    uint8_t frameType;     // NEW: 0x01=RTCM, 0x02=MAINT, 0x03=CMD
    uint8_t messageId;
    uint8_t totalPackets;
    uint8_t packetNumber;
    uint8_t dataLength;
};
```

`HEADER_SIZE` changes from 4 → 5; `MAX_DATA_PER_PACKET` changes from 246 → 245.

2. **New public method** for raw frame transmission used by `MaintenanceManager`:

```cpp
bool transmitRawFrame(uint8_t frameType, const uint8_t* data, size_t length);
```

---

## 6. Changes to `system_state.h`

```cpp
enum SystemState {
    STATE_INIT,
    STATE_RUNNING,
    STATE_MAINTENANCE_TX,   // Transmitting maintenance frame
    STATE_MAINTENANCE_RX,   // Listening for command (RX mode)
    STATE_ERROR
};
```

Used by `DisplayManager` to show "MAINT TX" / "MAINT RX" on the OLED.

---

## 7. Changes to `main.cpp`

### New global object:

```cpp
MaintenanceManager* maintenanceManager = nullptr;
```

### In `setup()` — instantiate and register command handlers:

```cpp
maintenanceManager = new MaintenanceManager(configManager);

maintenanceManager->registerCommand(MaintenanceCommand::CMD_RESET,
    [](const uint8_t*, uint8_t) {
        Serial.println(F("[MAINT] Remote reset"));
        delay(500);
        ESP.restart();
    });

maintenanceManager->registerCommand(MaintenanceCommand::CMD_PING,
    [](const uint8_t*, uint8_t) {
        Serial.println(F("[MAINT] Ping received"));
    });

maintenanceManager->registerCommand(MaintenanceCommand::CMD_SLEEP,
    [](const uint8_t* p, uint8_t len) {
        if (len >= 4) {
            uint32_t secs;
            memcpy(&secs, p, 4);
            esp_sleep_enable_timer_wakeup((uint64_t)secs * 1000000ULL);
            esp_deep_sleep_start();
        }
    });
```

### In `loraTask()` (Core 0) — add tick at the top of the loop:

```cpp
while (true) {
    maintenanceManager->tick();   // NEW
    // ... existing RTCM buffer handling ...
}
```

### In `loop()` (Core 1) — push telemetry snapshot every second:

```cpp
MaintenanceTelemetry tel;
tel.uptime_s        = millis() / 1000;
tel.rtcm_rx_total   = totalRTCMFramesReceived;
tel.rtcm_tx_total   = totalRTCMFramesTransmitted;
tel.ntrip_connected = ntripClient->isConnected();
tel.wifi_connected  = wifiManager->isConnected();
tel.free_heap       = esp_get_free_heap_size();
maintenanceManager->updateTelemetry(tel);
```

---

## 8. WebUI Changes

### New component: `webui/src/app/components/config/MaintenanceConfig.tsx`

Configuration UI layout:

```
Maintenance Frame
├── [toggle]   Enable maintenance frames
├── [select]   Interval:        1 min / 2 min / 3 min / 5 min / 10 min
├── [select]   Listen duration: 1s / 2s / 3s / 5s / 10s
├── [toggle]   Battery monitoring
│   ├── [input]  ADC Pin (shown when enabled)
│   └── [input]  Scale factor
└── [checkboxes] Enabled commands:
    ☑ RESET    ☑ SLEEP    ☑ PING
    ☐ HTTP GET  ☐ SET PARAM  ☐ LOG LEVEL
```

### Also modify:

- `webui/src/app/App.tsx` — add Maintenance tab
- `webui/src/types/config.ts` — add `MaintenanceConfig` interface
- `webui/src/hooks/useConfig.ts` — extend config load/save

Config data is sent to `POST /api/config` as a `maintenance` JSON block, handled by the existing `handleSaveConfig`.

---

## 9. Files Affected

| File | Change type |
| --- | --- |
| `include/maintenance_manager.h` | **NEW** |
| `src/maintenance_manager.cpp` | **NEW** |
| `include/system_state.h` | Add 2 states |
| `include/config_manager.h` | Add `MaintenanceConfig` to `SystemConfig` |
| `src/config_manager.cpp` | Serialize/deserialize new config block |
| `include/lora_transmitter.h` | Add `frameType` to header, add `transmitRawFrame()` |
| `src/lora_transmitter.cpp` | Implement extended header |
| `src/main.cpp` | Instantiate MM, register handlers, call in `loraTask`, push telemetry |
| `lora-protocol.md` (shared) | Document new packet format |
| `webui/src/app/components/config/MaintenanceConfig.tsx` | **NEW** |
| `webui/src/app/App.tsx` | Add Maintenance tab |
| `webui/src/types/config.ts` | Extend config types |
| `webui/src/hooks/useConfig.ts` | Extend config load/save |

---

## 10. Risks and Mitigations

| Risk | Mitigation |
| --- | --- |
| **Breaking protocol change** | Use `PROTOCOL_V2` build flag; old receivers can be updated independently |
| **2s RX window pauses RTCM TX** | Acceptable — rover buffers corrections; 2s without new MSM does not break RTK fix |
| **Thread safety on telemetry struct** | `SemaphoreHandle_t` in `MaintenanceManager` guards the struct between Core 1 write and Core 0 read |
| **Unauthenticated commands** | `enabledCommands` whitelist in config; optionally add a 4-byte shared secret field to the CMD frame header |
| **Memory footprint** | `std::map` + `std::function` cost ~500–800 B heap — acceptable within 520 KB RAM |

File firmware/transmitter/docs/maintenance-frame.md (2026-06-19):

# Maintenance Frame — Implementation

> 📦 **Moved.** The maintenance/command channel travels over the shared LoRa link, so the
> specification now lives in one canonical place alongside the LoRa protocol:
>
> **→ [`../../shared/docs/maintenance-frame.md`](../../shared/docs/maintenance-frame.md)**
>
> Please update that file when changing the maintenance frame, command set, or telemetry
> layout, and keep both firmwares byte-compatible with it. See also the base packet format
> in [`../../shared/docs/lora-protocol.md`](../../shared/docs/lora-protocol.md).

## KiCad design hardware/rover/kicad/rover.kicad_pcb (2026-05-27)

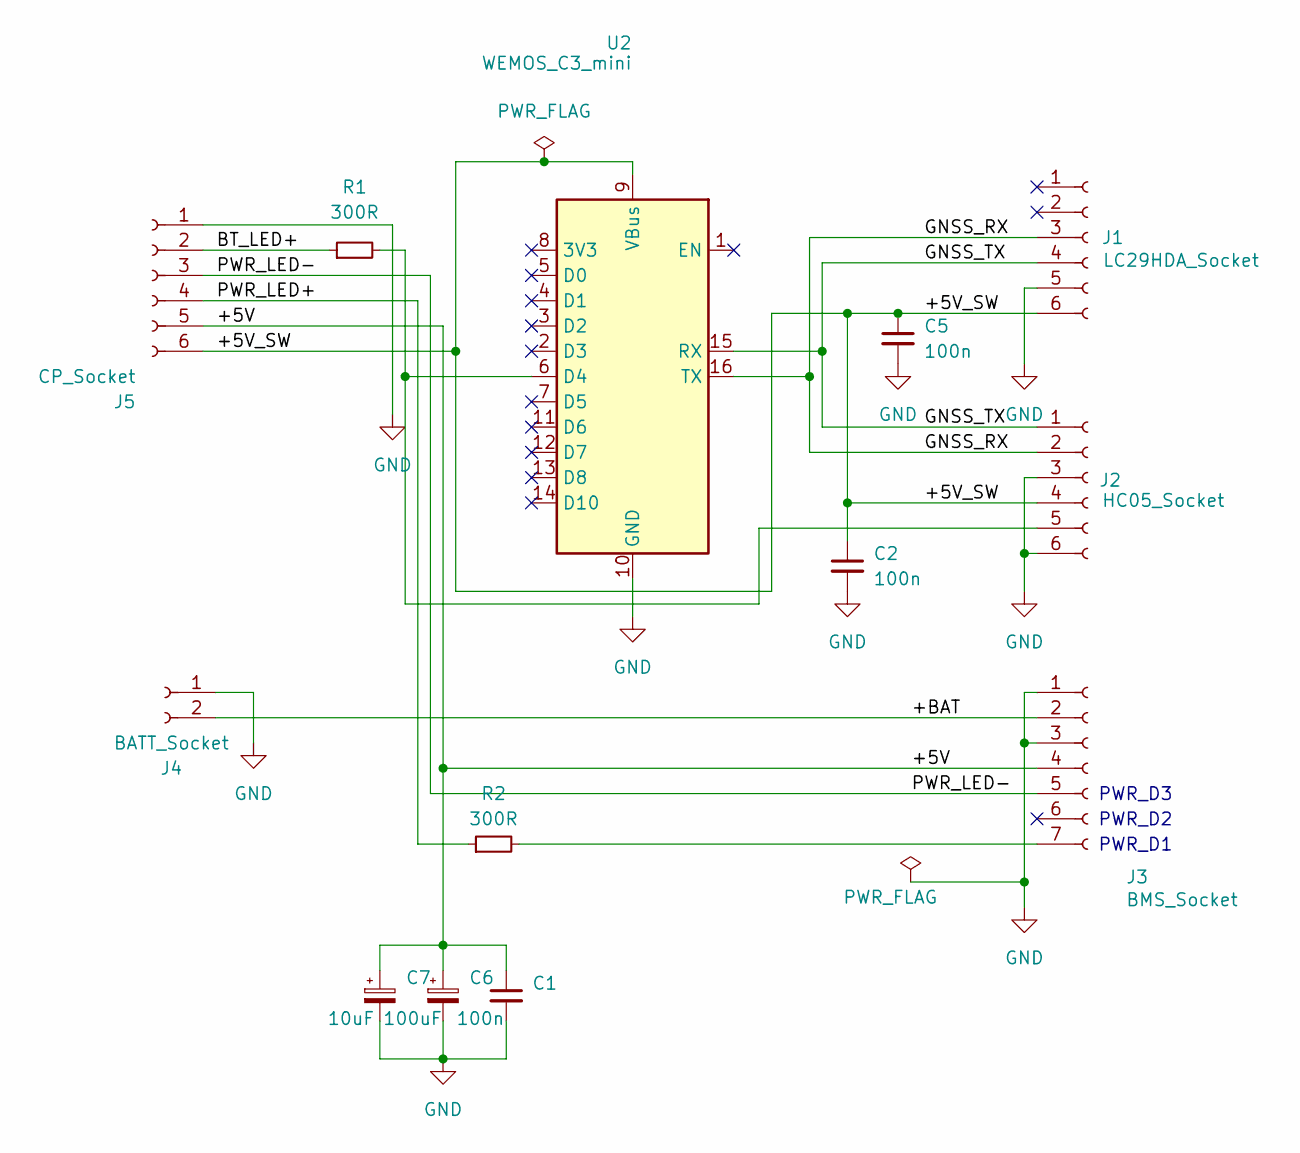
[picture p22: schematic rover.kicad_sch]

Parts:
C1, C2, C5: 100n; C_Disc_D3.0mm_W1.6mm_P2.50mm
C6: 100uF; CP_Radial_D5.0mm_P2.50mm
C7: 10uF; CP_Radial_D4.0mm_P2.00mm
J1: LC29HDA_Socket; LC29H
J2: HC05_Socket; HC05
J3: BMS_Socket; BMS_FM5324
J4: BATT_Socket; PinHeader_1x02_P2.54mm_Horizontal
J5: CP_Socket; RTK_ControlPanel
R1, R2: 300R; R_Axial_DIN0204_L3.6mm_D1.6mm_P7.62mm_Horizontal
U2: WEMOS_C3_mini

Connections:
/+5V: C1.1, C6.1, C7.1, J3.4, J5.5
/+5V_SW: C2.1, C5.1, J1.6, J2.4, J5.6, U2.9 (VBus)
/+BAT: J3.2, J4.2
/BT_LED+: J5.2, R1.1
/GNSS_RX: J1.3, J2.2, U2.16 (TX)
/GNSS_TX: J1.4, J2.1, U2.15 (RX)
/PWR_LED+: J5.4, R2.1
/PWR_LED-: J3.5, J5.3
GND: C1.2, C2.2, C5.2, C6.2, C7.2, J1.5, J2.3, J2.6, J3.1, J3.3, J4.1, J5.1, U2.10 (GND)
unnamed: J2.5, R1.2, U2.6 (D4)
unnamed: J3.7, R2.2

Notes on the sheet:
PWR_D3
PWR_D1
PWR_D2

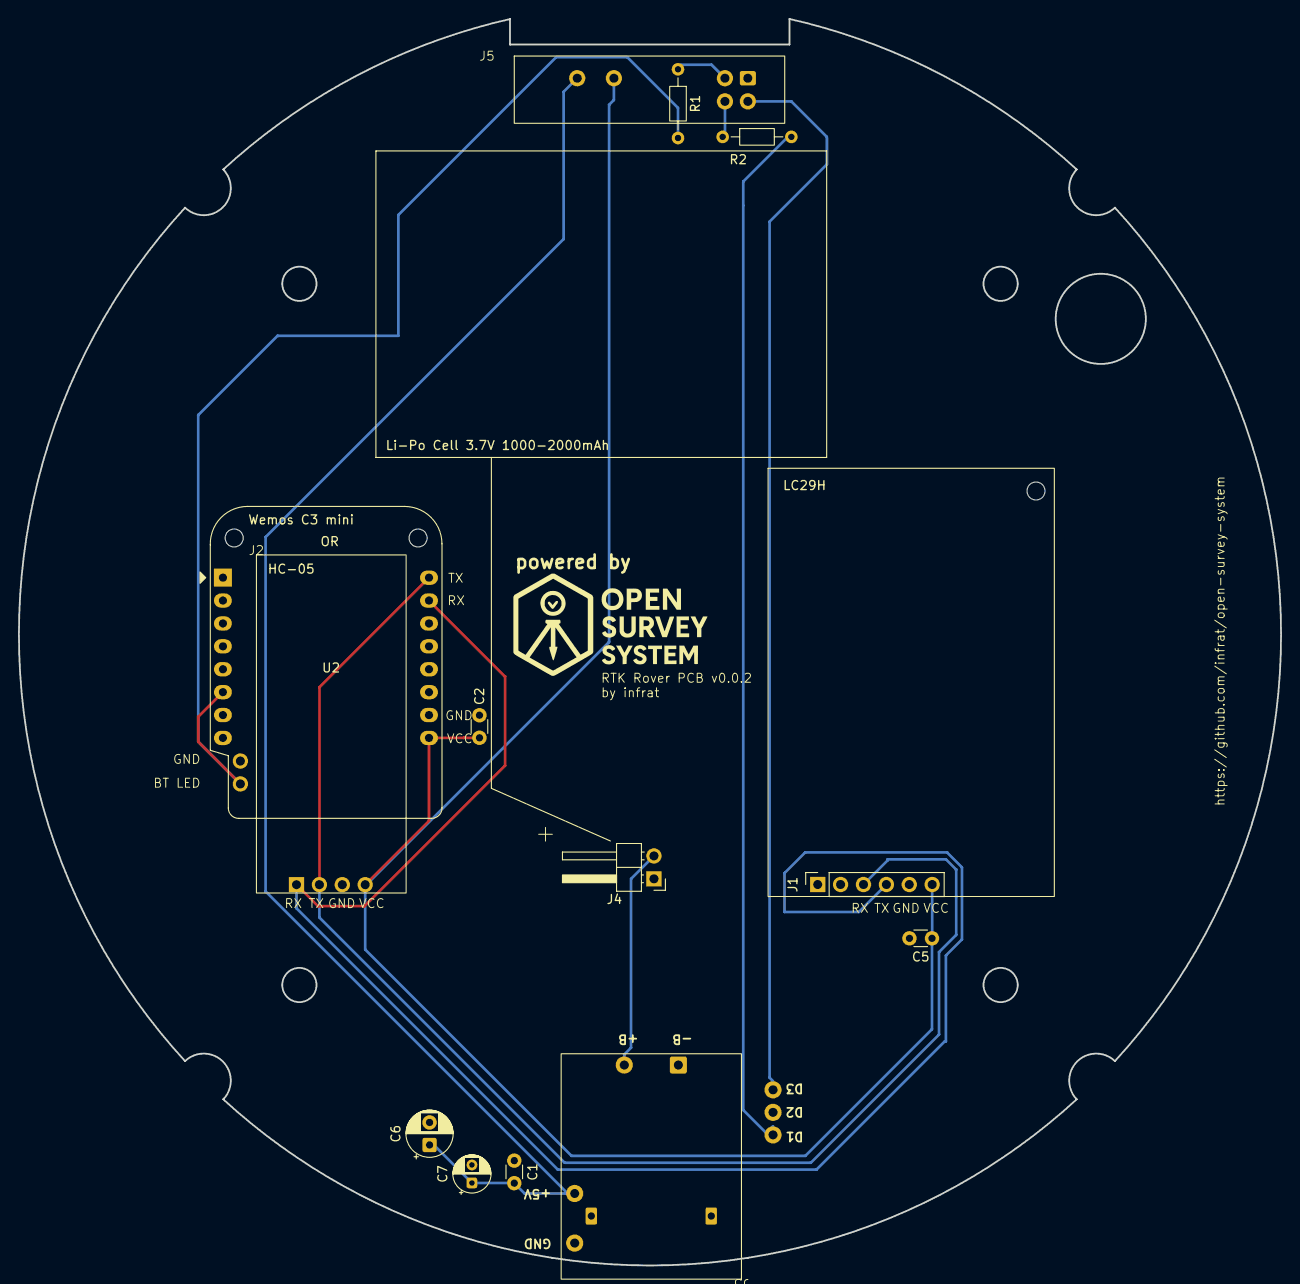
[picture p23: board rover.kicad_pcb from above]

Board: 2 copper layers, 140.0 x 138.3 mm, 13 parts (0 on the bottom side), 11 nets.

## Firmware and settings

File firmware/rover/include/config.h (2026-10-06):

#ifndef CONFIG_H
#define CONFIG_H

#define FIRMWARE_VERSION "2.0.0"

// ===== UART Configuration (GPS) =====
#define GPS_UART_NUM UART_NUM_1 // UART1 for GPS
#define GPS_RX_PIN 25           // GPIO25 - receive data from GPS (TX GPS → RX ESP32)
#define GPS_TX_PIN 27           // GPIO27 - send data to GPS (RX GPS ← TX ESP32)
#define GPS_BAUD_RATE 115200    // Standard baud rate for GPS modules
#define UART_BUF_SIZE 1024      // UART buffer size (1KB)

// ===== Debug UART Configuration =====
#define DEBUG_UART_NUM UART_NUM_0 // UART0 for debug/logging (Serial - USB)
#define DEBUG_BAUD_RATE 115200    // Baud rate for debug

// ===== Runtime settings: factory defaults =====
// Live values are stored in NVS and edited through the web UI. These are only
// used on first boot, after a reset, or when stored values fail validation.
#define DEFAULT_TRANSPORT_MODE 0  // 0 = BLE, 1 = Bluetooth SPP, 2 = WiFi TCP
#define DEFAULT_WIFI_MODE 2       // 0 = AP, 1 = STA, 2 = AP+STA
#define DEFAULT_SETUP_WINDOW_SEC 30 // WiFi-only setup window after boot, before Bluetooth starts
#define SETUP_WINDOW_MIN_SEC 15
#define SETUP_WINDOW_MAX_SEC 600

// ===== WiFi Configuration =====
#define WIFI_SSID "YourNetwork"               // default STA network name
#define WIFI_PASSWORD "YourPassword" // default STA password
#define AP_SSID_PREFIX "OSSRTK-"             // AP name = prefix + last MAC bytes
#define OTA_HOSTNAME "ossrtk"                // Hostname for OTA / mDNS
#define OTA_PASSWORD "admin"                 // OTA update password
#define WIFI_TIMEOUT_MS 10000                // STA connect timeout before AP fallback / service start

// ===== Network services =====
#define HTTP_PORT 80
#define TELNET_PORT 23
#define TCP_PORT_DEFAULT 10110 // de-facto standard NMEA-0183 over TCP port
#define TCP_MAX_CLIENTS 2

// ===== NTP Configuration =====
#define NTP_SERVER "pool.ntp.org" // NTP server
#define GMT_OFFSET_SEC 3600       // GMT+1 offset (1 hour)
#define DAYLIGHT_OFFSET_SEC 3600  // Daylight saving time offset (1 hour)

// ===== Power Saving Configuration =====
#define BLE_TX_POWER ESP_PWR_LVL_N9 // BLE TX power: -9dBm (low power mode)
#define SPP_TX_POWER ESP_PWR_LVL_N9 // BR/EDR TX power: -9dBm (low power mode)
#define CPU_FREQ_ACTIVE 240         // CPU frequency when transferring data (MHz)

// ===== Bluetooth Device Name (BLE and SPP) =====
#define BT_DEVICE_NAME "OSSRTK" // Name visible in BLE scanners / BT pairing list

// ===== BLE Configuration =====
#define BLE_MTU_SIZE 185   // Maximum MTU (BLE supports up to ~185)
#define BLE_CHUNK_SIZE 180 // Data chunk size to send (smaller than MTU)

// Nordic UART Service UUIDs (standard for BLE compatibility)
#define SERVICE_UUID "6E400001-B5A3-F393-E0A9-E50E24DCCA9E"
#define CHARACTERISTIC_UUID_RX "6E400002-B5A3-F393-E0A9-E50E24DCCA9E" // BLE → ESP32
#define CHARACTERISTIC_UUID_TX "6E400003-B5A3-F393-E0A9-E50E24DCCA9E" // ESP32 → BLE

// ===== Other Settings =====
#define LINK_STATUS_LED_PIN 23 // Transport status LED on GPIO23 (active HIGH)
#define LINK_LED_BLINK_MS 250  // LED blink period when not connected (250ms ON/OFF)
#define NMEA_MAX_LENGTH 82     // Maximum NMEA sentence length
#define BRIDGE_LOG_TRAFFIC 1   // Log every UART↔transport chunk (0 = quiet)

#endif // CONFIG_H

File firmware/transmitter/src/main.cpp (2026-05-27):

#include <Arduino.h>
#include <WiFi.h>
#include <LoRa.h>
#include <map>
#include "freertos/FreeRTOS.h"
#include "freertos/semphr.h"
#include "freertos/task.h"
#include "config.h"
#include "config_manager.h"
#include "wifi_manager.h"
#include "ntrip_client.h"
#include "rtcm_parser.h"
#include "lora_transmitter.h"
#include "display_manager.h"
#include "web_interface_manager.h"
#include "system_state.h"
#include "maintenance_manager.h"

// ==================== RTCM Per-Type Buffer (Core 1 → Core 0) ====================

struct RTCMBufferItem
{
    static const size_t MAX_SIZE = 1029; // Max RTCM3 message (1023 data + 3 header + 3 CRC)
    uint8_t data[MAX_SIZE];
    size_t length;
    uint16_t messageType;
    unsigned long timestamp; // millis() when received
};

// Per-type buffer: always keeps the latest message of each type
// Protected by mutex for cross-core access
std::map<uint16_t, RTCMBufferItem> rtcmBuffer;
SemaphoreHandle_t rtcmBufferMutex = nullptr;
TaskHandle_t loraTaskHandle = nullptr;

// Overwrite counter (for stats)
volatile uint32_t totalRTCMOverwritten = 0;

// ==================== GLOBAL OBJECTS ====================

ConfigManager configManager;
WiFiManager *wifiManager = nullptr;
NTRIPClient *ntripClient = nullptr;
RTCMParser *rtcmParser = nullptr;
LoRaTransmitter *loraTransmitter = nullptr;
DisplayManager displayManager;
WebInterfaceManager *webInterface = nullptr;
MaintenanceManager *maintenanceManager = nullptr;

// ==================== STATE ====================

volatile SystemState currentState = STATE_INIT;

// ==================== STATISTICS ====================

// RX counters (written only by Core 1)
unsigned long totalRTCMFramesReceived = 0;
uint32_t rtcmRxLastSecond = 0;
uint32_t rtcmRxCurrentSecond = 0;

// TX counters (written only by Core 0, read by Core 1 for display)
volatile unsigned long totalRTCMFramesTransmitted = 0;
volatile unsigned long totalBytesTransmitted = 0;
volatile uint32_t rtcmTxLastSecond = 0;
volatile uint32_t rtcmTxCurrentSecond = 0;

// Display update tracking
unsigned long lastDisplayUpdate = 0;
#define DISPLAY_UPDATE_INTERVAL 500
unsigned long lastSecondTimestamp = 0;
unsigned long lastStatsUpdate = 0;

// ==================== HARDWARE PINS ====================

#define LED_PIN 4 // T-Beam v1.1 uses GPIO 4 for the blue LED

// ==================== Priority Lookup ====================

// Fast lookup table for priority types (populated from config at startup)
bool isPriorityType[4096] = {false};

void initPriorityLookup()
{
    memset(isPriorityType, false, sizeof(isPriorityType));
    SystemConfig &cfg = configManager.getConfig();
    for (uint16_t type : cfg.rtcmPriorityMessageTypes)
    {
        if (type < 4096)
            isPriorityType[type] = true;
    }

    // 1005 (station position) is always priority — critical for RTK solution
    isPriorityType[1005] = true;
}

// ==================== LoRa TX Task (Core 0) ====================
// Snapshot approach: take entire buffer atomically, transmit priority first,
// then low-priority only if no fresh priority data has arrived.
// Every LOW_PRIORITY_INTERVAL_MS, force low-priority through.

#define LOW_PRIORITY_INTERVAL_MS 5000

void loraTask(void *parameter)
{
    std::map<uint16_t, RTCMBufferItem> batch;
    unsigned long lastLowPriorityTime = millis();

#ifdef DEBUG
    Serial.println(F("[LoRa Task] Started on Core 0 (snapshot mode)"));
#endif

    while (true)
    {
        // Maintenance frame cycle (Core 0 — safe to call LoRa.*)
        maintenanceManager->tick();

        // Standby mode: RTCM TX halted, LoRa in continuous RX
        if (currentState == STATE_STANDBY)
        {
            maintenanceManager->tickStandby();
            vTaskDelay(pdMS_TO_TICKS(1));
            continue;
        }

        if (currentState == STATE_ERROR)
        {
            vTaskDelay(pdMS_TO_TICKS(100));
            continue;
        }

        // Atomic snapshot: swap entire buffer
        bool gotData = false;
        if (xSemaphoreTake(rtcmBufferMutex, pdMS_TO_TICKS(50)) == pdTRUE)
        {
            if (!rtcmBuffer.empty())
            {
                std::swap(batch, rtcmBuffer);
                gotData = true;
            }
            xSemaphoreGive(rtcmBufferMutex);
        }

        if (!gotData)
        {
            vTaskDelay(pdMS_TO_TICKS(10));
            continue;
        }

        // Pass 1: Transmit ALL priority items (MSM + 1005 + 1230)
        // std::map iterates by key ascending: 1005 goes first (small, fast)
        for (auto it = batch.begin(); it != batch.end(); ++it)
        {
            if (!isPriorityType[it->first])
                continue;

            bool success = loraTransmitter->transmitMessage(it->second.data, it->second.length);
            if (success)
            {
                totalRTCMFramesTransmitted++;
                totalBytesTransmitted += it->second.length;
                rtcmTxCurrentSecond++;
#ifdef DEBUG
                Serial.printf("✓ RTCM %d (%d bytes) [PRI]\n", it->first, it->second.length);
#endif
            }
        }

        // Pass 2: Transmit low-priority items (ephemeris, antenna descriptors)
        // Skip if new priority data has arrived AND we've sent low-priority recently
        bool forceLow = (millis() - lastLowPriorityTime >= LOW_PRIORITY_INTERVAL_MS);
        bool skipLow = false;

        if (!forceLow)
        {
            if (xSemaphoreTake(rtcmBufferMutex, pdMS_TO_TICKS(10)) == pdTRUE)
            {
                for (auto it = rtcmBuffer.begin(); it != rtcmBuffer.end(); ++it)
                {
                    if (isPriorityType[it->first])
                    {
                        skipLow = true;
                        break;
                    }
                }
                xSemaphoreGive(rtcmBufferMutex);
            }
        }

        if (!skipLow)
        {
            for (auto it = batch.begin(); it != batch.end(); ++it)
            {
                if (isPriorityType[it->first])
                    continue; // already sent in pass 1

                bool success = loraTransmitter->transmitMessage(it->second.data, it->second.length);
                if (success)
                {
                    totalRTCMFramesTransmitted++;
                    totalBytesTransmitted += it->second.length;
                    rtcmTxCurrentSecond++;
#ifdef DEBUG
                    Serial.printf("✓ RTCM %d (%d bytes) [LOW]\n", it->first, it->second.length);
#endif
                }
            }
            lastLowPriorityTime = millis();
        }
#ifdef DEBUG
        else
        {
            Serial.println(F("⏭ Skipping low-priority, fresh MSM data waiting"));
        }
#endif

        batch.clear();
    }
}

// ==================== SETUP ====================

void setup()
{
    Serial.begin(115200);
#ifdef DEBUG
    Serial.println(F("\n========================================"));
    Serial.println(F("  TTGO T-Beam LoRa RTCM Transmitter"));
    Serial.println(F("  Dual-Core Architecture"));
    Serial.println(F("========================================"));
#endif

    // Initialize LED pin
    pinMode(LED_PIN, OUTPUT);
    digitalWrite(LED_PIN, HIGH);

#ifdef DEBUG
    // Disable watchdog timer for debugging
    disableCore0WDT();
    disableCore1WDT();
    Serial.println(F("Watchdog timers disabled for debugging"));
#endif

    // Initialize display
    displayManager.begin();
    displayManager.showSplashScreen();
    delay(3000);

    displayManager.showStatus("Config", "Loading...");

    // Initialize ConfigManager
    if (!configManager.begin())
    {
#ifdef DEBUG
        Serial.println(F("ConfigManager initialization failed!"));
#endif
        displayManager.showError("Config Failed");
        delay(5000);
        // Continue with defaults
    }

    // Create manager objects with ConfigManager
    wifiManager = new WiFiManager(configManager);
    ntripClient = new NTRIPClient(configManager);
    rtcmParser = new RTCMParser(configManager);
    loraTransmitter = new LoRaTransmitter(configManager);
    webInterface = new WebInterfaceManager(configManager, *ntripClient);
    maintenanceManager = new MaintenanceManager(configManager, &currentState);

    // Register maintenance command handlers (extensible — add more here)
    maintenanceManager->registerCommand(MaintenanceCommand::CMD_RESET,
        [](const uint8_t *, uint8_t) {
            Serial.println(F("[MAINT] Remote reset triggered"));
            delay(500);
            ESP.restart();
        });
    maintenanceManager->registerCommand(MaintenanceCommand::CMD_PING,
        [](const uint8_t *, uint8_t) {
            Serial.println(F("[MAINT] Ping received"));
        });
    maintenanceManager->registerCommand(MaintenanceCommand::CMD_SLEEP,
        [](const uint8_t *p, uint8_t len) {
            if (len >= 4) {
                uint32_t secs;
                memcpy(&secs, p, 4);
                Serial.printf("[MAINT] Deep sleep for %u s\n", secs);
                esp_sleep_enable_timer_wakeup((uint64_t)secs * 1000000ULL);
                esp_deep_sleep_start();
            }
        });
    maintenanceManager->registerCommand(MaintenanceCommand::CMD_LOGLEVEL,
        [](const uint8_t *p, uint8_t len) {
            if (len >= 1)
                Serial.printf("[MAINT] Log level set to %d\n", p[0]);
        });
    maintenanceManager->registerCommand(MaintenanceCommand::CMD_START,
        [](const uint8_t *, uint8_t) {
            Serial.println(F("[MAINT] CMD_START received — resuming RTCM transmission"));
            maintenanceManager->cancelDeferredStop(); // disable automatic TX window for this session
            currentState = STATE_RUNNING;
        });
    maintenanceManager->registerCommand(MaintenanceCommand::CMD_STOP,
        [](const uint8_t *, uint8_t) {
            Serial.println(F("[MAINT] CMD_STOP received — entering standby"));
            currentState = STATE_STANDBY; // tickStandby() will enable RX on next call
        });

    // Update RTCM message types from config
    rtcmParser->updateMessageTypes();

    // Initialize priority lookup table
    initPriorityLookup();

    displayManager.showStatus("Starting...", "Initializing system");

    // Start Web Interface (AP mode)
    webInterface->begin();

    // Initialize LoRa
    if (!loraTransmitter->begin())
    {
#ifdef DEBUG
        Serial.println(F("LoRa initialization failed!"));
#endif
        displayManager.showError("LoRa Init Failed");
        currentState = STATE_ERROR;
        while (1)
            delay(1000);
    }

    // Connect to WiFi
    displayManager.showStatus("WiFi", "Connecting...");
    if (!wifiManager->connect())
    {
#ifdef DEBUG
        Serial.println(F("WiFi connection failed!"));
#endif
        displayManager.showError("WiFi Failed");
        currentState = STATE_ERROR;
        while (1)
            delay(1000);
    }

    // Connect to NTRIP
    displayManager.showStatus("NTRIP", "Connecting...");
    if (!ntripClient->connect())
    {
#ifdef DEBUG
        Serial.println(F("NTRIP connection failed!"));
#endif
        displayManager.showError("NTRIP Failed");
        currentState = STATE_ERROR;
        while (1)
            delay(1000);
    }

#ifdef DEBUG
    Serial.println(F("NTRIP connected successfully"));
#endif

    // Create mutex for per-type RTCM buffer
    rtcmBufferMutex = xSemaphoreCreateMutex();
    if (rtcmBufferMutex == nullptr)
    {
#ifdef DEBUG
        Serial.println(F("Failed to create RTCM buffer mutex!"));
#endif
        displayManager.showError("Mutex Failed");
        currentState = STATE_ERROR;
        while (1)
            delay(1000);
    }

#ifdef DEBUG
    Serial.println(F("[INFO] RTCM per-type buffer with mutex created"));
#endif

    // Setup RTCM callback — store latest message per type for Core 0
    rtcmParser->setCallback([](const uint8_t *data, size_t length, uint16_t messageType)
                            {
        totalRTCMFramesReceived++;
        rtcmRxCurrentSecond++;

        if (!rtcmParser->shouldTransmitMessageType(messageType))
        {
            return;
        }

        if (length > RTCMBufferItem::MAX_SIZE)
        {
#ifdef DEBUG
            Serial.printf("⚠ RTCM %d too large (%d bytes)\n", messageType, length);
#endif
            return;
        }

        RTCMBufferItem item;
        memcpy(item.data, data, length);
        item.length = length;
        item.messageType = messageType;
        item.timestamp = millis();

        if (xSemaphoreTake(rtcmBufferMutex, pdMS_TO_TICKS(10)) == pdTRUE)
        {
            bool existed = rtcmBuffer.count(messageType) > 0;
            rtcmBuffer[messageType] = item;
            if (existed)
            {
                totalRTCMOverwritten++;
            }
            xSemaphoreGive(rtcmBufferMutex);
#ifdef DEBUG
            Serial.printf("⬇ RTCM %d (%d bytes) %s\n", messageType, length,
                          existed ? "updated" : "buffered");
#endif
        } });

    // Start LoRa TX task on Core 0
    xTaskCreatePinnedToCore(
        loraTask,        // Task function
        "LoRaTX",        // Task name
        8192,            // Stack size (bytes)
        nullptr,         // Parameter
        1,               // Priority
        &loraTaskHandle, // Task handle
        0                // Core 0 (PRO_CPU)
    );

#ifdef DEBUG
    Serial.println(F("\n[INFO] Dual-core system initialized:"));
    Serial.println(F("  Core 1: NTRIP RX, Parser, WiFi, Web, Display"));
    Serial.println(F("  Core 0: LoRa TX (FreeRTOS task)"));
    Serial.println(F("[INFO] Waiting for RTCM data..."));
#endif

    currentState = STATE_RUNNING;
    lastSecondTimestamp = millis();

    displayManager.showStatus("Running", "Dual-core active");
    delay(1000);
}

// ==================== MAIN LOOP (Core 1) ====================

void loop()
{
    yield(); // Feed watchdog

    // Update web interface (handles AP timeout)
    webInterface->loop();

    // In standby mode: skip WiFi/NTRIP processing, Core 1 is mostly idle
    if (currentState == STATE_STANDBY)
    {
        if (millis() - lastDisplayUpdate >= DISPLAY_UPDATE_INTERVAL)
        {
            displayManager.updateStatsDisplay(currentState, 0, 0,
                                              wifiManager->isConnected(), false);
            lastDisplayUpdate = millis();
        }
        delay(100);
        return;
    }

    // Check WiFi connection
    if (!wifiManager->isConnected())
    {
#ifdef DEBUG
        Serial.println(F("[ERROR] WiFi disconnected!"));
#endif
        displayManager.showStatus("WiFi", "Reconnecting...");
        if (!wifiManager->connect())
        {
            delay(5000);
            return;
        }
    }

    // Check NTRIP connection
    if (!ntripClient->isConnected())
    {
#ifdef DEBUG
        Serial.println(F("[ERROR] NTRIP disconnected!"));
#endif
        displayManager.showStatus("NTRIP", "Reconnecting...");
        if (!ntripClient->connect())
        {
            delay(5000);
            return;
        }
    }

    // Read NTRIP data and feed to parser (non-blocking — LoRa TX is on Core 0)
    size_t available = ntripClient->available();
    if (available > 0)
    {
        uint8_t buffer[512];
        size_t maxRead = min(available, sizeof(buffer));
        size_t bytesRead = ntripClient->read(buffer, maxRead);
        rtcmParser->processData(buffer, bytesRead);
    }

    // Update OLED display periodically
    if (millis() - lastDisplayUpdate >= DISPLAY_UPDATE_INTERVAL)
    {
        // Calculate msg/s every second
        if (millis() - lastSecondTimestamp >= 1000)
        {
            rtcmRxLastSecond = rtcmRxCurrentSecond;
            rtcmRxCurrentSecond = 0;
            rtcmTxLastSecond = rtcmTxCurrentSecond;
            rtcmTxCurrentSecond = 0;
            lastSecondTimestamp = millis();
        }

        displayManager.updateStatsDisplay(currentState, rtcmRxLastSecond, rtcmTxLastSecond,
                                          wifiManager->isConnected(), ntripClient->isConnected());
        lastDisplayUpdate = millis();

        // Push telemetry snapshot for maintenance frame (safe — Core 1 side)
        MaintenanceTelemetry tel;
        tel.uptime_s        = millis() / 1000;
        tel.rtcm_rx_total   = totalRTCMFramesReceived;
        tel.rtcm_tx_total   = totalRTCMFramesTransmitted;
        tel.ntrip_connected = ntripClient->isConnected();
        tel.wifi_connected  = wifiManager->isConnected();
        tel.free_heap       = esp_get_free_heap_size();
        // Battery: raw ADC → mV using voltage divider constant from config.h
        uint16_t rawAdc = analogRead(BATTERY_ADC_PIN);
        tel.battery_mv = static_cast<uint16_t>((rawAdc / 4095.0f) * 3300.0f * BATTERY_SCALE_FACTOR);
        maintenanceManager->updateTelemetry(tel);
    }

#ifdef DEBUG
    // Print stats every 30 seconds
    if (millis() - lastStatsUpdate >= 30000)
    {
        Serial.printf("\n=== Statistics ===\n");
        Serial.printf("State: %s\n", currentState == STATE_RUNNING ? "RUNNING" : "ERROR");
        Serial.printf("RTCM RX: %lu total, %u msg/s\n", totalRTCMFramesReceived, rtcmRxLastSecond);
        Serial.printf("RTCM TX: %lu total, %u msg/s (%lu bytes)\n",
                      totalRTCMFramesTransmitted, rtcmTxLastSecond, totalBytesTransmitted);
        size_t bufferSize = 0;
        if (xSemaphoreTake(rtcmBufferMutex, pdMS_TO_TICKS(10)) == pdTRUE)
        {
            bufferSize = rtcmBuffer.size();
            xSemaphoreGive(rtcmBufferMutex);
        }
        Serial.printf("Buffer: %d types pending, %lu overwrites\n", bufferSize, (unsigned long)totalRTCMOverwritten);
        Serial.printf("WiFi: %s, NTRIP: %s\n",
                      wifiManager->isConnected() ? "OK" : "ERR",
                      ntripClient->isConnected() ? "OK" : "ERR");
        Serial.printf("Free heap: %d bytes\n", ESP.getFreeHeap());
        Serial.printf("==================\n\n");

        lastStatsUpdate = millis();
    }
#endif

    // Keep NTRIP connection alive — only when actively transmitting RTCM
    if (currentState == STATE_RUNNING)
    {
        ntripClient->keepAlive();
    }
}

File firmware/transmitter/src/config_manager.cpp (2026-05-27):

#include "config_manager.h"
#include "config.h"

ConfigManager::ConfigManager()
{
    setDefaults();
}

bool ConfigManager::begin()
{
    if (!mountFilesystem())
    {
#ifdef DEBUG
        Serial.println("ConfigManager: Failed to mount LittleFS");
#endif
        return false;
    }

#ifdef DEBUG
    Serial.println("ConfigManager: LittleFS mounted successfully");
    Serial.printf("ConfigManager: Before loadConfig() - WiFi SSID: '%s' (len=%d)\n",
                  config.wifiSSID.c_str(), config.wifiSSID.length());
#endif

    bool result = loadConfig();

#ifdef DEBUG
    Serial.printf("ConfigManager: After loadConfig() - WiFi SSID: '%s' (len=%d)\n",
                  config.wifiSSID.c_str(), config.wifiSSID.length());
#endif

    return result;
}

bool ConfigManager::mountFilesystem()
{
    if (!LittleFS.begin(true)) // format on fail
    {
        return false;
    }
    return true;
}

void ConfigManager::setDefaults()
{
    // WiFi defaults
    config.wifiSSID = "";
    config.wifiPassword = "";
    config.wifiTimeout = 30000;

#ifdef DEBUG
    Serial.printf("ConfigManager: setDefaults() - WiFi SSID: '%s' (len=%d)\n",
                  config.wifiSSID.c_str(), config.wifiSSID.length());
#endif

    // NTRIP defaults
    config.ntripHost = "91.198.76.2";
    config.ntripPort = 2101;
    config.ntripMountpoint = "RTN4G_VRS_RTCM32";
    config.ntripUser = "";
    config.ntripPassword = "";
    config.ntripTimeout = 10000;

    // GGA defaults (Jaworzno, Poland)
    config.ggaLatitude = 50.2346;
    config.ggaLongitude = 19.2084;
    config.ggaAltitude = 266.0;
    config.ggaSendInterval = 2000;

    // LoRa defaults
    config.loraFrequency = 433000000; // 433 MHz
    config.loraSpreadingFactor = 7;
    config.loraBandwidth = 125000; // 125 kHz
    config.loraCodingRate = 5;
    config.loraTxPower = 20;
    config.loraSyncWord = 0x12;

    // RTCM message types (all types to transmit via LoRa)
    config.rtcmMessageTypes = {1005, 1007, 1019, 1020, 1033, 1075, 1085, 1095, 1125, 1230};

    // RTCM high-priority types (MSM observations + station position — critical for RTK)
    config.rtcmPriorityMessageTypes = {1005, 1075, 1085, 1095, 1125, 1230};

    // Display defaults
    config.displayUpdateInterval = 500;

    // Maintenance frame defaults
    config.maintenance.enabled = false;
    config.maintenance.intervalMs = 120000;
    config.maintenance.listenDurationMs = 2000;
    config.maintenance.rxWindowEnabled = false;
    config.maintenance.enabledCommands = {0x01, 0x05}; // RESET + PING enabled by default
    config.maintenance.deferredStopEnabled = false;
    config.maintenance.activeWindowMs = 300000; // 5 minutes
}

bool ConfigManager::loadConfig()
{
    if (!LittleFS.exists(CONFIG_FILE))
    {
#ifdef DEBUG
        Serial.println("ConfigManager: Config file not found, using defaults");
#endif
        return saveConfig(); // Create default config file
    }

    File file = LittleFS.open(CONFIG_FILE, "r");
    if (!file)
    {
#ifdef DEBUG
        Serial.println("ConfigManager: Failed to open config file");
#endif
        return false;
    }

    DynamicJsonDocument doc(3072);
    DeserializationError error = deserializeJson(doc, file);
    file.close();

    if (error)
    {
#ifdef DEBUG
        Serial.print("ConfigManager: Failed to parse config: ");
        Serial.println(error.c_str());
#endif
        return false;
    }

    // Load WiFi config (use current defaults if not in JSON)
    config.wifiSSID = doc["wifi"]["ssid"] | config.wifiSSID;
    config.wifiPassword = doc["wifi"]["password"] | config.wifiPassword;
    config.wifiTimeout = doc["wifi"]["timeout"] | config.wifiTimeout;

    // Load NTRIP config
    config.ntripHost = doc["ntrip"]["host"] | config.ntripHost;
    config.ntripPort = doc["ntrip"]["port"] | config.ntripPort;
    config.ntripMountpoint = doc["ntrip"]["mountpoint"] | config.ntripMountpoint;
    config.ntripUser = doc["ntrip"]["user"] | config.ntripUser;
    config.ntripPassword = doc["ntrip"]["password"] | config.ntripPassword;
    config.ntripTimeout = doc["ntrip"]["timeout"] | config.ntripTimeout;

    // Load GGA config
    config.ggaLatitude = doc["gga"]["latitude"] | config.ggaLatitude;
    config.ggaLongitude = doc["gga"]["longitude"] | config.ggaLongitude;
    config.ggaAltitude = doc["gga"]["altitude"] | config.ggaAltitude;
    config.ggaSendInterval = doc["gga"]["sendInterval"] | config.ggaSendInterval;

    // Load LoRa config
    config.loraFrequency = doc["lora"]["frequency"] | config.loraFrequency;
    config.loraSpreadingFactor = doc["lora"]["spreadingFactor"] | config.loraSpreadingFactor;
    config.loraBandwidth = doc["lora"]["bandwidth"] | config.loraBandwidth;
    config.loraCodingRate = doc["lora"]["codingRate"] | config.loraCodingRate;
    config.loraTxPower = doc["lora"]["txPower"] | config.loraTxPower;
    config.loraSyncWord = doc["lora"]["syncWord"] | config.loraSyncWord;
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

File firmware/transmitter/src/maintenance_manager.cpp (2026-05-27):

#include "maintenance_manager.h"
#include <LoRa.h>

// ==================== TLV tag constants ====================

#define MAINT_TLV_FREE_HEAP 0x02 // uint32 LE — free heap bytes

// ==================== Constructor / Destructor ====================

MaintenanceManager::MaintenanceManager(ConfigManager &configMgr,
                                       volatile SystemState *statePtr)
    : configManager(configMgr), statePtr(statePtr), lastMaintenanceTime(0),
      activeWindowStartTime(0), deferredStopTriggered(false),
      deferredStopCancelled(false), inStandbyRxMode(false)
{
    telemetryMutex = xSemaphoreCreateMutex();

    // Built-in TLV provider: free heap
    registerTLVField(MAINT_TLV_FREE_HEAP, [this](std::vector<uint8_t> &buf) {
        uint32_t heap = telemetry.free_heap; // read under tick() — mutex already taken
        buf.push_back(MAINT_TLV_FREE_HEAP);
        buf.push_back(4);
        buf.push_back((heap >> 0) & 0xFF);
        buf.push_back((heap >> 8) & 0xFF);
        buf.push_back((heap >> 16) & 0xFF);
        buf.push_back((heap >> 24) & 0xFF);
    });
}

MaintenanceManager::~MaintenanceManager()
{
    if (telemetryMutex)
        vSemaphoreDelete(telemetryMutex);
}

// ==================== Public API ====================

bool MaintenanceManager::isEnabled() const
{
    return configManager.getConfig().maintenance.enabled;
}

void MaintenanceManager::cancelDeferredStop()
{
    deferredStopCancelled = true;
#ifdef DEBUG
    Serial.println(F("[MAINT] Deferred stop cancelled by CMD_START — TX window disabled"));
#endif
}

void MaintenanceManager::registerCommand(MaintenanceCommand cmd,
                                         CommandHandler handler)
{
    commandHandlers[static_cast<uint8_t>(cmd)] = handler;
}

void MaintenanceManager::registerTLVField(
    uint8_t tag, std::function<void(std::vector<uint8_t> &)> provider)
{
    tlvProviders[tag] = provider;
}

void MaintenanceManager::updateTelemetry(const MaintenanceTelemetry &t)
{
    if (xSemaphoreTake(telemetryMutex, pdMS_TO_TICKS(5)) == pdTRUE)
    {
        telemetry = t;
        xSemaphoreGive(telemetryMutex);
    }
}

void MaintenanceManager::tick()
{
    // In standby, tickStandby() owns the LoRa radio and the maintenance cycle.
    // tick() must not touch state or transmit anything while standby is active.
    if (*statePtr == STATE_STANDBY)
        return;

    const SystemConfig &cfg = configManager.getConfig();

    // --- Deferred stop (requires maintenance.enabled — same channel for CMD_START) ---
    // Only active when not cancelled by a manual CMD_START
    if (cfg.maintenance.enabled && cfg.maintenance.deferredStopEnabled && !deferredStopCancelled && *statePtr == STATE_RUNNING)
    {
        // Reset timer each time we (re-)enter STATE_RUNNING after a stop
        if (activeWindowStartTime == 0 || deferredStopTriggered)
        {
            deferredStopTriggered = false;
            activeWindowStartTime = millis();
        }
        if (millis() - activeWindowStartTime >= cfg.maintenance.activeWindowMs)
        {
            deferredStopTriggered = true;
#ifdef DEBUG
            Serial.println(F("[MAINT] Active TX window expired — entering standby"));
#endif
            *statePtr = STATE_STANDBY;
            return;
        }
    }

    // --- Periodic maintenance frame ---
    if (!isEnabled())
        return;
    if (millis() - lastMaintenanceTime < cfg.maintenance.intervalMs)
        return;

    lastMaintenanceTime = millis();

    // --- Phase 1: TX maintenance frame ---
    if (statePtr)
        *statePtr = STATE_MAINTENANCE_TX;

    sendMaintenanceFrame();

    // --- Phase 2: RX listen window (only if rxWindowEnabled) ---
    if (cfg.maintenance.rxWindowEnabled)
    {
        if (statePtr)
            *statePtr = STATE_MAINTENANCE_RX;
        listenForCommands(cfg.maintenance.listenDurationMs);
    }

    // --- Done: resume normal operation ---
    if (statePtr)
        *statePtr = STATE_RUNNING;
}

// ==================== Public: standby tick (Core 0) ====================
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

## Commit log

2026-05-27 Initial commit: monorepo structure with receiver, transmitter, rover firmware and hardware
    [rover-B_Cu.gbr, rover-B_Mask.gbr, rover-B_Paste.gbr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]
2026-06-19 Restructure into monorepo: firmware (receiver/transmitter), hardware, scripts
    [rover-B_Cu.gbr, rover-B_Mask.gbr, rover-B_Paste.gbr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]
2026-06-19 some translations + BOMs
    [bom.csv]
2026-10-06 rover: web UI, runtime transport selection and WiFi setup window
    One firmware image now offers BLE NUS, Bluetooth SPP or WiFi TCP, chosen
    in a built-in web UI and stored in NVS, instead of two compile-time builds.
    - Refactor main.cpp into modules: bridge, logger, settings, wifi_manager,
    web_server, ota_service, telnet_service, system_control,
    transport_factory.
    - Add a TCP transport (raw NMEA out / RTCM in, port 10110, 2 clients).
    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
    [partitions.csv]
